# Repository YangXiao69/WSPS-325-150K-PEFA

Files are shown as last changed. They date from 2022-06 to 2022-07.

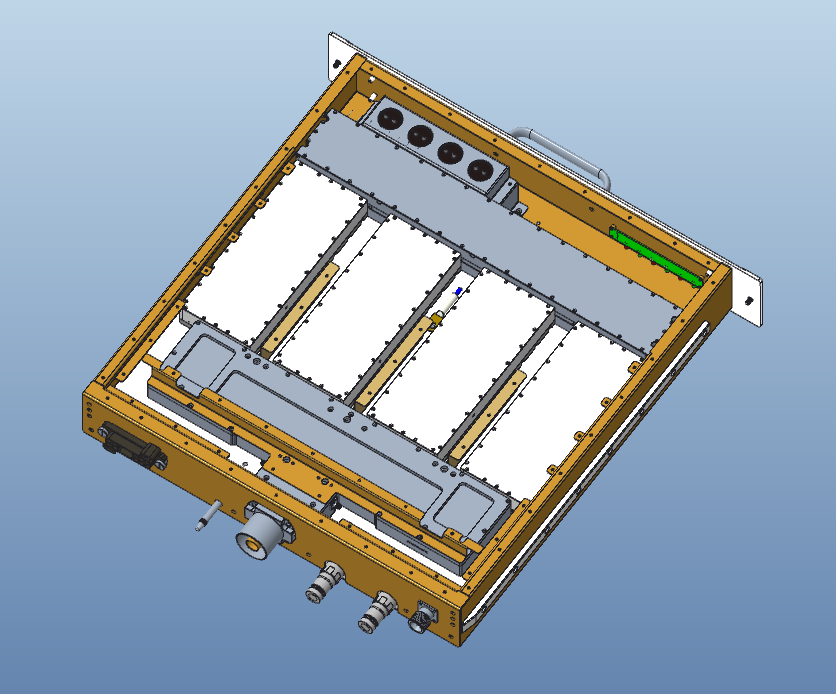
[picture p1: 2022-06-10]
接线图/功放插件/325-150KW功放插件截图/微信图片_20211231135349.png

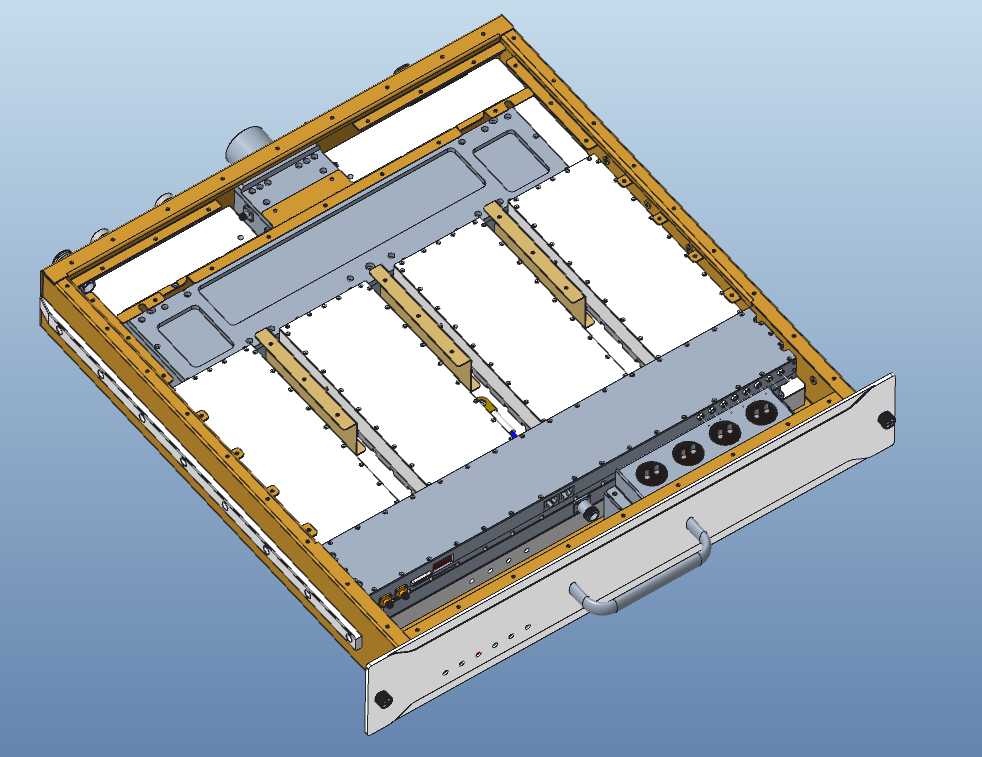
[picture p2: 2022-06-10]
接线图/功放插件/325-150KW功放插件截图/微信图片_20211231135400.png

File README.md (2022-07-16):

# WSPS-325-150K-PEF 开发记录

- 与昆仑通态组态屏交互协议
- pwm信号捕获
- 与工控机交互协议
- 激励温度采集

将udp的端口改为8096,**设想的插件通信方式，使用udp方式（可群发，可点对点），modbus协议，可脱离激励控制**

所有的校准参数保存到主控，保护判断也保存到主控

核达电源转接板，地址拨码开关左边是低位
## 问题

1. 激励级没有**拨码开关**
2. 主控和协处理器**飞线**
3. 工控机，交换机电源没有按接线图，功率是否足够

## 硬件问题
电磁阀驱动电阻过大 改为**10k**

流量计运放**飞线**

信号源修改

整机主控的UDP与驱动层的数据交互

## 数据分析

--->21   
<---01 00 09 C8 24 55 55 00 00 F4 00 00 93  
--->7F  
--->C1   
<---01   
--->00 04 C8 24 55 55 9A   
<---7F   
--->21   
<---01 00 09 C8 24 55 55 00 00 F4 00 00 93   
--->7F  
--->21   
<---73   
--->C1   
<---01   
--->00 04 C8 24 55 55 9A   
<---01 00 09 C8 24 55 55 00 00 F3 00 00 92   
--->7F  
--->21   
<---73   
--->C1

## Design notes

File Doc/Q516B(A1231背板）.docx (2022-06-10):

1. 尺寸图如下，以下两点尺寸没有变动

1）背板宽度与原背板保持相同；

2）安装螺钉孔位和开孔大小与原背板相同。

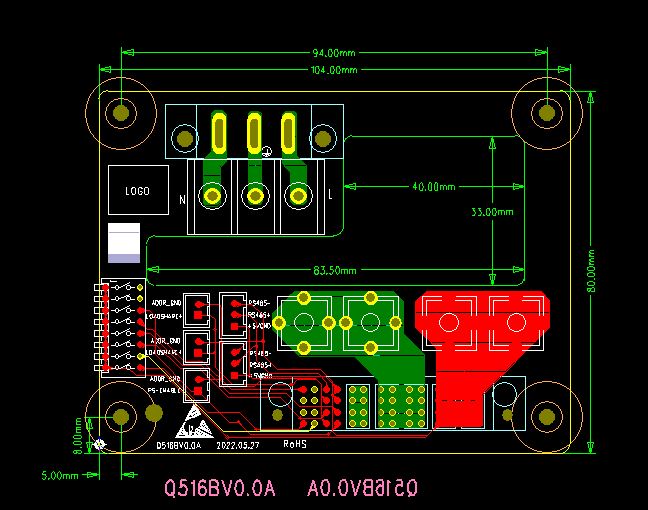
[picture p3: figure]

2. 接线布局如下（局部放大）

PCB板正面

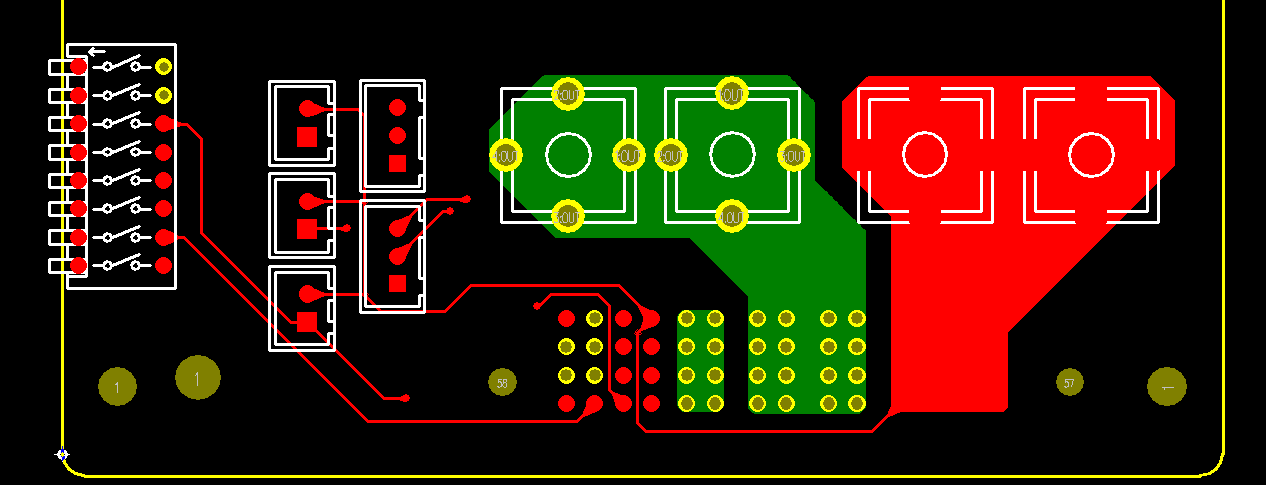
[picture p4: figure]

PCB板反面

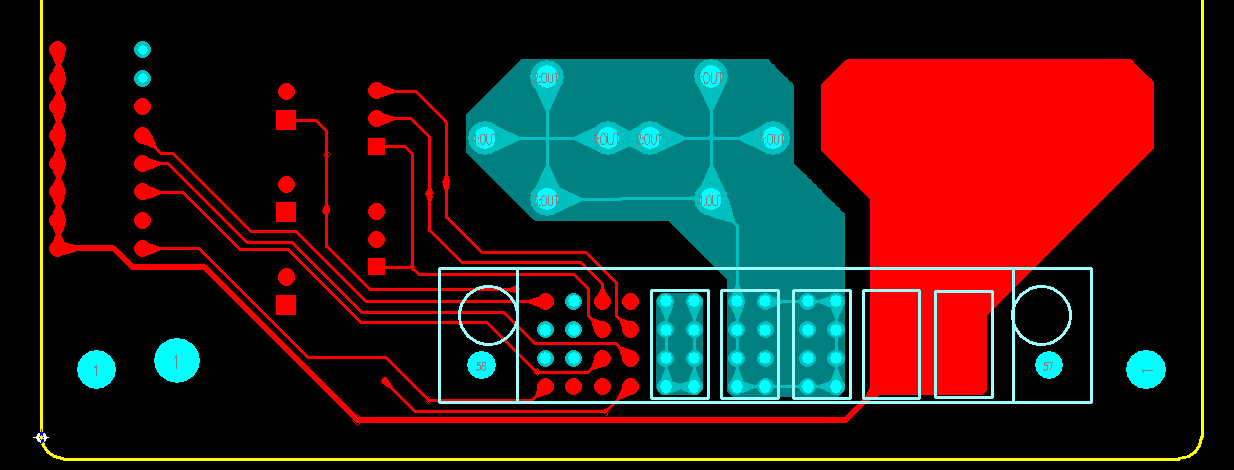
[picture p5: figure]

3. 弱电信号，单独留接口插座，地址码增加拨码开关（局部放大图如下）

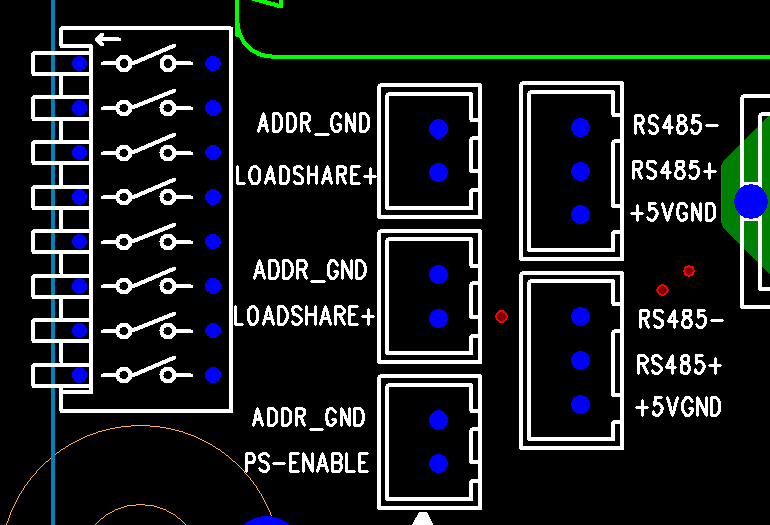
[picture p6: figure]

下图是3根485通讯线，两个座子之间相同信号互相短接（RS485+和RS485+短接、RS485-和RS485-短接、5VGND和5VGND短接）

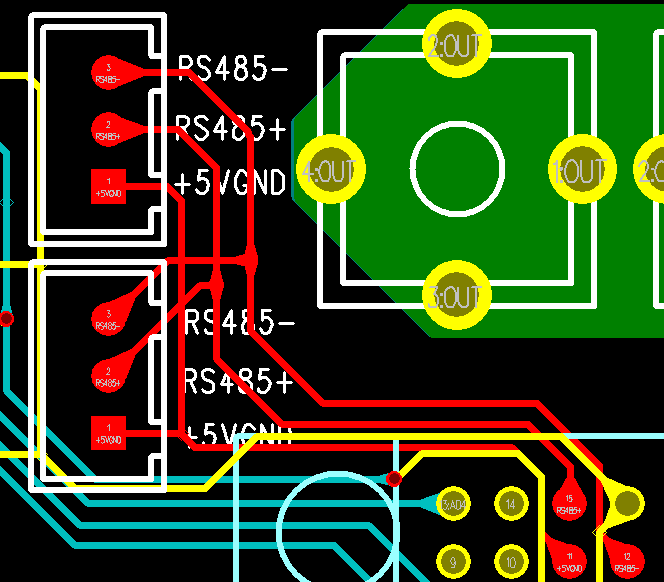
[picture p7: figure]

下图是2根均流母线电压线，同理也是LOADSHARE+与LOADSHARE+短接，ADDR-GND与ADDR-GND短接

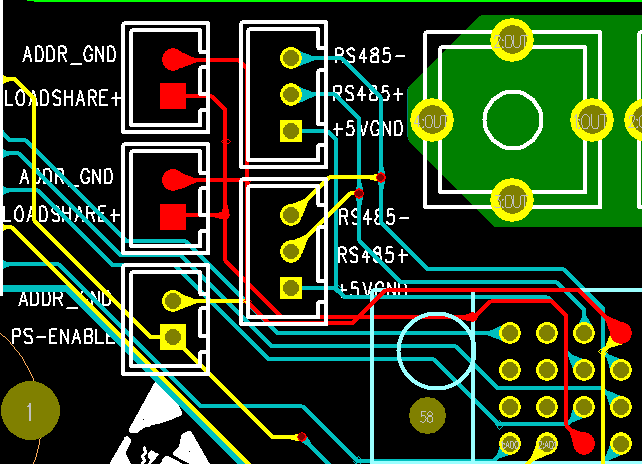
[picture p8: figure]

下图是5根地址线（A0-A4）接拨码开关

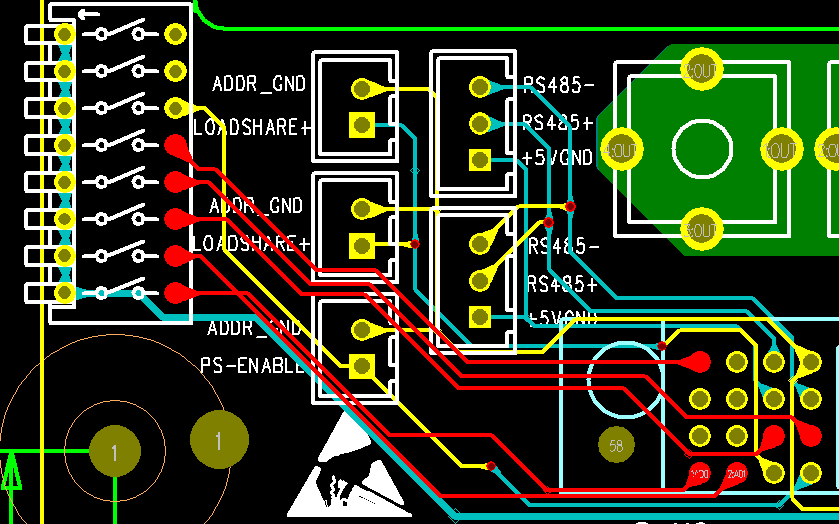
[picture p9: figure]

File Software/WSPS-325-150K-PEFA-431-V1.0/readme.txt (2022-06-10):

/**************2021.4.7 xiaoyang ************/
修改error_serve()函数：如果开启射频，再断电会导致电流误告警，所以将电流告警次数从20次增加到900次
/*******************************************/

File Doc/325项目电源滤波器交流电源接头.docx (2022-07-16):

325-150KW交流电源接头:

型号：插座：WP20K5Z 5芯 单芯载流：30A

插头：WP20J5TK 5芯 单芯载流：30A

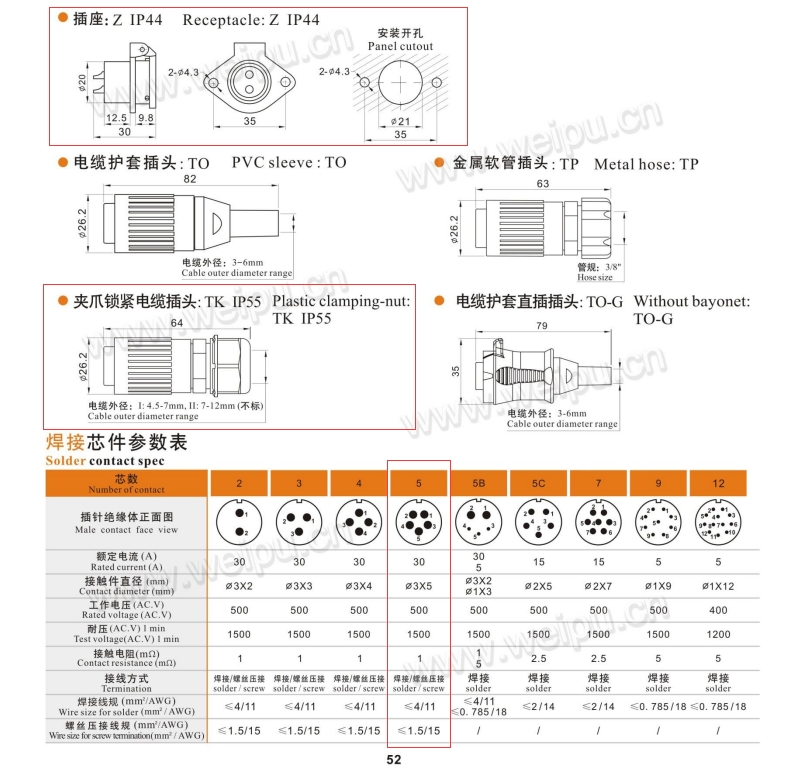
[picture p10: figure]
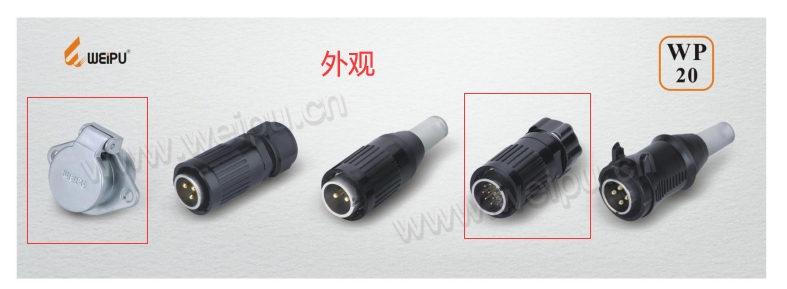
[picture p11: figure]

325-30KW交流电源接头:

型号：插座：WS48K5Z 5芯 单芯载流：100A

插头：WS48J5TQ 5芯 单芯载流：100A

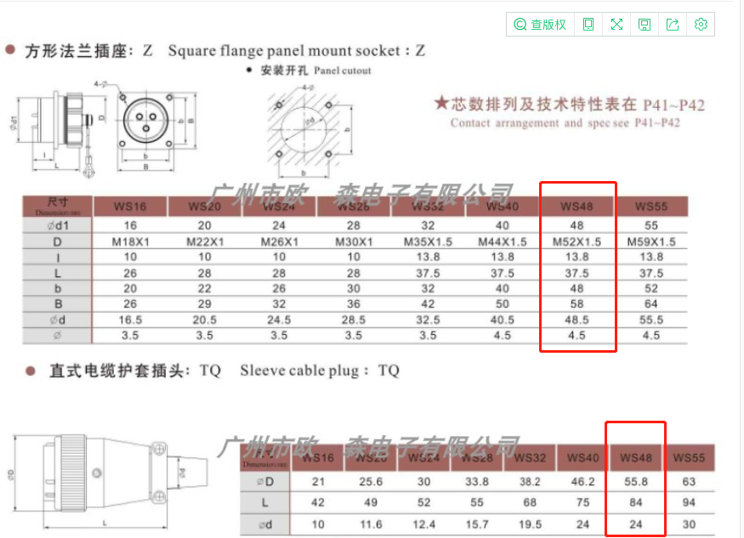
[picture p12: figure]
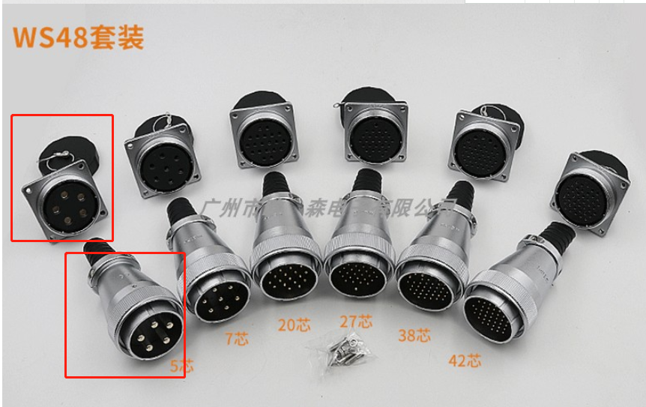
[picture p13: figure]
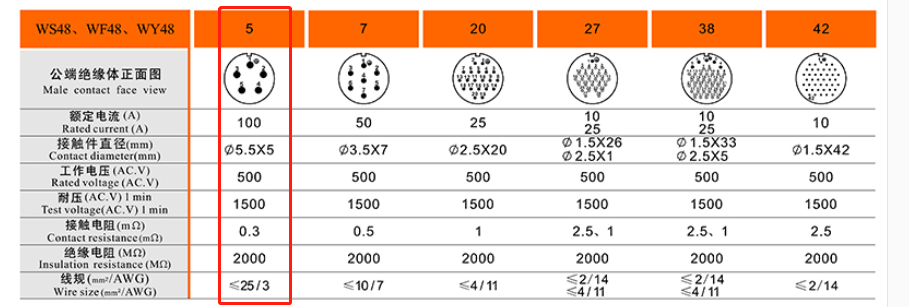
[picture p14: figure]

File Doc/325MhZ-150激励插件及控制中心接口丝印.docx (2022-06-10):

并柜总控单元结构示意图01

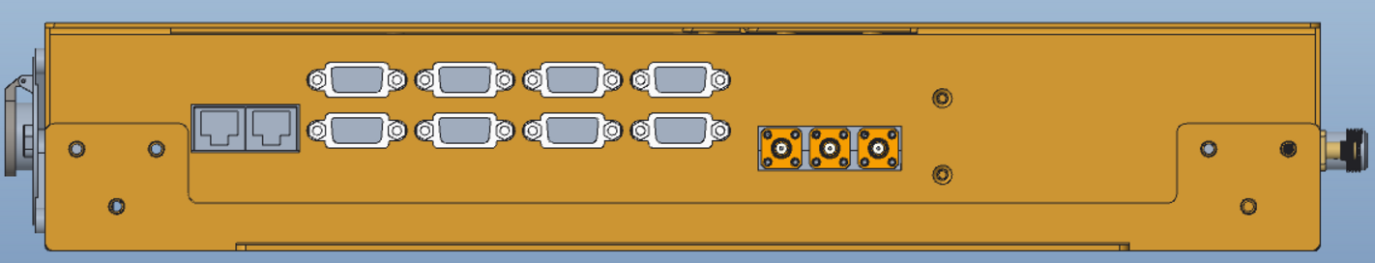
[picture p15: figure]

序号 | 丝印 | 连接器 | 描述
1 | LAN | RJ45 | 内部通信接口，接交换机
2 | LAN USER | RJ45 | 用户通信接口
3 | COMM1 | DB9双胞胎（上） | 机柜内部接口
4 | COMM2 | DB9双胞胎（下）
5 | COMM3 | DB9双胞胎（上） | 机柜内部接口
6 | COMM4 | DB9双胞胎（下）
7 | COMM5 | DB9双胞胎（上） | 机柜内部接口
8 | COMM6 | DB9双胞胎（下）
9 | COMM7 | DB9双胞胎（上） | 机柜内部接口
10 | COMM8 | DB9双胞胎（下）
11 | OPD | SMA | 整机输出检波口
12 | RPD | SMA | 整机反射检波口
13 | INPD | SMA | 整机输入检波口

并柜总控单元结构示意图02

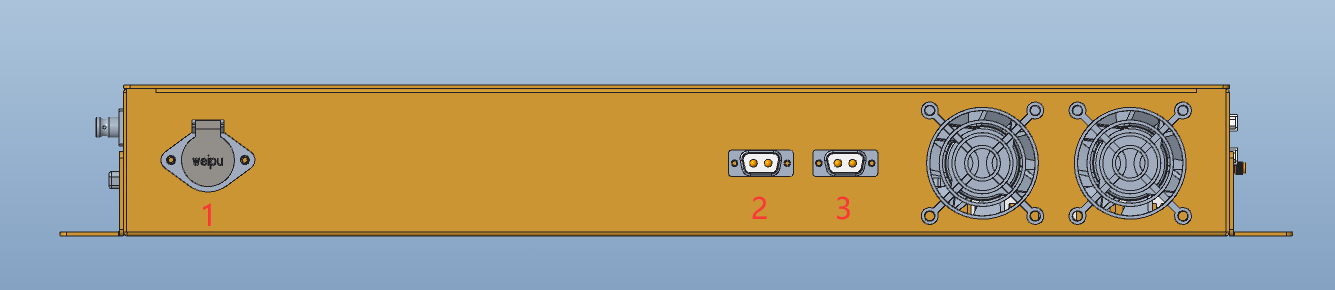
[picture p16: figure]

序号 | 丝印 | 连接器 | 描述
1 | AC IN | 航空插 | 交流供电输入接口
2 | 24VDC OUT1 | DB2 | 接工控机供电接口
3 | 24VDC OUT2 | DB2 | 接交换机供电接口

并柜总控单元结构示意图03

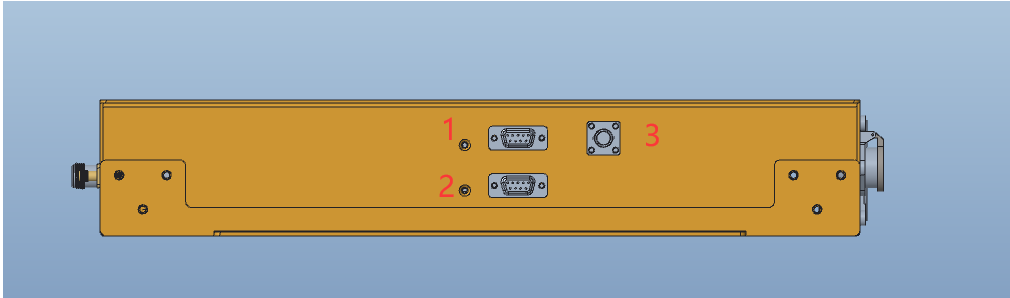
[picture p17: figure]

序号 | 丝印 | 定义 | 描述
1 | ALARM | DB9 | 一体三色告警灯
2 | COMM9 | DB9 | 预留
3 | PWM IN | BNC | PWM IN 输入

并柜总控单元结构示意图04

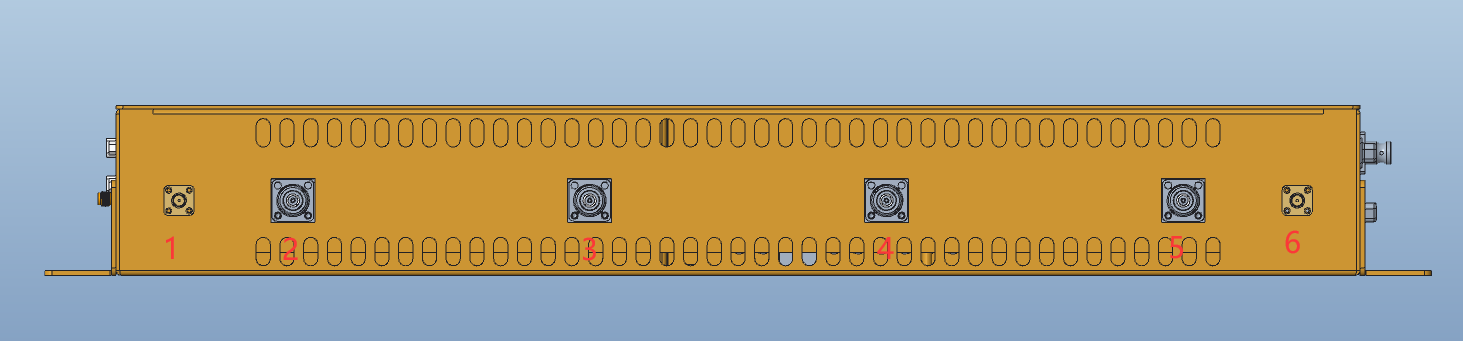
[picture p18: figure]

序号 | 丝印 | 定义 | 描述
1 | RF IN | SMA | 射频输入
2 | RF OUT1 | N头 | 射频输出
3 | RF OUT2 | N头 | 射频输出
4 | RF OUT3 | N头 | 射频输出
5 | RF OUT4 | N头 | 射频输出
6 | INPD OUT | SMA | 耦合输出口（接主控输入检波）

单柜激励插件

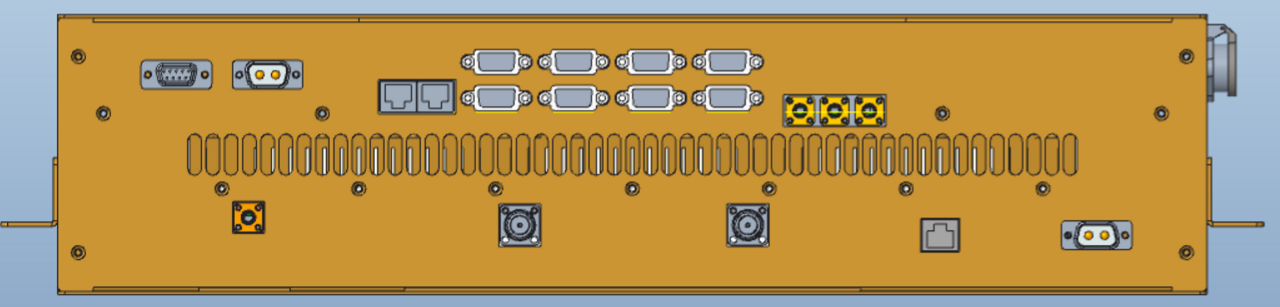
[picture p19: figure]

序号 | 丝印 | 连接器 | 描述
1 | STATE LED | DB9 | 3个金属灯
2 | 24VDC OUT | DB2 | 16口交换机
3 | LAN | RJ45 | 内部通信接口，接交换机
4 | LAN USER | RJ45 | 用户通信接口
5 | COMM1 | DB9双胞胎（上） | 机柜内部接口
6 | COMM2 | DB9双胞胎（下）
7 | COMM3 | DB9双胞胎（上） | 机柜内部接口
8 | COMM4 | DB9双胞胎（下）
9 | COMM5 | DB9双胞胎（上） | 机柜内部接口
10 | COMM6 | DB9双胞胎（下）
11 | COMM7 | DB9双胞胎（上） | 机柜内部接口
12 | COMM8 | DB9双胞胎（下）
13 | OPD | SMA | 单柜机柜输出检波口
14 | RPD | SMA | 单柜机柜反射检波口
15 | INPD | SMA | 预留

序号 | 丝印 | 定义 | 描述
1 | RF IN | SMA | 系统射频输入接口
2 | RF OUT1 | N | 射频输出
3 | RF OUT2 | N | 射频输出
4 | LAN | RJ45 | 接口板通信口，接16口交换机
5 | 50VDC IN | DB2 | 50V供电输入（驱动供电）

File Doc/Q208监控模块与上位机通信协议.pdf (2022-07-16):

## 深圳市核达中远通

电源技术有限公司 | 文 档 编 号 | 软件版本 | 文档密级
共 37 页 | | 1.00 | 机密

# 监控模块与上位机主从节点通讯协议

拟 | 制：吕志明
审 | 核：周友云
批 | 准：李战伟

第 2 页 共 49 页

目 录

第 3 页 共 49 页

第 4 页 共 49 页

第 5 页 共 49 页

## 监控模块与上位机主从节点通信协议

# 1 说明

本协议适用于各产品主控板（主节点）与电源系统监控模块（从节点）之间的通讯。

《协议》中规定的功能主要有：

1)主节点通过转发命令控制从节点完成指定任务；

2)主节点通过查询命令使从节点上报上电复位状态、告警信号改变后的告警量以及在转发命令

后从节点执行任务后的结果；

3)根据主节点的转发发命令执行指定任务，并将任务执行结果存于上报队列，等待主节点发送

查询命令时上报；

4)从节点将上电复位状态、告警信号改变后的告警量以及在转发命令时从节点执行任务后的上

报结果放在一个先进先出的上报队列中，每收到主节点发送的一个查询命令就返回上报队列中的第

一个信息，若上报队列为空，则返回无事响应字节（73H）。

通信的过程为单工、变长、双向应答确认方式进行，由主节点向从节点发送转发命令和查询命

令。每个转发命令和查询命令都作为一次双向通讯过程。多个从节点通过地址来区分，不同的从节

点对应不同的地址，不能有相同地址的从节点挂在同一条通讯总线上。

# 2 专用术语

主节点：业务框中的主控板，负责和各从节点进行通讯。也是上位机。

从节点：电源系统监控模块、风扇框中的监控板、直流配电框中的监控板均为从节点，它们和

主控板进行通讯。

RS422：一种 4 线串行通讯标准，可支持单工串行近程通讯；

转发命令：由主节点发向从节点使从节点完成指定任务的通讯格式；

查询命令：由主节点发向从节点使从节点返回上报队列中第一个消息的通讯格

式。

从节点地址：从节点地址用 5BIT 表示，可有 32 个不同的从节点地址。

第 6 页 共 49 页

# 3 物理接口

## 3.1 串行通信口电气标准

从节点以 RS422/RS232 方式通过主用串口或备用串口与主节点通讯

## 3.2 信息传输方式

采用异步方式，字节幀格式为：1个起始位，8个数据位，1个判断位，1个停止位。判断位为1

时表示地址幀，为0时表示数据幀。

字符信息传输方式为异步方式，1个起始位，8个数据位（信息字节），1个控制位（TB8），1

个停止位，共11位。 控制位可以是串口控制器的多机通信位TB8（8031），或是奇偶校验位（对大

多数 CPU 和 UART 芯片）。

从节点上报的数据第九位始终为0；

主节点的地址帧数据第九位为1，数据帧和应答数据第九位为0。

## 3.3 数据传输速率

波特率9600bps。

# 4 物理层通信方式

## 4.1 基本过程

·从节点上电或复位后，先清空上报队列，并把单板注册请求信息放于上报队列中，然后等待

主节点发出的查询命令，在成功收到主节点下发的注册响应命令之前，始终上报注册请求命令，注

册响应命令接收成功后，注册请求发送结束，以后不再产生此项上报信息。

·从节点接收到转发发命令时，将执行结果放在上报队列中。

·当告警状态发生变化时，从节点会产生一条告警状态改变上报信息放于上报队列中。

·接到查询命令后，若上报队列不空，则发送队列中第一个上报信息，否则发送无事响应（73H）。

·从节点通过主备两个串口与主节点通讯，上述过程对于主备串口将分别独立实现。

第 7 页 共 49 页

## 4.2 转发命令过程

转发命令过程如下：

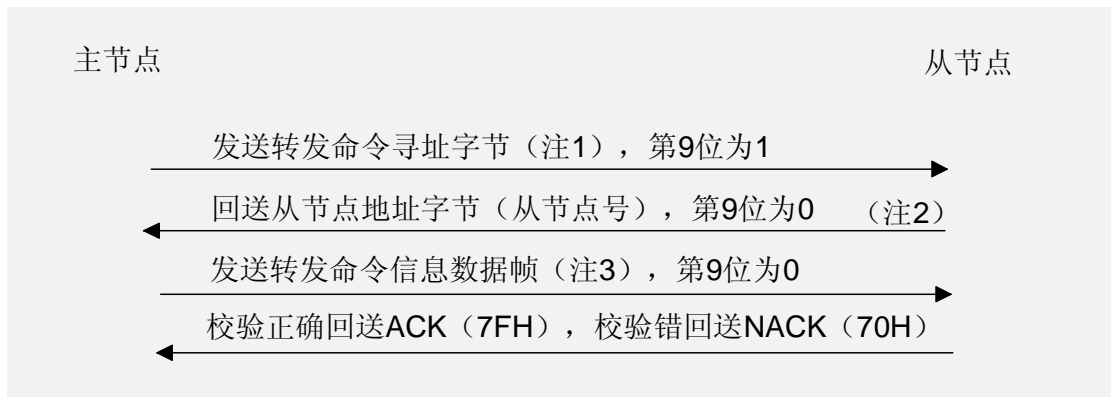
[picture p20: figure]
主节点; 从节点; 发送转发命令寻址字节（注1），第9位为1; 回送从节点地址字节（从节点号），第9位为0; 发送转发命令信息数据帧（注3），第9位为0; 校验正确回送ACK（7FH），校验错回送NACK（70H）

主节点下发转发命令寻址字节时，如果重发次数为0，则置转发命令高三位重发标志为“110”

表示为首次发送，否则为“111”表示为重发。

注1：命令寻址字节格式如下：
BIT： | 7 | 6 | 5 | 4 | 3 | 2 | 1 | 0
| | | | | | 从节点地址
1 | 1 | 0 首次发送
1 | 1 | 1 重发（非首次发送）

注2：回送从节点地址字节数据格式如下：
BIT： | 7 | 6 | 5 | 4 | 3 | 2 | 1 | 0
0 | 0 | 0 | 从节点地址

注3：转发命令信息数据帧格式如下：

| 长度 | 命令 | | | 信息域 | | | 校验字

其中：

长度：2 个字节的整形数，第一个字节为高位字节。指明 命令字 + 信息域 的长度。

命令： 2 个字节，命令的信息，第一个字节代表单板类型，定义如下：

| | | 电源模块：0xc8

第 8 页 共 49 页

电源系统监控模块：0xc9

风扇监控板：0xca

配电监控板：0xcb；

第二个代表命令定义。

Handle：2 个字节。

信息域：命令的信息域，第 1、2 个字节为 Handle 握手字。

校验字： 1 个字节，为长度、命令、 信息域的累加和。

从节点上电后，一直处于接收地址（第 9 位为 1）状态，收到地址后，与本机地址比较，若相

同并为转发命令，则回送本机地址，并转为接收数据（第 9 位为 0）状态；若相同并为查询命令，

则按查询处理；若不相同，则退出，仍然处于接收地址（第 9 位为 1）状态。

转发命令时，若从节点回送的地址不对或超时(10ms)不回送从节点地址，主机应重发，重发次

数以 3 次为限，3 次失败则判本次通信失败。

转发命令从节点接收数据时，只有在校验正确或校验错时才回送确认信息（ACK/NACK）；若

接收的长度和命令与协议定义的不符合，不回送信息，判本次通信失败，进入接收地址（第 9 位为

1）状态；若接收通信帧数据时收到地址（第 9 位为 1），判本次通信失败，并与本机的地址比较，

若相同并为转发命令，则按转发命令处理；若相同并为查询命令，则按查询命令处理；若不相同，

则退出，改为接收地址（第 9 位为 1）状态。

转发命令主节点发完数据帧后，准备接收从机的确认信息（ACK/NACK），如超时(10ms)或校

验错（NACK），判通信失败，主节点应从重发转发命令寻址字节开始，重新通信，重发次数以 3 次

为限，3 次失败则判本次通信失败。

## 4.3 查询命令过程

查询命令格式如下：

第 9 页 共 49 页

主节点下发查询命令寻址字节，从节点接到且是访问本机后，若无信息上报，则上报无事相应；

有信息上报，则取出一条上报，如果重发次数为0，则置数据帧地址字节高三位重发标志为“000”

表示首次上报，否则为“001”表示重报相应。

注4：查询命令寻址字节格式如下：
BIT： | 7 | 6 | 5 | 4 | 3 | 2 | 1 | 0
0 | 0 | 1 | 从节点地址

注5：上报信息数据帧格式如下：

上报地址 | 长度 | 命令 | 信息域 | 校验字

其中：

上报地址： 1 个字节。字节格式如下：
BIT： | 7 | 6 | 5 | 4 | 3 | 2 | 1 | 0

从节点地址

0 | 0 | 0 首次上报
0 | 0 | 1 重报（非首次上报）

长度： 2 个字节的整形数，第一个字节为高位字节，等于 命令字 + 信息域

命令： 2 个字节，命令的信息，第一个字节代表单板类型；第二个代表命令信息。

信息域： 命令的参数，第一个和第二个字节为 Handle 握手字节，由转发命令产生的上报信息

时为转发命令时的内容（填充时拷贝转发命令的握手字节），主动产生的上报信息为 0xffff。

校验字： 1 个字节，为长度、命令、 信息域的累加。

主节点 | 从节点

发送查询命令寻址字节（注4），第9位为1

回送上报信息数据帧，第9位为0（注5）

| 校验正确回送ACK（7FH），校验错回送NACK（70H）

结束

第 10 页 共 49 页

主节点下发查询命令寻址字节（第 9 位为 1）后，处于接收状态。接收等待超时 (10ms)，则重

新开始查询命令，重新通信，重发次数以 3 次为限，3 次失败则判本次通信失败。

主节点若接收的首字节不是无事响应字节，也不是当前的从节点号或重报标志不正确、或长度

字节非法、或命令字节非法，则重新开始查询命令，重新通信，重发次数以 3 次为限，3 次失败则

判本次通信失败。

主节点接收到第一个数据后，判断该数据为无事响应（73H），通信结束。若不是，则处于接收

数据状态，接收数据结束后，经校验出错，则回送确认校验错（NACK），并丢却接收的数据，置等

重报标志，重新处于接收状态，3 次失败则判本次通信失败。

主节点若接收到的数据，经校验正确，则回送确认校验对（ACK），通信结束。

从节点上电后，一直处于接收地址（第 9 位为 1）状态，收到地址后，与本机的地址比较，若

相同并为查询命令，单盘无事，则只回一个字节（73H），本次通信结束，进入接收地址（第 9 位为

1）状态。如单盘有消息上报，则发数据帧，发完后，须等待主节点回送确认信息（ACK/NACK）。

从节点等待确认信息时若收到确认校验对（ACK），本次通信结束，处于接收地址（第 9 位为 1）

状态；若收到确认校验错（NACK），则重发数据帧，发完后，须等待主节点回送确认信息

（ACK/NACK）；若收到其他数据，判通信失败，保留数据帧的信息，等待下次的查询，并改为处

于接收地址（第 9 位为 1）状态；若接收到第 9 位为 1 的单盘号，判通信失败，保留数据帧的信息，

并与本盘的地址比较，若相同并为查询命令，则按查询处理，若相同并为下发命令，则按下发命令

处理，若不相同，则退出，处于接收地址（第 9 位为 1）状态。

# 5 应用层信息类型及格式

## 5.1 命令编码

从节点与主节点的通讯共有两种命令编码即：

(a) 转发命令编码：在转发命令通讯过程中标识主节点要求从节点执行的任务内容
(b) 查询命令编码：在查询命令通讯过程中标识从节点返回主节点的上报信息内

容

第 11 页 共 49 页

转发命
令编码
含义 | 查询命 令编码

含义

电源系统监控模块命令字编码（公有命令）
0xc901 | 单板注册响应 | 0xc901 | 单板注册请求上报
0xc902 | 获取单板版本 | 0xc902 | 单板版本上报
0xc903 | 单板复位命令 | 0xc903 | 单板准备复位上报
电源系统监控模块命令字编码（私有命令）
0xc920 | 获取配电模拟量 | 0xc920 | 配电模拟量上报
0xc921 | 获取环境模拟量 | 0xc921 | 环境模拟量上报
0xc923 | 获取备用模拟量 | 0xc923 | 备用模拟量上报
0xc930 | 获取告警量 | 0xc930 | 告警量上报
0xc940 | 获取状态量 | 0xc940 | 状态量上报
0xc950 | 获取整流模块生产日期 | 0xc940 | 整流模块生产日期上报
0xc951 | 获取蓄电池充放电次数 | 0xc951 | 蓄电池充放电次数上报
0xc980 | 设置电源系统控制参数 | 0xc980 | 电源系统控制参数设置结果上报
0xc981 | 设置均浮充电压 | 0xc981 | 均浮充电压设置结果上报
0xc982 | 设置电池管理参数 | 0xc982 | 电池管理参数设置结果上报
0xc983 | 设置下电参数 | 0xc983 | 下电参数设置结果上报
0xc985 | 设置电池组温度补偿参数 | 0xc985 | 电池组温度补偿参数设置结果上报
0xc986 | 设置电源模块参数 | 0xc986 | 电源模块参数设置结果上报
0xc987 | 设置配电参数 | 0xc987 | 配电参数设置结果上报
0xc988 | 设置环境参数 | 0xc988 | 环境参数设置结果上报
0xc989 | 设置备用量参数 | 0xc989 | 备用量参数设置结果上报
0xc98a | 设置高温下电保护参数 | 0xc98a | 高温下电保护参数设置结果上报
0xc98b | 获取高温下电保护参数 | 0xc98b | 获取高温下电保护参数结果上报
0xc98c | 设置电池组容量检测参数 | 0xc98c | 电池组容量检测参数上报
0xc98d | 获取电池组容量检测参数 | 0xc98d | 电池组容量检测参数上报
0xc98e | 获取协议扩展参数 | 0xc98e | 协议扩展参数上报
0xc98f | 设置协议扩展参数 | 0xc98f | 协议扩展参数设置结果上报
0xc990 | 获取电源系统控制参数 | 0xc990 | 电源系统控制参数上报
0xc991 | 获取均浮充电压 | 0xc991 | 均浮充电压参数上报
0xc992 | 获取电池管理参数 | 0xc992 | 电池管理参数上报
0xc993 | 获取下电参数 | 0xc993 | 下电参数上报
0xc994 | 获取分流器参数 | 0xc994 | 分流器参数上报（2005-1-28 删除）
0xc995 | 获取电池组温度补偿参数 | 0xc995 | 电池组温度补偿参数上报
0xc996 | 获取电源模块参数 | 0xc996 | 电源模块参数上报
0xc997 | 获取配电参数 | 0xc997 | 配电参数上报

第 12 页 共 49 页

0xc998 | 获取环境参数 | 0xc998 | 环境参数上报
0xc999 | 获取备用量配置参数 | 0xc999 | 备用量配置参数上报
0xc99b | 设置电压测量参考基准 | 0xc99b | 设置电压测量参考基准结果上报
0xc99c | 设置配电模拟量校准系数 | 0xc99c | 设置配电模拟量校准系数结果上报
0xc99d | 启动或终止蓄电池立即测试 | 0xc99d | 启动或终止蓄电池立即测试结果上报
0xc99e | 设置各告警量告警级别 | 0xc99e | 设置各告警量告警级别结果上报
0xc99f | 获取各告警量告警级别 | 0xc99f | 各告警量告警级别上报
0xc9a0 | 获取电池放电测试结果 | 0xc9a0 | 电池放电测试结果上报
0xc9a1 | 获取配电模拟量校准系数 | 0xc9a1 | 配电模拟量校准系数上报
0xc9a2 | 获取单板生产日期和厂家信息 | 0xc9a2 | 获取单板生产日期和厂家信息上报
0xc9a3 | 设置当前时间 | 0xc9a3 | 设置当前时间结果上报
0xc9a4 | 获取当前时间 | 0xc9a4 | 当前时间上报
0xc9a5 | 设置蓄电池安装时间 | 0xc9a5 | 设置蓄电池安装时间上报
0xc9a6 | 获取蓄电池安装时间 | 0xc9a6 | 蓄电池安装时间上报
0xc9aa | 配置参数恢复缺省值 | 0xc9aa | 恢复缺省值结果上报
0xc9ab | 设置蓄电池自动测试参数 | 0xc9ab | 设置蓄电池自动测试参数上报
0xc9ac | 查询蓄电池自动测试参数 | 0xc9ab | 查询蓄电池自动测试参数上报
0xc9ad | 烟雾告警复位命令 | 0xc9ad | 烟雾告警准备复位上报
0xc9ae | 关闭或复位电源输出命令 | 0xc9ae | 准备关闭或复位电源输出上报
0xc9af | 设置电源系统参数 | 0xc9af | 设置电源系统参数结果上报
0xc9b0 | 获取电源系统参数 | 0xc9b0 | 获取电源系统参数结果上报

注：0xc9f8～0xc9fe预留给供应商进行内部命令设置，协议不能占用。其中0xc9f8作为整流模块输

出信息查询，具体定义参加附录I。2005-10-19增加

第 13 页 共 49 页

信息域的数据格式

在转发命令中，信息域提供了命令执行的具体参数；在查询命令中，信息域包含了所需上报的具体

数据。

信息域中的数据由单字节数(8Bits)、浮点数(32Bits，数据格式为附录A规定的标准C浮点数格式)组成，

按发送的先后次序依次存放。应当注意的是：在传送浮点数时，按阶码字节、尾数高位字节、尾数

中位字节、尾数低位字节顺序发送；所有字节都按十六进制方式直接发送。

为了简化参数设置和控制命令的执行过程，除了特别说明的命令外，规定若参数域中的某数据为

0xff(单字节数)或0xffffffff(四字节浮点数)，则表示本次命令不涉及此数据对应的信号或配置参

数，该信号的状态或该项配置参数保持不变。

所有命令中定义为保留的字节和数据规定为0xff(单字节数)或0xffffffff(四字节浮点数)。

对于主节点下发设置和控制命令，除该命令有特殊说明外，从节点返回值定义如下：

0：执行成功

1：数据无效（包括命令ID无法识别和参数错误）

2：操作失败（如写EEPROM芯片失败、无权限获取等）。

# 6 信息格式

## 6.1 电源监控模块命令

## 6.1.1 单板注册请求

在单板上电或单板复位重新启动后，主动产生本命令，产生的上报命令，放入单板的发送队列，

等收到主节点的查询命令后，再上报。主节点依照这条命令，获知单板复位完成和单板状态，并通

过转发命令向单板下发注册响应命令。当单板没有收到注册响应转发命令之前，对于主节点的查询

命令始终上报单板注册请求命令。单板接收到注册响应转发命令成功后以后不再上报注册请求命

令。

转发命令 | 命令 | 0xc901 | 长度 | 0x0004
| 信息域 | Handle 握手字（2 个字节）
查询命令 | 命令 | 0xc901 | 长度 | 0x000d

第 14 页 共 49 页

信息域 | 握手字（2 个字节，0xffff）； 应答结果（1 个字节）； 单板自检状态（1 个字节，0x00，表示好，其它，表示坏）； 电源系统类型（1 字节）； 软件小版本号（1 个字节）； 硬件 PCB 版本号（1 个字节）； 硬件可编程器件版本号（1 个字节）； 编译时间年（1 个字节）； 编译时间月（1 个字节）； 编译时间日（1 个字节）

说明：

在查询命令的信息域中规定：

电源系统类型：填“1”代表-48V电源系统；填“2”代表24V电源系统。

软件小版本号：填大于等于0的值，首次发布版本填0，第二次为1，类推；应用时，主节点（主控

板）需按照下表进行解析：

从节点（电源监控板）软件版本格式 | 主节点（主控板）解析显示格式
软件大版本 | 软件小版本
1 | 01～0f | 101~115
1 | 10~ | 116

硬件的PCB版本在没有归档之前填“A”（“0”2005-1-26删除），首次归档填“A”，按照A，B，C……

的方式递增。

硬件可编程器件版本（EPLD，CPLD，FPGA等）：首次发布版本为1，按照1，2，3……的方式递增。

编译时间：十六进制格式，其中“编译时间年”取年份的最后两位数字。

## 6.1.2 获取单板版本信息

在主节点向从节点发获取单板版本下发命令后，从节点产生一条单板版本信息上报命令，放入

发送队列，在收到主节点的查询命令后上报。

转发命令 | 命令 | 0xc902 | 长度 | 0x0004
| 信息域 | 握手字（2 个字节）
查询命令 | 命令 | 0xc902 | 长度 | 0x002d

第 15 页 共 49 页

信息域 | 握手字（2 个字节）； 应答结果（1 个字节）； 软件大版本号（1 个字节）； 软件小版本号（1 个字节）； 硬件 PCB 版本号（1 个字节）； 硬件可编程器件版本号（1 个字节）； 编译时间年（1 个字节）； 编译时间月（1 个字节）； 编译时间日（1 个字节）； 版本说明（32 个字节）； 厂家类型（1 个字节）

说明：

1、其中版本说明、编译时间和注册命令中的一致；

2、版本说明为附加的单板说明信息，可自由定义。

3、厂家类型：填入厂家的代码。

## 6.1.3单板复位命令

由主节点向从节点发单板复位转发命令。

从节点在收到主节点发的单板复位转发命令后，产生一条上报命令，等主节点发查询命令时上

报，上报成功后开始复位。

转发命令 | 命令 | 0xc903 | 长度 | 0x0004
| 信息域 | 握手字（2 个字节）
查询命令 | 命令 | 0xc903 | 长度 | x0005
| 信息域 | 握手字（2 个字节）；应答结果（1 个字节）

## 6.1.4 获取配电模拟参数

主节点向从节点发获取配电模拟参数转发命令。

从节点在收到主节点发的获取配电模拟参数转发命令后，产生一条配电模拟参数上报命令，等

主节点发查询命令时上报。

转发命令 | 命令 | 0xc920 | 长度 | 0x0004
| 信息域 | 握手字（2 个字节）
查询命令 | 命令 | 0xc920 | 长度 | 0x0019

第 16 页 共 49 页

信息域 | 握手字（2 个字节）； 应答结果（1 个字节）； 母排电压（4 字节浮点数）；负载总电流（4 字节浮点数）；蓄电池组 1 电 流（4 字节浮点数）；蓄电池组 2 电流（保留，4 个字节）；交 流电压（4 字节浮点数）；

## 6.1.5 获取环境模拟参数

主节点向从节点发获取环境模拟参数转发命令。

从节点在收到主节点发的获取环境模拟参数转发命令后，产生一条环境模拟参数上报命令，等

主节点发查询命令时上报。

转发命令 | 命令 | 0xc921 | 长度 | 0x0004
| 信息域 | 握手字（2 个字节）
查询命令 | 命令 | 0xc921 | 长度 | 0x0021
| 信息域 | 握手字（2 个字节）； 应答结果（1 个字节）；电池组温度 1 （4 字节浮点数）；环境温度 1（4 字节浮点数）；环境湿度（4 字节浮点数）；环境温度 2（保留，4 字节浮点数）（2005-10-19 更改），电池组温度 2（4 字节浮点数）；保留（8 个字节）

注：温度传感器无效时，模拟量上报0xffffffff。

## 6.1.6 获取备用模拟量参数

主节点向从节点发获取备用模拟参数转发命令。

从节点在收到主节点发的获取备用模拟参数转发命令后，产生一条备用模拟参数上报命令，等

主节点发查询命令时上报。备用模拟参数主要用于调试和功能扩充。

转发命令 | 命令 | 0xc923 | 长度 | 0x0004
| 信息域 | 握手字（2 个字节）
查询命令 | 命令 | 0xc923 | 长度 | 0x002d
| 信息域 | 握手字（2 个字节）； 应答结果（1 个字节）； 备用 1（4 字 节浮点数）；备用 2（4 字节浮点数）；备用 3（4 字节浮点数）； 备用 4（4 字节浮点数）；备用 5（4 字节浮点数）；备用 6（4 字节浮点数）；备用 7（4 字节浮点数）；备用 8（4 字节浮点 数）；备用 9（4 字节浮点数）；备用 10（4 字节浮点数）

注意：备用 1－限流点电流；备用 2－后台控制整流模块的输出电压；其它保留。

## 6.1.7 获取告警量

主节点向从节点发获取告警状态转发命令。

从节点上电或复位重启后，产生一条告警状态上报命令；或者从节点在收到主节点发的获取告

第 17 页 共 49 页

警状态转发命令后，产生一条告警状态上报命令；另外，从节点在检测到告警状态发生变化后，也

应产生一条告警状态上报命令。产生的告警状态上报命令，放入单板的发送队列，等收到主节点的

查询命令后，再上报。

下发命令 | 命令 | 0xc930 | 长度 | 0x0004
| 信息域 | 握手字（2 个字节）
查询命令 | 命令 | 0xc930 | 长度 | 0x002B
信息域 | 握手字（2 个字节）；应答结果（1 个字节）；市电状态（1 个字 节）；市电过欠压（1 个字节）；母排电压过欠压（1 个字节）； 负载上下电（1 个字节）；电池上下电（1 个字节）；电池组回路 通断（1 个字节）；环境温度 1 告警（1 个字节）；环境湿度告警 （1 个字节）；电池组温度告警（1 个字节）；门磁告警（1 个字 节）；水浸告警（1 个字节）；烟感告警（1 个字节）；系统插框 槽位 1-10 电源模块告警（每个模块 1 个字节，共 10 字节）；充 电过流告警(1 个字节)；交流防雷故障（保留，1 个字节）；传感 器有效状态（1 个字节， BIT0－BIT4 分别对应电池组温度 1、环 境湿度、环境温度 1、环境温度 2、电池组温度 2，0 表示正常，1 表示无效；BIT5－BIT7 保留）；备用模拟量告警（1 个字节，用 于蓄电池不平衡告警）；开关量告警 1（1 个字节， BIT0—BIT6 分别对应备用开关量 1—7 状态，0 表示正常，1 表示告警；BIT7 保留）；开关量告警 2（1 个字节，BIT0—BIT3 分别表示负载熔 丝告警，0 表示正常，1 表示告警，BIT4～BIT7 保留）；保留（10 个字节）环境温度 2告警（1个字节）；保留（9个字节）（2005-10-19 更改）

注：

1、报警状态的信息域字节位定义见附录C（重点注意负载上下电和电池上下电告警定义）

2、电池组温度告警参考温度以蓄电池组温度补偿依据的温度为准。

## 6.1.8获取状态量

主节点向从节点发获取状态量转发命令。

从节点上电或复位重启后，产生一条状态量上报命令；或者从节点在收到主节点发的获取状态

量转发命令后，产生一条状态量上报命令；另外，状态量发生变化后，产生一条状态量上报命令。

产生的状态上报命令，放入单板的发送队列，等主节点发查询命令时上报。

下发命令 | 命令 | 0xc940 | 长度 | 0x0004
| 信息域 | 握手字（2 个字节）
查询命令 | 命令 | 0xc940 | 长度 | 0x002b

第 18 页 共 49 页

信息域 | 握手字（2 个字节）； 应答结果（1 个字节）；限流状态 （1 个字节）；电源系统控制命令受控状态（1 个字节）； 充放电状态（1 个字节）；负载下电允许状态（1 个字节）； 电池下电允许状态（1 个字节）；电池放电测试阶段（1 字节）；电源模块类型（1 个字节）；电源模块数量（1 个字节）；电源模块 1-10 插槽位置（保留，每个模块 1 个字节，共 10 字节）；保留（20 个字节）

注：信息域状态定义见附录B

未配置蓄电池时，充放电状态应为浮充。2005-6-30

## 6.1.9 获取整流模块生产日期

主节点向从节点发获取整流模块生产日期转发命令。

从节点在收到主节点发的获取整流模块生产日期转发命令后，产生一条整流模块生产日期上报

命令；产生的整流模块生产日期上报命令，放入单板的发送队列，等收到主节点的查询命令后，再

上报。

下发命令 | 命令 | 0xc950 | 长度 | 0x0004
| 信息域 | 握手字（2 个字节）
查询命令 | 命令 | 0xc950 | 长度 | 0x0037
| 信息域 | 握手字（2 个字节）；应答结果（1 个字节）；整流模块生产日期 （共 50 个字节，整流模块槽位 1 个字节，生产日期 3 个字节，生 产厂家编码 1 个字节，共 10 个整流模块）

注：信息域。定义见附录D。

## 6.1.10获取蓄电池充放电次数

主节点向从节点发获取蓄电池充放电次数转发命令。

从节点在收到主节点发的获取蓄电池充放电次数转发命令后，产生一条蓄电池充放电次数上报

命令；产生的蓄电池充放电次数上报命令，放入单板的发送队列，等收到主节点的查询命令后，再

上报。

下发命令 | 命令 | 0xc951 | 长度 | 0x0004
| 信息域 | 握手字（2 个字节）
查询命令 | 命令 | 0xc950 | 长度 | 0x002f
| 信息域 | 握手字（2 个字节）；应答结果（1 个字节）；蓄电池充放电次数 （42 个字节，停电次数 2 个字节，充电次数 20 个字节，放电次 数 20 个字节）

第 19 页 共 49 页

注：信息域定义见附录E。

## 6.1.11设置电源系统控制参数

主节点通过向从节点发设置均浮充等控制参数命令，设置从节点的均浮充受控状态、受后台控

制时的充电状态等。

从节点接收成功后根据转发命令参数域信息设置相应参数，并产生一条应答上报命令，放入发

送队列，等收到主节点的查询命令后，再将设置结果上报。

下发命令 | 命令 | 0xc980 | 长度 | 0x001c
| 信息域 | 握手字（2 个字节）；受控状态（1 个字节，AAH－主节点控制， 55H－从节点自动控制）；充电状态（1 个字节，AAH－均充，55H －浮充）；负载上下电控制(1 个字节，AAH-下电，55H-上电)； 电 池上下电控制(1 个字节，AAH-下电状态，55H-上电状态)；电源 模块开关机命令（1 个字节，AAH-关机；55H-开机）；保留（19 个字节）
查询命令 | 命令 | 0xc980 | 长度 | 0x0005
| 信息域 | 握手字（2 个字节）；应答结果（1 个字节）

注：

1、 电池放电测试期间不可以修改电源系统受控状态，反馈配置失败。

2、 从节点自动控制状态设置均充或者下电或者关机时返回配置参数无效。

3、 主节点控制状态但禁止下电时下发下电控制命令返回配置参数无效。

4、 对负载高温下电说明如下（2005-3-26 增加）：

前提条件：监控模块不自动进行负载的高温下电保护，负载高温下电只能由后台（或上位机）控制下电。

⑴上位机检测到负载温度过高时，必须首先获得监控模块的后台控制权，然后使能负载下电允许。

⑵后台下发负载下电命令，监控模块收到下电命令后无条件进行负载下电。（不管是高温还是常温）

⑶当监控模块和上位机通讯正常时，下电后的监控模块控制负载再次上电的权利由上位机控制，监控模块即使检测

到负载温度（暂定为环境温度1）低于负载高温保护温度10度以下也不会进行负载上电。

⑷当监控模块与上位机通讯断连时，监控模块首先判断是否负载高温下电使能（用于判断是否为高温负载下电），

如果禁止（非高温负载下电），则监控模块不进行负载上电。如果允许（是高温下电），则由监控模块检测负载温

度，一旦负载温度低于负载高温保护温度10度以下，则自动进行负载上电。

5、 主节点控制转到从节点控制的参数补充说明：

当从主节点控制方式转为从节点自动控制方式时，监控模块只接受该下发命令的受控状态参数，其

第 20 页 共 49 页

他参数均忽略。2005-6-28

## 6.1.12设置均浮充电压

主节点通过向从节点发设置均浮充电压转发命令，设置从节点的均浮充电压。

从节点接收成功后根据转发命令参数域信息设置相应参数，并产生一条应答上报命令，放入发

送队列，等收到主节点的查询命令后，再将设置结果上报。

下发命令 | 命令 | 0xc981 | 长度 | 0x000c
| 信息域 | 握手字（2 个字节）；均充电压（4 字节浮点数，有效范围 43.2~57.6， 且大于浮充电压小于直流过压告警点-1V，缺省 56.5V）；浮充电 压（4 字节浮点数，有效范围 43.2~57.6，且大于(直流欠压告警 点+2)V 小于均充电压，缺省 53.5V）
查询命令 | 命令 | 0xc981 | 长度 | 0x0005
| 信息域 | 握手字（2 个字节）；应答结果（1 个字节）

## 6.1.13设置电池管理参数

主节点通过向从节点发设置电池管理参数转发命令，设置从节点的电池管理参数。

从节点接收成功后根据转发命令参数域信息设置相应参数，并产生一条应答上报命令，放入发

送队列，等收到主节点的查询命令后，再将设置结果上报。

下发命令 | 命令 | 0xc982 | 长度 | 0x0012
| 信息域 | 握手字（2 个字节）；充电限流点系数（4 字节浮点数，有效范围 0.05~0.25，缺省 0.15）；电池组 1 容量（4 字节浮点数，有效范 围 30~1000，缺省 65AH）；电池组 2 容量（4 个字节，保留）； 电 池组路数（1 个字节，有效范围 0~1，缺省 1）；定时均充时间（1 个字节，有效范围 30~240 天，缺省 60 天）
查询命令 | 命令 | 0xc982 | 长度 | 0x0005
| 信息域 | 握手字（2 个字节）；应答结果（1 个字节）

注：

1、 对于有两个电池接入端子的系统，因共用一个分流器，要求将电池组容量设为两路电池容

量之和，电池组路数设为 1。

2、 电池测试期间不可以修改电池管理参数，反馈配置失败。

3、 电池组数量为 0 时不接收其他参数设置

4、 定时均充的结束判据见监控模块规格书。

第 21 页 共 49 页

## 6.1.14设置下电参数

主节点通过向从节点发设置下电参数转发命令，设置从节点的下电参数。

从节点接收成功后根据转发命令参数域信息设置相应参数，并产生一条应答上报命令，放入发

送队列，等收到主节点的查询命令后，再将设置结果上报。

下发命令 | 命令 | 0xc983 | 长度 | 0x0013
| 信息域 | 握手字（2 个字节）；负载下电允许状态（1 个字节，AAH－允许， 55H－禁止，缺省 55H）；电池下电允许状态（1 个字节，AAH－允 许，55H－禁止，缺省 AAH）；负载下电电压（4 字节浮点数，有 效范围电池下电电压~直流欠压告警点，缺省 44V）； 电池组下 电电压（4 字节浮点数，有效范围 35V~负载下电电压，缺省 43V）； 低温启动负载下电允许状态（1 个字节，AAH－允许，55H－禁止， 缺省 55H）；低温启动负载下电温度（4 字节浮点数，有效范围 -40~0℃，缺省-10℃）
查询命令 | 命令 | 0xc983 | 长度 | 0x0005
| 信息域 | 握手字（2 个字节）；应答结果（1 个字节）

## 6.1.15 设置电池组温度补偿参数（05-1-26 修改）

主节点通过向从节点发设置电池组温度补偿参数转发命令，设置从节点的电池组温度补偿参

数。

从节点接收成功后根据转发命令参数域信息设置相应参数，并产生一条应答上报命令，放入发

送队列，等收到主节点的查询命令后，再将设置结果上报。

下发命令 | 命令 | 0xc985 | 长度 | 0x0029

第 22 页 共 49 页

| 信息域 | 握手字（2 个字节）；电池组温度 1 传感器测量上限（4 字节浮点 数，为传感器输出 20mA 信号对应的温度值，有效设置范围 0~100 ℃，缺省值为 80 ℃）；电池组温度 1 传感器测量下限（4 字节浮 点数，为传感器输出 4mA 信号对应的温度值，有效设置范围-50 ℃~0，缺省值为-20 ℃。）；电池组温度 1 过高告警点（4 字节 浮点数，有效设置范围-50~100℃，缺省值为 50℃）；电池组温 度 1 过低告警点（4 字节浮点数，有效设置范围-50~100℃，且小 于过高告警点，缺省值为 0℃）；电池组温度 2 传感器测量上限 （4 字节浮点数）；电池组温度 2 传感器测量下限（4 字节浮点数）； 电池组温度 2 过高告警点（4 字节浮点数）；电池组温度 2 过低 告警点（4 字节浮点数）； 温度补偿系数（4 字节浮点数；为电池组温度每变化 1 ℃电池组 浮充电压变化值，有效设置范围 0~500mV。缺省值为 80mV）；电 池组温度补偿依据的温度（1 个字节，AAH-电池组温度 1，55H-电池组温度 2，缺省值为 AAH）
查询命令 | 命令 | 0xc985 | 长度 | 0x0005
| 信息域 | 握手字（2 个字节）；应答结果（1 个字节）

注：1、电池组温度 2 的设置参数定义与电池组温度 1 相同。

2、温度补偿后的浮充电压有如下限制：下限不低于设置的浮充电压-2V，上限不超过均充电压。

2005-6-30

## 6.1.16设置电源模块参数

主节点通过向从节点发设置电源模块参数转发命令，设置从节点的电源模块参数。

从节点接收成功后根据转发命令参数域信息设置相应参数，并产生一条应答上报命令，放入发

送队列，等收到主节点的查询命令后，再将设置结果上报。

下发命令 | 命令 | 0xc986 | 长度 | 0x000f
| 信息域 | 握手字（2 个字节）；电源模块数量（1 个字节，有效范围 0～10， 缺省 9）； 电源模块 1～10 插槽位置（每模块 1 个字节，共 10 字节，有效范围 1～10, 不可重复）（参见附录 B）
查询命令 | 命令 | 0xc986 | 长度 | 0x0005
| 信息域 | 握手字（2 个字节）；应答结果（1 个字节）

注：

1、电池测试期间，不可以将电源模块数量设为 0，反馈配置失败。

2、电源模块数量最大可设为 10 是为了以后可兼容可能的配 10 个模块的电源系统，后台设置时要

求下发的配置数不超过实际系统允许的最大模块数。插槽位置的配置排列顺序固定，需配置的插槽

第 23 页 共 49 页

位置配置对应的数字，不需配置的插槽位置配置 0xAA。（2005/6/20 增加）

3、监控模块需要自动检测系统在线模块，说明如下：

A、当监控模块检测到没有配置的整流模块（包括模块正常工作、模块保护或模块故障）时，一概

上报该位置的模块非法，但进行正常管理。

B、当用户拔掉一个非法模块或非法模块通讯失败时，自动删除该模块而不上报模块通讯故障。（正

常配置的模块出现通讯故障或被拔掉时，需要上报该位置的模块通讯故障）

C、除说明 1 所列条件外，上位机的配置命令必须接受，包括删除正常工作模块（删除后可上报非

法模块）等操作。

## 6.1.17设置配电参数

主节点通过向从节点发设置配电参数转发命令，设置从节点的配电参数。

从节点接收成功后根据转发命令参数域信息设置相应参数，并产生一条应答上报命令，放入发

送队列，等收到主节点的查询命令后，再将设置结果上报。

下发命令 | 命令 | 0xc987 | 长度 | 0x0014
| 信息域 | 握手字（2 个字节）；交流过压告警点（4 字节浮点数，有效设置 范围欠压告警点~300，缺省值 280V）；交流欠压告警点（4 字节 浮点数，有效设置范围 60~过压告警点，且小于交流过压告警点， 缺省值 180V）；直流过压告警点（4 字节浮点数，有效设置范围 58~60，且大于（均充电压+1）V, 缺省值 58V）； 直流欠压告警 点（4 字节浮点数，有效设置范围下电电压~(浮充电压-2)V，且 小于直流过压告警点，缺省值 45V）
查询命令 | 命令 | 0xc987 | 长度 | 0x0005
| 信息域 | 握手字（2 个字节）；应答结果（1 个字节）

注意：上述直流欠压告警点中有效设置范围的下电电压是指：负载下电允许时为负载下电电压；负

载下电禁止电池下电允许时为电池下电电压，下电都禁止时为 35V。

## 6.1.18 设置环境参数

主节点通过向从节点发设置环境参数转发命令，设置从节点的环境参数。

从节点接收成功后根据转发命令参数域信息设置相应参数，并产生一条应答上报命令，放入发

送队列，等收到主节点的查询命令后，再将设置结果上报。

下发命令 | 命令 | 0xc988 | 长度 | 0x0024
| 信息域 | 握手字（2 个字节）；环境温度测量上限（4 字节浮点数，为传感

第 24 页 共 49 页

| | 器输出 20mA 信号时对应的温度值，有效设置范围 0~100℃，缺省 值为 80 ℃）； 环境温度测量下限（4 字节浮点数，为传感器输 出 4mA 信号时对应的温度值，有效设置范围-50℃~0，且小于温度 测量上限，缺省值为-20 ℃）；环境温度过高告警点（4 字节浮 点数，有效设置范围-50~100℃，缺省值为 50℃）；环境温度过 低告警点（4 字节浮点数，有效设置范围-50~100℃，缺省值为 0 ℃）；环境湿度测量上限（4 字节浮点数，为传感器输出 20mA 信 号时对应的湿度值，有效设置范围 0~100，缺省值为 100）；环境 湿度测量下限（4 字节浮点数，为传感器输出 4mA 信号时对应的 湿度值，有效设置范围 0~100，且小于湿度测量上限，缺省值为 0）； 环境湿度过高告警点（4 字节浮点数，有效设置范围 0~100，缺省 值为 80）；环境湿度过低告警点（4 字节浮点数，有效设置范围 0~100，且小于湿度告警上限，缺省值为 10）
查询命令 | 命令 | 0xc988 | 长度 | 0x0005
| 信息域 | 握手字（2 个字节）；应答结果（1 个字节）

注：环境温度1和环境温度2的设置参数相同，统一用环境温度表示。

## 6.1.19设置备用量配置参数

主节点通过向从节点发设置备用量配置参数转发命令，设置从节点的备用量配置参数。

从节点接收成功后根据转发命令参数域信息设置相应参数，并产生一条应答上报命令，放入发

送队列，等收到主节点的查询命令后，再将设置结果上报。

下发命令 | 命令 | 0xc989 | 长度 | 0x001c
| 信息域 | 握手字（2 个字节）；备用模拟量 1~6 的告警上限（保留，每个 模拟量 1 个字节共 6 字节，有效设置范围 0~FEH）；备用模拟量 1~6 的告警下限（保留，每个模拟量 1 个字节共 6 字节，有效设 置范围 0~FE H 且小于告警上限）；备用开关量 1~7 告警电平（每 个开关量 1 个字节共 7 字节，01H-高电平告警，00H-低电平告警， 缺省值为 01H）；保留（5 个字节）
查询命令 | 命令 | 0xc989 | 长度 | 0x0005
| 信息域 | 握手字（2 个字节）；应答结果（1 个字节）

注意：因 FFH 具有特殊含义，备用模拟量上下限设置范围最大只能为 0~FEH，对应着备用模拟量

0~5V 的信号输入电压范围。

## 6.1.20获取电源系统控制参数

从节点上电或复位重新启动后，主节点向从节点发获取均浮充等控制参数转发命令，通过查询

第 25 页 共 49 页

命令获取均浮充控制参数，如果与需要设置的不一样，则向从节点发送设置均浮充控制参数转发命

令，重新设置从节点。

从节点接收成功后产生一条应答上报命令，放入发送队列，等收到主节点的查询命令后，将配

置参数上报。

下发命令 | 命令 | 0xc990 | 长度 | 0x0004
| 信息域 | 握手字（2 个字节）；
查询命令 | 命令 | 0xc990 | 长度 | 0x0001D
| 信息域 | 握手字（2 个字节）； 应答结果（1 个字节）；受控状态（1 个 字节）；充电状态（1 个字节）；负载上下电控制(1 个字节)； 电 池上下电控制(1 个字节) ；电源模块开关机命令（1 个字节）； 保留（19 个字节）

注意：参数范围定义与缺省值参见设置部分。

## 6.1.21获取均浮充电压

从节点上电或复位重新启动后，主节点向从节点发获取均浮充电压转发命令，通过查询命令获

取相应参数，如果与需要设置的不一样，则向从节点发送设置均浮充电压参数转发命令，重新设置

从节点。

从节点接收成功后产生一条应答上报命令，放入发送队列，等收到主节点的查询命令后，将配

置参数上报。

下发命令 | 命令 | 0xc991 | 长度 | 0x0004
| 信息域 | 握手字（2 个字节）
查询命令 | 命令 | 0xc991 | 长度 | 0x000d
| 信息域 | 握手字（2 个字节）； 应答结果（1 个字节）； 均充电压（4 字 节浮点数）；浮充电压（4 字节浮点数）

注意：参数范围定义与缺省值参见设置部分。

## 6.1.22获取电池管理参数

从节点上电或复位重新启动后，主节点通过向从节点发获取电池管理参数转发命令，通过查询

命令获取相应参数，如果与需要设置的不一样，则向从节点发送设置电池管理参数转发命令，重新

设置从节点。

从节点接收成功后产生一条应答上报命令，放入发送队列，等收到主节点的查询命令后，将配

置参数上报。

第 26 页 共 49 页

下发命令 | 命令 | 0xc992 | 长度 | 0x0004
| 信息域 | 握手字（2 个字节）
查询命令 | 命令 | 0xc992 | 长度 | 0x0013
| 信息域 | 握手字（2 个字节）； 应答结果（1 个字节）； 充电限流点系数 （4 字节浮点数）；电池组 1 容量（4 字节浮点数）；电池组 2 容量（4 个字节；保留）； 电池组路数（1 个字节）；定时均充 时间（1 个字节）

注意：参数范围定义与缺省值参见设置部分。

## 6.1.23获取下电参数

从节点上电或复位重新启动后，主节点通过向从节点发获取下电参数转发命令，通过查询命令

获取相应参数，如果与需要设置的不一样，则向从节点发送设置下电参数转发命令，重新设置从节

点。

从节点接收成功后产生一条应答上报命令，放入发送队列，等收到主节点的查询命令后，将配

置参数上报。

下发命令 | 命令 | 0xc993 | 长度 | 0x0004
| 信息域 | 握手字（2 个字节）
查询命令 | 命令 | 0xc993 | 长度 | 0x0014
| 信息域 | 握手字（2 个字节）； 应答结果（1 个字节）； 负载下电允许状 态（1 个字节）；电池下电允许状态（1 个字节）；负载下电电压 （4 字节浮点数）； 电池组下电电压（4 字节浮点数）；低温启 动负载下电允许状态（1 个字节）；低温启动负载下电温度（4 字节浮点数）2005-6-23 增加

注意：参数范围定义与缺省值参见设置部分。

## 6.1.24获取电池组温度补偿参数

从节点上电或复位重新启动后，主节点通过向从节点发获取电池组温度补偿参数转发命令，通

过查询命令获取相应参数，如果与需要设置的不一样，则向从节点发送设置电池组温度补偿参数转

发命令，重新设置从节点。

从节点接收成功后产生一条应答上报命令，放入发送队列，等收到主节点的查询命令后，将配

置参数上报。

下发命令 | 命令 | 0xc995 | 长度 | 0x0004
| 信息域 | 握手字（2 个字节）
查询命令 | 命令 | 0xc995 | 长度 | 0x002a

第 27 页 共 49 页

信息域 | 握手字（2 个字节）； 应答结果（1 个字节）；电池组温度 1 传 感器测量上限（4 字节浮点数）；电池组温度 1 传感器测量下限 （4 字节浮点数）；电池组温度 1 过高告警点（4 字节浮点数）； 电池组温度 1 过低告警点（4 字节浮点数）；电池组温度 2 传感 器测量上限（4 字节浮点数）；电池组温度 2 传感器测量下限（4 字节浮点数）；电池组温度 2 过高告警点（4 字节浮点数）；电 池组温度 2 过低告警点（4 字节浮点数）；温度补偿系数（4 字节 浮点数）；电池组温度补偿依据的温度（1 个字节）

注意：参数范围定义与缺省值参见设置部分。

## 6.1.25获取电源模块参数

从节点上电或复位重新启动后，主节点向从节点发获取电源模块参数转发命令，通过查询命令

获取相应参数，如果与需要设置的不一样，则向从节点发送设置电源模块参数转发命令，重新设置

从节点。

从节点接收成功后产生一条应答上报命令，放入发送队列，等收到主节点的查询命令后，将配

置参数上报。

下发命令 | 命令 | 0xc996 | 长度 | 0x0004
| 信息域 | 握手字（2 个字节）
查询命令 | 命令 | 0xc996 | 长度 | 0x0010
| 信息域 | 握手字（2 个字节）； 应答结果（1 个字节）； 电源模块数量（1 个字节）；电源模块 1～10 插槽位置（每模块 1 个字节，共 10 字节）

注意：参数范围定义与缺省值参见设置部分。

## 6.1.26获取配电参数

从节点上电或复位重新启动后，主节点通过向从节点发获取配电参数转发命令，通过查询命令

获取相应参数，如果与需要设置的不一样，则向从节点发送设置配电参数转发命令，重新设置从节

点。

从节点接收成功后产生一条应答上报命令，放入发送队列，等收到主节点的查询命令后，将配

置参数上报。

下发命令 | 命令 | 0xc997 | 长度 | 0x0004
| 信息域 | 握手字（2 个字节）
查询命令 | 命令 | 0xc997 | 长度 | 0x0015

第 28 页 共 49 页

信息域 | 握手字（2 个字节）； 应答结果（1 个字节）； 交流过压告警点 （4 字节浮点数）；交流欠压告警点（4 字节浮点数）；直流过压 告警点（4 字节浮点数）； 直流欠压告警点（4 字节浮点数）

注意：参数范围定义与缺省值参见设置部分。

## 6.1.27获取环境参数

从节点上电或复位重新启动后，主节点通过向从节点发获取环境参数转发命令，通过查询命令

获取相应参数，如果与需要设置的不一样，则向从节点发送设置环境参数转发命令，重新设置从节

点。

从节点接收成功后产生一条应答上报命令，放入发送队列，等收到主节点的查询命令后，将配

置参数上报。

下发命令 | 命令 | 0xc998 | 长度 | 0x0004
| 信息域 | 握手字（2 个字节）
查询命令 | 命令 | 0xc998 | 长度 | 0x0025
| 信息域 | 握手字（2 个字节）； 应答结果（1 个字节）； 环境温度测量上 限（4 个字节浮点数）； 环境温度测量下限（4 个字节浮点数）； 环境温度告警上限参数（4 个字节浮点数）；环境温度告警下限 （4 个字节浮点数）；环境湿度测量上限（4 个字节浮点数）；环 境湿度测量下限（4 个字节浮点数）；环境湿度告警上限（4 字节 浮点数）；环境湿度告警下限（4 个字节浮点数）

注意：参数范围定义与缺省值参见设置部分。

## 6.1.28获取备用量参数

从节点上电或复位重新启动后，主节点向从节点发获取备用量参数转发命令，主节点通过向从

节点发获取环境参数转发命令，通过查询命令获取相应参数，如果与需要设置的不一样，则向从节

点发送设置备用量参数转发命令，重新设置从节点。

从节点接收成功后产生一条应答上报命令，放入发送队列，等收到主节点的查询命令后，将配

置参数上报。

下发命令 | 命令 | 0xc999 | 长度 | 0x0004
| 信息域 | 握手字（2 个字节）
查询命令 | 命令 | 0xc999 | 长度 | 0x001d

第 29 页 共 49 页

信息域 | 握手字（2 个字节）； 应答结果（1 个字节）； 备用模拟量 1~6 的告警上限（保留，6 个字节）； 备用模拟量 1~6 的告警下限（保 留，6 个字节）；备用开关量 1~7 告警状态（每个开关量 1 个字 节共 7 字节）；保留（5 个字节）

注意：参数范围定义与缺省值参见设置部分。

## 6.1.29配置参数恢复缺省值

主节点通过向从节点发配置参数恢复缺省值转发命令，使从节点的所有设置参数都恢复缺省

值。

从节点接收成功后将所有配置参数刷新为缺省值，并产生一条应答上报命令，放入发送队列，

等收到主节点的查询命令后，再将设置结果上报。

下发命令 | 命令 | 0xc9aa | 长度 | 0x0004
| 信息域 | 握手字（2 个字节）
查询命令 | 命令 | 0xc9aa | 长度 | 0x0005
| 信息域 | 握手字（2 个字节）；应答结果（1 个字节）

注意：电池组放电测试期间下发恢复缺省值命令返回配置失败。

## 6.1.30 设置电压测量参考基准

主节点通过向从节点发设置命令，修改从节点保存的电压电流测量参考基准。

从节点接收成功后执行要求的操作，并根据结果产生一条应答上报命令，放入发送队列，等收

到主节点的查询命令后，再将结果上报。

下发命 令 | 命令 | 0xc99b | 长度 | 0x0008
| 信息域 | 握手字（2 个字节）；电压测量基准（4 字节浮点数，有效范围 3.0±20%，缺省为 3V）
查询命令 | 命令 | 0xc99b | 长度 | 0x0005
| 信息域 | 握手字（2 个字节）；应答结果（1 个字节）

## 6.1.31 设置配电模拟量校准系数

主节点通过向从节点发设置命令，修改从节点保存的配电模拟量校准系数。

从节点接收成功后执行要求的操作，并根据结果产生一条应答上报命令，放入发送队列，等收

到主节点的查询命令后，再将结果上报。

第 30 页 共 49 页

下发命 令 | 命令 | 0xc99c | 长度 | 0x0034
| 信息域 | 握手字（2 个字节）；交流电压校准系数；直流电压校准系数； 负载电流校准系数；电池电流校准系数； 交流电压零点漂移；直流电压零点漂移；负载电流零点漂移；电 池电流零点漂移；备用（16 字节）
查询命令 | 命令 | 0xc99c | 长度 | 0x0005
| 信息域 | 握手字（2 个字节）；应答结果（1 个字节）

注：1、校准系数和零点漂移都是浮点数格式。

2、 校准系数是实际值除以采样结果的商，有效设置范围为 1.0±20%，缺省为 1.0。

3、 零点漂移的有效设置范围为-0.5（V 或 A）—+0.5（V 或 A），缺省为 0。

## 6.1.32 启动或终止蓄电池立即测试

主节点通过向从节点发启动或终止转发命令，让从节点执行启动或终止电池测试的命令。

从节点接收成功后执行要求的操作，并根据结果产生一条应答上报命令，放入发送队列，等收

到主节点的查询命令后，再将结果上报。

下发命令 | 命令 | 0xc99d | 长度 | 0x0005
| 信息域 | 握手字（2 个字节）；功能码（1 字节，1－启动手动测试；2－启 动简化测试；55H－终止电池立即测试）
查询命令 | 命令 | 0xc99d | 长度 | 0x0005
| 信息域 | 握手字（2个字节）；应答结果（1个字节：0 － 执行或验证成功， 1-数据无效，2-后台手动控制导致执行失败，3-整流模块数量为0 导致执行失败，4-蓄电池组路数为0导致执行失败，5-测试间隔小 于测试延时时间导致执行失败，6-正在进行放电测试导致执行失 败，7-有告警导致执行失败 2005-6-22增加）

注：

1、 测试间隔说明：为了保护蓄电池，两次蓄电池测试之间，或交流掉电恢复到本次蓄电池测试之

间，或后台控制结束到本次蓄电池测试之间需要有间隔；2005-6-22 增加

2、 测试延时时间：缺省值为 14 天，如果蓄电池自动测试参数设置中定义了新的“停电或上次测试

后或后台控制后延迟放电测试时间”，则以该时间为测试延时时间；2005-6-22 增加

3、 下列告警不影响蓄电池立即测试：温湿度传感器告警；环境温度 2 告警；未配置的电池组温度

告警（电池组温度 1 和电池组温度 2 是二选一）；备用量告警；2005-6-22 增加

第 31 页 共 49 页

4、简化测试：不计算电池容量，电池放电一个较短时间，如设置30分钟「简化放电测试时限」，

如果电压30分钟内下降至低于「简化放电测试终止电压」，便会产生电池告警，表示电池容量不足；

5、终止电池立即测试――终止所有电池测试，包括正在进行的电池自动测试。

## 6.1.33设置蓄电池自动测试参数

主节点通过向从节点发设置或终止转发命令，让从节点执行启动或终止电池测试的命令。

从节点接收成功后执行要求的操作，并根据结果产生一条应答上报命令，放入发送队列，等收

到主节点的查询命令后，再将结果上报。

下发命令 | 命令 | 0xc9ab | 长度 | 0x0007
| 信息域 | 握手字（2 个字节）；功能码（1 字节，1－定时自动测试允许；2 －掉电自动测试允许；3－定时自动测试+掉电自动测试允许；55H －自动测试禁止，缺省值：2）；定时放电测试时间（1 个字节： 30～240 天；缺省值：120）；停电或上次测试后或后台控制后延 迟放电测试时间（1 个字节：1～60 天；缺省值：14）
查询命令 | 命令 | 0xc9ab | 长度 | 0x0005
| 信息域 | 握手字（2个字节）；应答结果（1个字节：0-执行或验证成功， 1-数据无效，6-正在进行放电测试导致设置失败）

注：

1、 如果是定时自动测试，还需要设置“定时放电测试时间”和“停电或上次测试后或后台控制后

延迟放电测试时间”，如果不需更改缺省值，将“定时放电测试时间”和“停电或上次测试后或

后台控制后延迟放电测试时间”设置为 0xff；“定时放电测试时间”必须大于“停电或上次测试

后或后台控制后延迟放电测试时间”。

2、 自动测试禁止――禁止自动测试。

3、 下列告警不影响蓄电池自动测试：温湿度传感器告警；环境温度 2 告警；未配置的电池组温度

告警（电池组温度 1 和电池组温度 2 是二选一）；备用量告警。2005-7-4 增加

## 6.1.34查询蓄电池自动测试参数

主节点通过向从节点发查询转发命令，让从节点将自动测试参数上报。

从节点接收成功后执行要求的操作，并根据结果产生一条应答上报命令，放入发送队列，等收

到主节点的查询命令后，再将结果上报。

第 32 页 共 49 页

下发命令 | 命令 | 0xc9ac | 长度 | 0x0004
| 信息域 | 握手字（2 个字节）
查询命令 | 命令 | 0xc9ac | 长度 | 0x0008
| 信息域 | 握手字（2个字节）；应答结果（1个字节）；功能码（1字节）； 定时放电测试时间（1个字节）；停电或后台控制后延迟放电测试 （1个字节）

## 6.1.35 设置各告警量告警级别

主节点通过向从节点发设置命令，修改从节点当前保存的各告警量告警级别。

从节点接收成功后执行要求的操作，并根据结果产生一条应答上报命令，放入发送队列，等收

到主节点的查询命令后，再将结果上报。

下发命 令 | 命令 | 0xc99e | 长度 | 0x002F
| 信息域 | 握手字（2 个字节）；市电状态告警级别（缺省：AAH）；市电过 欠压告警级别（缺省：55H）；直流输出过欠压告警级别（缺省： AAH）；负载下电告警级别（缺省：AAH）；电池下电告警级别（缺 省：AAH）；电池回路空开断告警级别（缺省：AAH）；环境温度 1 异常告警级别（缺省：55H）（2005-10-19 更改）；环境湿度异 常告警级别（缺省：00H）；电池组温度异常告警级别（缺省：55H）； 门禁异常告警级别（缺省：55H）；水浸告警级别（缺省：AAH）； 烟雾告警级别（缺省：AAH）；整流模块故障告警级别（缺省：AAH）； 整流模块保护告警级别（缺省：55H）；整流模块通讯失败告警级 别（缺省：55H）；充电过流告警级别（缺省：55H）；备用开关 量 1～7 告警级别（每个开关量 1 个字节共 7 字节，缺省：55H）； 保留字节（20 字节，不处理，缺省为 0）
查询命令 | 命令 | 0xc99e | 长度 | 0x0005
| 信息域 | 握手字（2 个字节）；应答结果（1 个字节）

每个告警量告警级别为 1 个字节，AAH--严重告警；55H--一般告警；00H--不告警。

监控模块只对门磁、湿度和备用量的告警可以设置为不告警进行屏蔽，其他告警不接收不告警设置，

返回参数错误。

## 6.1.36 获取各告警量告警级别

主节点通过向从节点发查询命令，以获取从节点保存的各告警量告警级别。

第 33 页 共 49 页

从节点接收成功后产生一条应答上报命令，放入发送队列，等收到主节点的查询命令后，再将

结果上报。

下发命令 | 命令 | 0xc99f | 长度 | 0x0004
| 信息域 | 握手字（2 个字节）
查询命令 | 命令 | 0xc99f | 长度 | 0x0030
| 信息域 | 握手字（2 个字节）；应答结果（1 个字节）；市电状态告警级别； 市电过欠压告警级别；直流输出过欠压告警级别；负载下电告警 级别；电池下电告警级别；电池回路空开断告警级别；环境温度 1 异常告警级别；环境湿度异常告警级别；电池组温度异常告警 级别；门禁异常告警级别；水浸告警级别；烟雾告警级别；整流 模块故障告警级别；整流模块保护告警级别；整流模块通讯失败 告警级别；充电过流告警级别；备用开关量 1～7 告警级别（每个 开关量 1 个字节共 7 字节）；保留字节（20 字节）

每个告警量告警级别为 1 个字节，AAH--严重告警；55H--一般告警；00H--不告警。

注意：参数范围定义与缺省值参见设置部分。

## 6.1.37 获取电池放电测试结果

主节点通过向从节点发查询命令，以获取电池放电测试结果。

从节点接收成功后产生一条应答上报命令，放入发送队列，等收到主节点的查询命令后，再将

结果上报。

下发命令 | 命令 | 0xc9a0 | 长度 | 0x0005
| 信息域 | 握手字（2 个字节）；测试结果编号（1 个字节，有效范围 1～10， 一共保存 10 次测试的结果，见注释）
查询命令 | 命令 | 0xc9a0 | 长度 | 0x0023

第 34 页 共 49 页

信息域 | 握手字（2 个字节）；应答结果（1 个字节）； 测试结果编号（1 字节） ；测试类型（1 字节，1－手动测试；2 －掉电自动测试；3－定时自动测试；4－简化测试；0xFF－无测 试）；启动测试年份（1 字节，加上 2000 为实际的时间）； 启 动测试月份（1 字节）；启动测试日期（1 字节）；启动测试小时 （1 字节）；启动测试分钟（1 字节）；测试结果（1 字节，0AH －没有结果；0BH－电池正常；0CH－电池预告警；0DH－电池告警）； 电池效率（1 字节，0～100，单位：%，或 FFH－无数据）；放电 持续时间（4 字节浮点数，单位为小时）；放电终止电压（4 字节 浮点数）；放电平均电流（4 字节浮点数）；放电累积 AH 数（4 字节浮点数）；电池组温度（4 字节浮点数）；测试结束原因（1 字节，1—低于终止电压；2－超过测试时限；3－市电恢复后中断 掉电自动测试；4－手动终止测试；5－故障告警终止，比如：电 池组温度过高、模块故障）

注：

1、电池测试数据共保存 10 组，标号 1～10，第一次蓄电池的测试数据永远保存，作为参考数据，

除非安装新蓄电池后重新设置蓄电池参数（重新设置蓄电池安装时间作为安装新蓄电池的标志），

10 组数据存满时第一次测试数据放在标号 10。其他 9 个标号数据保存最新测试的 9 组数据，标号 1

表示最新测试数据。

2、如果测试结果编号所对应的测试并未进行，测试类型上报 0xFF，后续其他字节均为 0。

3、如果本次测试未完成时上位机下发获取命令，不上报本次未完成的测试结果，上报前次测试结

果。

4、当上位机下发蓄电池安装时间，且下发的安装时间与前次安装时间不相同时将蓄电池测试数据

清零。2005-7-20

## 6.1.38获取配电模拟量校准系数

主节点通过向从节点发送该命令，获取从节点保存的配电模拟量校准系数。

从节点接收成功后执行要求的操作，并根据结果产生一条应答上报命令，放入发送队列，等收

到主节点的查询命令后，再将结果上报。

下发命令 | 命令 | 0xc9a1 | 长度 | 0x0004
| 信息域 | 握手字（2 个字节）
查询命令 | 命令 | 0xc9a1 | 长度 | 0x0035

第 35 页 共 49 页

信息域 | 握手字（2 个字节）；应答结果（1 个字节）；交流电压校准系数 (4 字节浮点数)；直流电压校准系数(4 字节浮点数)；负载电流校 准系数(4 字节浮点数)；电池电流校准系数(4 字节浮点数)；参考 基准电压(4 字节浮点数)；备用（28 字节）

注意：参数范围定义与缺省值参见设置部分。

## 6.1.39设置高温下电保护参数

主节点通过向从节点发设置命令，修改从节点当前保存的内容。

从节点接收成功后执行要求的操作，并根据结果产生一条应答上报命令，放入发送队列，等收

到主节点的查询命令后，再将结果上报。

下发命令 | 命令 | 0xc98a | 长度 | 0x0008
| 信息域 | 握手字（2 个字节）；负载高温下电使能控制（1 字节：AAH—允 许，55H—禁止，缺省 55H）；负载高温下电的温度（1 字节，设 置范围 50℃~70℃，缺省为 65℃）；电池高温下电使能控制（1 字节：AAH—允许，55H—禁止，缺省 55H）；电池高温下电的温 度（1 字节，设置范围 40℃~70℃，缺省为 53℃）
查询命令 | 命令 | 0xc98a | 长度 | 0x0005
| 信息域 | 握手字（2 个字节）；应答结果（1 个字节）

## 6.1.40获取高温下电保护参数

主节点通过向从节点发查询命令，以获取从节点保存的内容。

从节点接收成功后产生一条应答上报命令，放入发送队列，等收到主节点的查询命令后，再将

结果上报。

下发命令 | 命令 | 0xc98b | 长度 | 0x0004
| 信息域 | 握手字（2 个字节）
查询命令 | 命令 | 0xc98b | 长度 | 0x0009
| 信息域 | 握手字（2 个字节）；应答结果（1 个字节）；负载高温下电使能 控制（1 字节）；负载高温下电的温度（1 字节）；电池高温下电 使能控制（1 字节）；电池高温下电的温度（1 字节）

注意：参数范围定义与缺省值参见设置部分。

## 6.1.41设置电池组容量检测参数

主节点通过向从节点发设置命令，修改从节点当前保存的内容。

从节点接收成功后执行要求的操作，并根据结果产生一条应答上报命令，放入发送队列，等收

第 36 页 共 49 页

到主节点的查询命令后，再将结果上报。(表中 C10 表示电池组标称容量)

下发命令 | 命令 | 0xc98c | 长度 | 0x003e
信息域 | 握手字（2 个字节）；（放电时间设置范围 0.01～50）
0.05C10 放电时间（4 字节浮点数，单位：小时；缺省值：12）； 0.1C10 放电时间（4 字节浮点数，单位：小时；缺省值：6.0）； 0.2C10 放电时间（4 字节浮点数，单位：小时；缺省值：3.0）； 0.3C10 放电时间（4 字节浮点数，单位：小时；缺省值：1.5）； 0.4C10 放电时间（4 字节浮点数，单位：小时；缺省值：1.0）； 0.5C10 放电时间（4 字节浮点数，单位：小时；缺省值：0.7）； 0.6C10 放电时间（4 字节浮点数，单位：小时；缺省值：0.5）； 0.7C10 放电时间（4 字节浮点数，单位：小时；缺省值：0.4）； 0.8C10 放电时间（4 字节浮点数，单位：小时；缺省值：0.3）； 0.9C10 放电时间（4 字节浮点数，单位：小时；缺省值：0.25）； 电池组充电效率（4 字节浮点数，设置范围 0.8～1.0；默认值：
| | 0.8）；
放电测试终止电压（4 字节浮点数，1.7~2.2，单位：V/cell；缺
| | 省值：1.9）；
电池组电池数量（1 字节，1~50，单位：cell；缺省值：24）； 放电测试时限（4 字节浮点数：1～100 小时，缺省值：10）； 简化放电测试终止电压（4 字节浮点数：40～54V；缺省值：45）； 简化放电测试时限（1 字节：1～240 分钟；缺省值：60）
查询命令 | 命令 | 0xc98c | 长度 | 0x0005
| 信息域 | 握手字（2 个字节）；应答结果（1 个字节：0-执行或验证成功， 1-数据无效，6-正在进行放电测试导致参数设置失败 2005-6-28）

注：

1、电池组充电效率<70％，电池告警；

2、70%≤电池组充电效率<电池组充电效率设定值，电池预告警；

3、电池组充电效率≥电池组充电效率设定值，电池正常。

4、蓄电池测试过程中，禁止修改本命令参数，否则返回失败。

5、除掉电自动测试外，蓄电池测试阶段如果测试终止电压低于负载下电电压或电池下电电压，不

可启动负载下电和电池下电功能。2005/6/30 增加

6、小于 0.05C 的放电电流以 0.05C 放电电流的放电时间为参考。

## 6.1.42 获取电池组容量检测参数

主节点通过向从节点发查询命令，以获取从节点保存的内容。

第 37 页 共 49 页

从节点接收成功后产生一条应答上报命令，放入发送队列，等收到主节点的查询命令后，再将

结果上报。(表中 C10 表示电池组标称容量)

下发命令 | 命令 | 0xc98d | 长度 | 0x0004
| 信息域 | 握手字（2 个字节）
查询命令 | 命令 | 0xc98b | 长度 | 0x003f
信息域 | 握手字（2 个字节）；应答结果（1 个字节）； 0.05C10 放电时间（4 字节浮点数）； 0.1C10 放电时间（4 字节浮点数）； 0.2C10 放电时间（4 字节浮点数）； 0.3C10 放电时间（4 字节浮点数）； 0.4C10 放电时间（4 字节浮点数）； 0.5C10 放电时间（4 字节浮点数）； 0.6C10 放电时间（4 字节浮点数）； 0.7C10 放电时间（4 字节浮点数）； 0.8C10 放电时间（4 字节浮点数）； 0.9C10 放电时间（4 字节浮点数）； 电池组充电效率（4 字节浮点数）； 放电测试终止电压（4 字节浮点数）； 电池组电池数量（1 字节）； 放电测试时限（4 字节浮点数）； 简化放电测试终止电压（4 字节浮点数）； 简化放电测试时限（1 字节）

注意：参数范围定义与缺省值参见设置部分。

## 6.1.43设置协议扩展参数

主节点通过向从节点发设置命令，下发配置参数或者控制输出参数。

从节点接收成功后执行要求的操作，并根据结果产生一条应答上报命令，放入发送队列，等收 到主节点的查询命令后，再将结果上报。
下发命令 | 命令 | 0xc98f | 长度 | 0x000A
| 信息域 | 握手字（2 个字节）；参数索引（2 个字节）；参数值（4 个字节）
查询命令 | 命令 | 0xc98f | 长度 | 0x0005
| 信息域 | 握手字（2 个字节）；应答结果（1 个字节）

注：参数索引与参数内容参见附录 F。参数值字段中的 0xFF 不具有特殊含义，被解释为设置内容。

## 6.1.44获取协议扩展参数

主节点通过向从节点发查询命令，以获取从节点保存的内容。

从节点接收成功后产生一条应答上报命令，放入发送队列，等收到主节点的查询命令后，再将

第 38 页 共 49 页

结果上报。

下发命令 | 命令 | 0xc98e | 长度 | 0x0006
| 信息域 | 握手字（2 个字节）；参数索引（2 个字节）
查询命令 | 命令 | 0xc98e | 长度 | 0x000B
| 信息域 | 握手字（2 个字节）；应答结果（1 个字节）； 参数索引（2 个字节）；参数值（4 个字节）

注：参数索引与参数内容参见附录 F。下发命令的参数索引没有定义时，监控模块不上报任何信息。

协议扩展的索引不能取 0，作为保留字。

## 6.1.45设置当前时间

主节点通过向从节点发设置命令，修改从节点当前保存的内容。

从节点接收成功后执行要求的操作，并根据结果产生一条应答上报命令，放入发送队列，等收

到主节点的查询命令后，再将结果上报。

下发命令 | 命令 | 0xc9a3 | 长度 | 0x0009
| 信息域 | 握手字（2 个字节）；设置的年份减去 2000（1 字节：设置范围 0～ 127）；设置的月份（1 字节，设置范围 1～12）；设置的日期（1 字节，设置范围 1～31）；设置的小时（1 字节，设置范围 0～23）； 设置的分钟（1 字节，设置范围 0～59）
查询命令 | 命令 | 0xc9a3 | 长度 | 0x0005
| 信息域 | 握手字（2 个字节）；应答结果（1 个字节）

## 6.1.46获取当前时间

主节点通过向从节点发查询命令，以获取从节点保存的内容。

从节点接收成功后产生一条应答上报命令，放入发送队列，等收到主节点的查询命令后，再将

结果上报。

下发命令 | 命令 | 0xc9a4 | 长度 | 0x0004
| 信息域 | 握手字（2 个字节）
查询命令 | 命令 | 0xc9a4 | 长度 | 0x000a
| 信息域 | 握手字（2 个字节）；应答结果（1 个字节）；年份减去 2000（1 字节）；月份（1 字节）；日期（1 字节）；小时（1 字节）；分 钟（1 字节）

注意：参数范围定义与缺省值参见设置部分。

第 39 页 共 49 页

## 6.1.47设置蓄电池安装时间

主节点通过向从节点发设置命令，修改从节点当前保存的内容。

从节点接收成功后执行要求的操作，并根据结果产生一条应答上报命令，放入发送队列，等收

到主节点的查询命令后，再将结果上报。

下发命令 | 命令 | 0xc9a5 | 长度 | 0x0007
| 信息域 | 握手字（2 个字节）；设置的年份减去 2000（1 字节：设置范围 0～ 127，缺省值：05）；设置的月份（1 字节，设置范围 1～12，缺 省值：01）；设置的日期（1 字节，设置范围 1～31，缺省值：01）。
查询命令 | 命令 | 0xc9a5 | 长度 | 0x0005
| 信息域 | 握手字（2 个字节）；应答结果（1 个字节）

注：蓄电池自动测试过程中，禁止修改本命令参数，否则返回失败。

## 6.1.48获取蓄电池安装时间

主节点通过向从节点发查询命令，以获取从节点保存的内容。

从节点接收成功后产生一条应答上报命令，放入发送队列，等收到主节点的查询命令后，再将

结果上报。

下发命令 | 命令 | 0xc9a6 | 长度 | 0x0004
| 信息域 | 握手字（2 个字节）
查询命令 | 命令 | 0xc9a6 | 长度 | 0x0008
| 信息域 | 握手字（2 个字节）；应答结果（1 个字节）；年份减去 2000（1 字节）；月份（1 字节）；日期（1 字节）

注意：参数范围定义与缺省值参见设置部分。

## 6.1.49获取单板生产日期和厂家信息（监控模块）

主节点通过向从节点发查询命令，以获取从节点保存的内容。

从节点接收成功后产生一条应答上报命令，放入发送队列，等收到主节点的查询命令后，再将

结果上报。

下发命令 | 命令 | 0xc9a2 | 长度 | 0x0004
| 信息域 | 握手字（2 个字节）
查询命令 | 命令 | 0xc9a2 | 长度 | 0x0009

第 40 页 共 49 页

信息域 | 握手字（2 个字节）；应答结果（1 个字节）；单板生产日期和厂
家共 4 个字节（生产日期 3 个字节：年一个字节、月一个字节、 日一个字节，生产厂家编码 1 个字节）

说明：年只取后两位，例如 2004 年，对应年的字节填写“04”。

## 6.1.50 烟雾告警复位命令

由主节点向从节点发烟雾告警复位转发命令。

从节点在收到主节点发的烟雾告警复位转发命令后，产生一条上报命令，等主节点发查询命令

时上报，上报成功后开始复位。

下发命令 | 命令 | 0xc9ad | 长度 | 0x0004
| 信息域 | 握手字（2 个字节）
查询命令 | 命令 | 0xc9ad | 长度 | x0005
| 信息域 | 握手字（2 个字节）；应答结果（1 个字节）
6.1.51 | 关闭或复位电源输出命令

主节点通过向从节点发关闭或复位电源输出命令，完全关闭电源系统的直流电压输出，然后根

据延时时间进行上电或永远关闭。

从节点在收到主节点发的关闭电源输出转发命令后，产生一条上报命令，等主节点发查询命令

时上报，上报设置成功后，关闭所有 AC/DC 电源模块输出，同时进行蓄电池下电操作。

下发命令 | 命令 | 0xc9ae | 长度 | 0x0005
| 信息域 | 握手字（2 个字节）；延时时间(1 个字节，0 代表关闭后不再打 开输出，单位为分钟)
查询命令 | 命令 | 0xc9ae | 长度 | 0x0005
| 信息域 | 握手字（2 个字节）；应答结果（1 个字节）

注：通过“关闭电源输出”命令可以关闭电源模块输出和进行蓄电池下电。消息中的延迟时间指在

设定的延迟时间后打开电源模块输出和蓄电池上电，或者永远关闭输出。

## 6.1.52设置电源系统参数 2005-7-28

主节点通过向从节点发设置电源系统参数转发命令，设置从节点的电源系统参数。

从节点接收成功后根据转发命令参数域信息设置相应参数，并产生一条应答上报命令，放入发

送队列，等收到主节点的查询命令后，再将设置结果上报。

第 41 页 共 49 页

下发命令 | 命令 | 0xc9af | 长度 | 0x002b
信息域 | 握手字（2 个字节）；均充电压（4 字节浮点数，有效范围 43.2~57.6，
且大于浮充电压小于直流过压告警点-1V，缺省 56.5V）；浮充电 压（4 字节浮点数，有效范围 43.2~57.6，且大于(直流欠压告警 点+2)V 小于均充电压，缺省 53.5V）；负载下电允许状态（1 个 字节，AAH－允许，55H－禁止，缺省 55H）；电池下电允许状态 （1 个字节，AAH－允许，55H－禁止，缺省 AAH）；负载下电电压 （4 字节浮点数，有效范围电池下电电压~直流欠压告警点，缺省 44V）；电池组下电电压（4 字节浮点数，有效范围 35V~负载下电 电压，缺省 43V）；低温启动负载下电允许状态（1 个字节，AAH －允许，55H－禁止，缺省 55H）；低温启动负载下电温度（4 字 节浮点数，有效范围-40~0℃，缺省-10℃）；交流过压告警点（4 字节浮点数，有效设置范围欠压告警点~300，缺省值 280V）；交 流欠压告警点（4 字节浮点数，有效设置范围 60~过压告警点，且 小于交流过压告警点，缺省值 180V）；直流过压告警点（4 字节 浮点数，有效设置范围 58~60，且大于（均充电压+1）V, 缺省值 58V）； 直流欠压告警点（4 字节浮点数，有效设置范围下电电 压~(浮充电压-2)V，且小于直流过压告警点，缺省值 45V）
查询命令 | 命令 | 0xc9af | 长度 | 0x0005
| 信息域 | 握手字（2 个字节）；应答结果（1 个字节）

## 6.1.53获取电源系统参数 2005-7-28

主节点通过向从节点发查询命令，以获取从节点保存的内容。

从节点接收成功后产生一条应答上报命令，放入发送队列，等收到主节点的查询命令后，再将

结果上报。

下发命令 | 命令 | 0xc9b0 | 长度 | 0x0004
| 信息域 | 握手字（2 个字节）
查询命令 | 命令 | 0xc9b0 | 长度 | 0x002c
| 信息域 | 握手字（2 个字节）；应答结果（1 个字节）；均充电压（4 字节 浮点数）；浮充电压（4 字节浮点数）；负载下电允许状态（1 个字节）；电池下电允许状态（1 个字节）；负载下电电压（4 字节浮点数）；电池组下电电压（4 字节浮点数）；低温启动负 载下电允许状态（1 个字节）；低温启动负载下电温度（4 字节浮 点数）；交流过压告警点（4 字节浮点数）；交流欠压告警点（4 字节浮点数）；直流过压告警点（4 字节浮点数）；直流欠压告 警点（4 字节浮点数）

第 42 页 共 49 页

附录 A：标准 C 浮点数格式（IEEE 32 位浮点数）

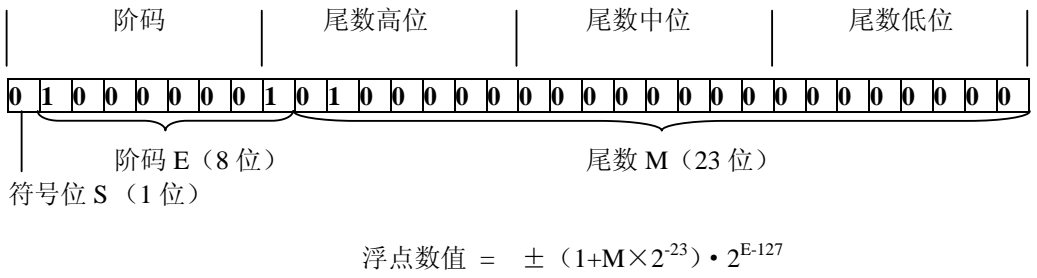
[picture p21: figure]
尾数高位; 尾数中位; 尾数低位; 符号位 S （1 位）; 浮点数值 = ±（1+M×2⁻²³）·2E-127

浮点数的正负取决于符号位 S 的值，S=1 表示浮点数为负，S=0 则浮点数为正。 例如：当 32 位浮点数为 40H，A0H，00H，00H 时（如上所示），即 S=0，E=129，M=2²¹， 则: 浮点数值 = （1 + 2²¹×2⁻²³）·2¹²⁹⁻¹²⁷ = 5.0

第 43 页 共 49 页

# 附录 B：状态字节定义

限流状态：AAH－正在限流；55H－不限流。

电源系统控制命令受控状态：AAH－受主节点控制；55H－从节点自动控制。

充放电状态：AAH-均充；55H-浮充；00H-强制均充；FFH-放电。2005-6-30 修改

负载下电允许状态：AAH－允许；55H－禁止。

电池下电允许状态：AAH－允许；55H－禁止。

电池放电测试阶段：00H—充电；AAH—放电；55H—记录；FFH—结束；

电源模块类型：有效值 00H～0FH ；AAH－没有配置；0——AC/DC；1——DC/DC；后面的

先保留。

电源模块数量：有效值 0～10。

电源模块插槽位置：有效值 1～10；AAH－没有配置。

第 44 页 共 49 页

# 附录 C：告警量字节定义

市电状态：FFH-市电正常；AAH-市电无；55-市电缺相。

市电过欠压：FFH-正常；AAH-过压；55H-欠压。

母排电压过欠压：FFH-正常；AAH-过压；55H-欠压。

负载上下电：FFH-上电；01H-低压下电；02H-后台控制下电；04H-高温下电。2005-6-28 增加。

电池上下电：FFH-上电；01H-低压下电；02H-后台控制下电；03H-本地手动下电；04H-

高温下电。2005-6-28 增加

电池组回路通断：FFH-通；AAH-断。

环境温度：FFH-正常；AAH-过高；55H-过低。

环境湿度：FFH-正常；AAH-过高；55H-过低。

电池组温度：FFH-正常；AAH-过高；55H-过低。2005-6-25 增加

门磁：FFH-正常；AAH-告警。

水浸：FFH-正常；AAH-告警。

烟感：FFH-正常；AAH-告警。

电源模块告警：00 – 后台未配置；FF-正常；AA-通讯失败或者模块不在位；55-关机；A5-

故障；5A-保护或者风扇故障；A0-非法。

充电过流状态：FFH-正常；AAH-过流。

蓄电池不平衡告警：FFH-正常；01H-第一串蓄电池不平衡；02H-第二串蓄电池不平衡；

AAH-两串蓄电池均不平衡。

# 附录 D：生产日期信息定义

电源模块插槽位置：有效值 1～10；AAH－模块通信失败或模块不在位。

生产日期：年 1 字节；月 1 字节；日 1 字节。

对于通信故障或不在位的槽位号，生产日期为全 0，生产厂家为 0。

第 45 页 共 49 页

# 附录 E：充放电次数信息定义

停电次数：两个字节；

充电次数：按充电时间进行统计，共分10段，每段两个字节，共20字节，格式如下：

放电次数：按放电时间进行统计，共分10段，每段两个字节，共20字节，格式如下：

注：

1、充放电次数为 2 字节整形数，发送时先发送高位字节，再发送低位字节。

2、充放电次数清零说明：当上位机下发蓄电池安装时间，且下发的安装时间与前次安装时间不相

同时将充放电次数清零。2005-7-4

# 附录 F：协议扩展索引与参数定义

索引 | 参数说明 | 备注
0x0200 | BYTE1－电池组剩余容量百分比，其他保留。 | 只适用获取命令，若电池组路数 为 0，上报 0x00。
0x0201 | BYTE1－光藕 1 输出控制（1 个字节；AAH-截止；55H-导通）；其他保留。
0x0202 | BYTE1－光藕 2 输出控制（1 个字节；AAH-截止；55H-导通）；其他保留。

注：

参数索引为 2 字节整形数，发送时先发送高位字节，再发送低位字节。

30 分钟内的放

电次数

30 分钟～1

小时内的放
电次数

7～8 小时内

的放电次数

8 小时以上的

放电次数

1～2 小时内

的放电次数

30 分钟内的
充电次数

30 分钟～1

小时内的充
电次数

7～8 小时内
的充电次数

8 小时以上的
充电次数

1～2 小时内

的充电次数

第 46 页 共 49 页

备注没有说明的索引获取和设置命令都适用

# 附录 G：浮点数分辨率定义

参数名称 | 最小分辨率定义
交流电压 | 1V
直流电压 | 0.1V
电流 | 0.1A
蓄电池容量 | 1Ah
温度 | 1℃
湿度 | 1％
充电限流点 | 0.01
温度补偿系数 | 1mV
0.1C～1C 放电时间 | 0.01 小时
放电测试终止电压 | 0.01V
放电测试时限 | 1 小时
放电持续时间 | 0.01 小时
充电效率 | 0.01（1％）
电压测量参考基准 | 0.1V
校准系数 | 0.01
零点漂移 | 0.1V/A

# 附录 H：配置参数恢复缺省值命令涉及的参数定义

序号 | 协议参数 | 是否恢复默认值
1 | 均充电压（4 字节浮点数；有效范围 43.2~57.6，且大于浮充电压小于直流过压 告警点-1V，缺省 56.5V） | 是
2 | 浮充电压（4 字节浮点数； 有效范围 43.2~57.6，且大于(直流欠压告警点+2)V 小于均充电压，缺省 53.5V） | 是

第 47 页 共 49 页

3 | 充电限流点系数（4 字节浮点数；有效范围 0.05~0.25，缺省 0.15） | 是
4 | 电池组 1 容量（4 字节浮点数；有效范围 30~1000AH，缺省 65AH） | 否
5 | 电池组 2 容量（4 个字节，保留） | 否
6 | 电池组路数（1 个字节；有效范围 0~1，缺省 1） | 否
7 | 定时均充时间（1 个字节；有效范围 30~240 天，缺省 60 天） | 是
8 | 负载下电允许状态（1 个字节；AAH－允许，55H－禁止，缺省 55H） | 是
9 | 电池下电允许状态（1 个字节；AAH－允许，55H－禁止，缺省 AAH） | 是
10 | 负载下电电压（4 字节浮点数；有效范围电池下电电压~直流欠压告警点，缺省 44V） | 是
11 | 电池组下电电压（4 字节浮点数；有效范围 35V~负载下电电压，缺省 43V） | 是
12 | 低温启动负载下电允许状态（1 个字节；AAH－允许，55H－禁止，缺省 55H）； | 是
13 | 低温启动负载下电温度（4 字节浮点数；有效范围-40~0℃，缺省-10℃） | 是
14 | 电池组温度 1 传感器测量上限（4 字节浮点数，为传感器最大输出信号对应的 温度值，有效设置范围 0~100℃，缺省值为 80 ℃） | 否
15 | 电池组温度 1 传感器测量下限（4 字节浮点数，为传感器最小输出信号对应的 温度值，有效设置范围-50℃~0，缺省值为-20 ℃。） | 否
16 | 电池组温度 1 过高告警点（4 字节浮点数，有效设置范围-50~100℃，缺省值为 50℃） | 是
17 | 电池组温度 1 过低告警点（4 字节浮点数，有效设置范围-50~100℃，且小于过 高告警点，缺省值为 0℃） | 是
18 | 电池组温度 2 传感器测量上限（4 字节浮点数） | 否
19 | 电池组温度 2 传感器测量下限（4 字节浮点数） | 否
20 | 电池组温度 2 过高告警点（4 字节浮点数） | 是
21 | 电池组温度 2 过低告警点（4 字节浮点数） | 是
22 | 温度补偿系数（4 字节浮点数；为电池组温度每变化 1 ℃电池组浮充电压变化 值，有效设置范围 0~500mV。缺省值为 80mV） | 是
23 | 电池温度补偿依据的温度（1 个字节，AAH-电池组温度 1，55H-电池组温度 2， 缺省值为 AAH） | 是
24 | 电源模块数量（1 个字节；有效范围 0～10，缺省 9） | 否
25 | 电源模块 1～10 插槽位置（每模块 1 个字节，共 10 字节；有效范围 1～10, 不 可重复） | 否
26 | 交流过压告警点（4 字节浮点数；有效设置范围欠压告警点~300，缺省值 280V） | 是
27 | 交流欠压告警点（4 字节浮点数； 有效设置范围 60~过压告警点，且小于交流 过压告警点。缺省值 180V） | 是
28 | 直流过压告警点（4 字节浮点数；有效设置范围 58~60，且大于（均充电压+1） V, 缺省值 58V） | 是
29 | 直流欠压告警点（4 字节浮点数；有效设置范围下电电压~(浮充电压-2)V，且 小于直流过压告警点。缺省值 45V） | 是
30 | 环境温度测量上限（4 字节浮点数，为传感器最大输出信号时对应的温度值， 有效设置范围 0~100℃，缺省值为 80 ℃） | 否
31 | 环境温度测量下限（4 字节浮点数，为传感器最小输出信号时对应的温度值， | 否

第 48 页 共 49 页

| 有效设置范围-50℃~0，且小于温度测量上限，缺省值为-20 ℃）
32 | 环境温度过高告警点（4 字节浮点数，有效设置范围-50~100℃，缺省值为 50 ℃） | 是
33 | 环境温度过低告警点（4 字节浮点数，有效设置范围-50~100℃，缺省值为 0℃） | 是
34 | 环境湿度测量上限（4 字节浮点数，为传感器最大输出信号时对应的湿度值， 有效设置范围 0~100，缺省值为 100） | 否
35 | 环境湿度测量下限（4 字节浮点数，为传感器最小输出信号时对应的湿度值， 有效设置范围 0~100，且小于湿度测量上限，缺省值为 0） | 否
36 | 环境湿度过高告警点（4 字节浮点数，有效设置范围 0~100，缺省值为 80） | 是
37 | 环境湿度过低告警点（4 字节浮点数，有效设置范围 0~100，且小于湿度告警 上限，缺省值为 10） | 是
38 | 备用模拟量 1~6 的告警上限（保留，每个模拟量 1 个字节共 6 字节，有效设置 范围 0~FEH） | 否
39 | 备用模拟量 1~6 的告警下限（保留，每个模拟量 1 个字节共 6 字节，有效设置 范围 0~FE H 且小于告警上限） | 否
40 | 备用开关量 1~7 告警电平（每个开关量 1 个字节共 7 字节，01H-高电平告警， 00H-低电平告警，缺省值为 01H） | 否
41 | 电压测量基准（4 字节浮点数，有效范围 3.0±20%，缺省为 3V） | 是
42 | 交流电压校准系数；直流电压校准系数；负载电流校准系数；电池电流校准系 数；（有效设置范围为 1.0±20%，缺省为 1.0） | 是
43 | 交流电压零点漂移；直流电压零点漂移；负载电流零点漂移；电池电流零点漂 移；（设置范围为-0.5（V 或 A）—+0.5（V 或 A），缺省为 0） | 是
44 | 功能码（1 字节，1－定时自动测试允许；2－掉电自动测试允许；3－定时自动 测试+掉电自动测试允许；55H－自动测试禁止，缺省值：2） | 是
45 | 定时放电测试时间（1 个字节：30～240 天；缺省值：120）；停电或后台控制 后延迟放电测试（1 个字节：1～60 天；缺省值：14） | 是
46 | 市电状态告警级别（缺省：AAH）；市电过欠压告警级别（缺省：55H）；直流 输出过欠压告警级别（缺省：AAH）；负载下电告警级别（缺省：AAH）；电 池下电告警级别（缺省：AAH）；电池回路空开断告警级别（缺省：AAH）； 环境温度异常告警级别（缺省：55H）；环境湿度异常告警级别（缺省：00H）； 电池温度异常告警级别（缺省：55H）；门禁异常告警级别（缺省：55H）；水 浸告警级别（缺省：AAH）；烟雾告警级别（缺省：AAH）；整流模块故障告 警级别（缺省：AAH）；整流模块保护告警级别（缺省：55H）；整流模块通讯 失败告警级别（缺省：55H）；充电过流告警级别（缺省：55H）；备用开关量 1～ 7 告警级别（每个开关量 1 个字节共 7 字节，缺省：55H）；保留字节（20 字节， 不处理，缺省为 0） | 全部是
47 | 负载高温下电使能控制（1 字节：AAH—允许，55H—禁止，缺省 55H） | 是
48 | 负载高温下电的温度（1 字节，设置范围 50℃~70℃，缺省为 65℃） | 是
49 | 电池高温下电使能控制（1 字节：AAH—允许，55H—禁止，缺省 55H） | 是
50 | 电池高温下电的温度（1 字节，设置范围 40℃~70℃，缺省为 53℃） | 是
51 | 0.05C10 放电时间（4 字节浮点数，单位：小时；缺省值：12.00）； | 是

第 49 页 共 49 页

| 0.1C10 放电时间（4 字节浮点数，单位：小时；缺省值：6.00）； 0.2C10 放电时间（4 字节浮点数，单位：小时；缺省值：3.00）； 0.3C10 放电时间（4 字节浮点数，单位：小时；缺省值：1.50）； 0.4C10 放电时间（4 字节浮点数，单位：小时；缺省值：1.00）； 0.5C10 放电时间（4 字节浮点数，单位：小时；缺省值：0.70）； 0.6C10 放电时间（4 字节浮点数，单位：小时；缺省值：0.50）； 0.7C10 放电时间（4 字节浮点数，单位：小时；缺省值：0.40）； 0.8C10 放电时间（4 字节浮点数，单位：小时；缺省值：0.30）； 0.9C10 放电时间（4 字节浮点数，单位：小时；缺省值：0.25）； 电池组充电效率（4 字节浮点数，设置范围 0.8～1.0；默认值：0.80）； 放电测试终止电压（4 字节浮点数，1.7~2.2，单位：V/cell；缺省值：1.9）； 电池组电池数量（1 字节，1~50，单位：cell；缺省值：24）； 放电测试时限（4 字节浮点数：1～100 小时，缺省值：10）； 简化放电测试终止电压（4 字节浮点数：40～54V；缺省值：45V）；简化放电 测试时限（1 字节：1～240 分钟；缺省值：60）
52 | 设置的年份减去 2000（1 字节：设置范围 0～127，缺省 05）；设置的月份（1 字节，设置范围 1～12，缺省 01）；设置的日期（1 字节，设置范围 1～31，缺 省 01） | 否

# 附录 I：整流模块输出信息查询 2005-10-19 增加

模块输出信息查询命令定义（保留给供应商的命令）：
下发命令 | 命令 | 0xc9F8 | 长度 | 0x0004
| 信息域 | 握手字（2 个字节）；
查询命令 | 命令 | 0xc9F8 | 长度 | 0x005F
| 信息域 | 握手字（2 个字节）；应答结果（1 个字节）；整流模块输出（共 90 个字节，整流模块槽位 1 个字节，输出电压 4 个字节浮点数， 输出电流 4 个字节浮点数，共 10 个整流模块）

说明：

1、整流模块槽位：1～10，未配置和通讯故障模块为 AAH。

2、未配置或通讯故障模块电压电流上报 0xff，其他上报模块实际输出电压和电流。

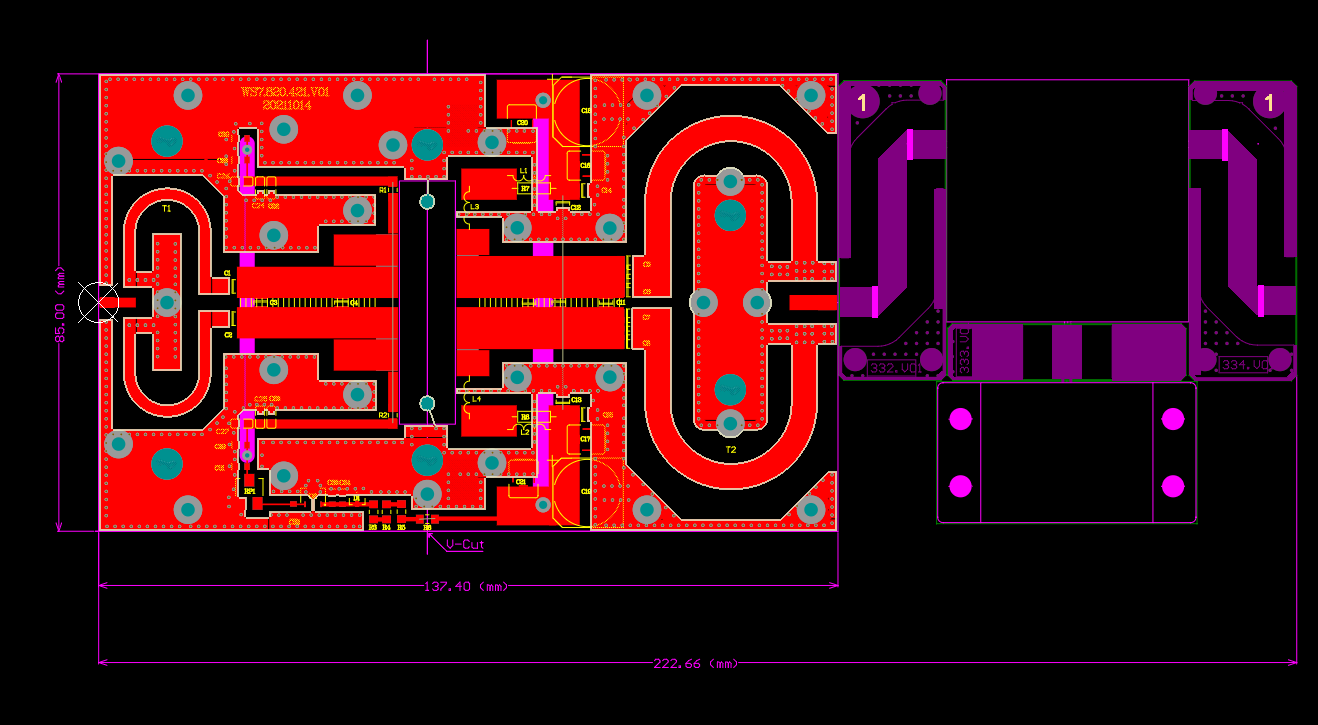
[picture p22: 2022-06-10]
接线图/驱动插件/功放模块资料/WS7.820.421.V02.png

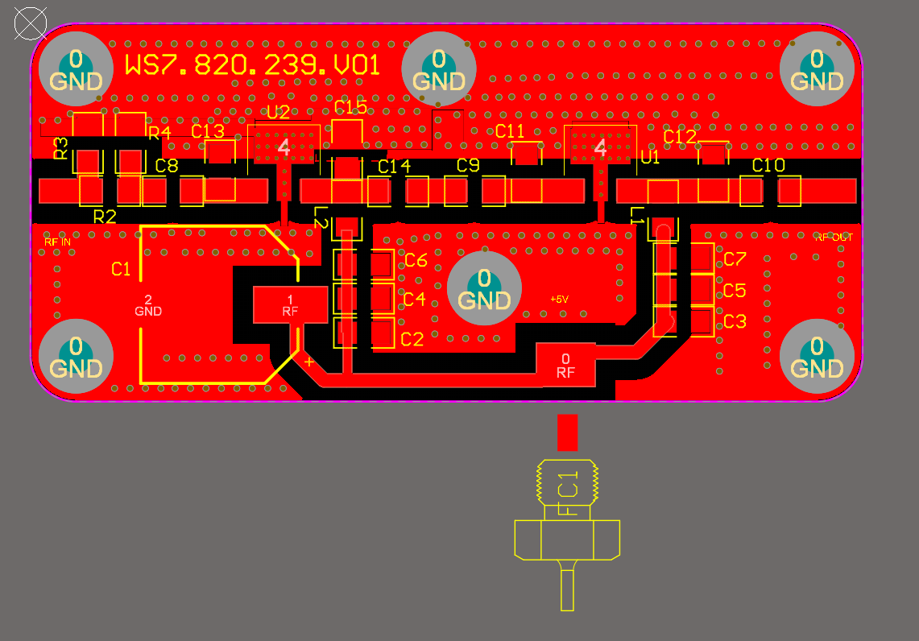
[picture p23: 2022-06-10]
接线图/驱动插件/功放模块资料/WS7.820.239.V01.png

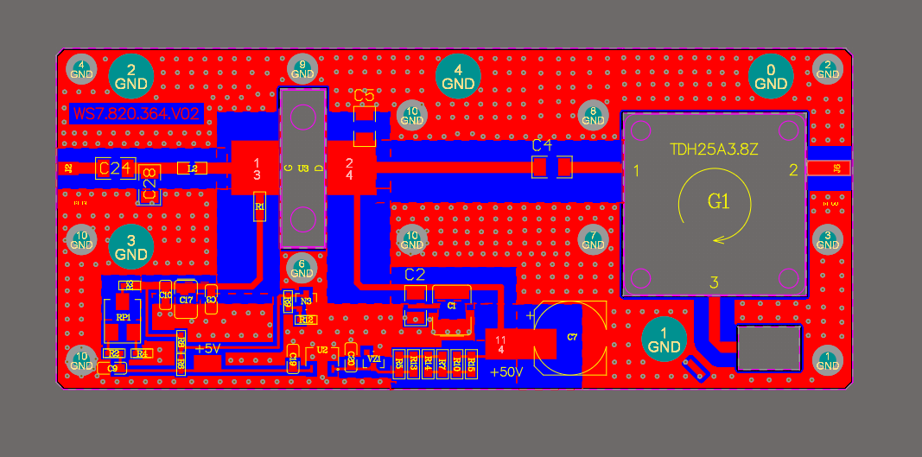
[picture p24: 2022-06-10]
接线图/驱动插件/功放模块资料/WS7.820.364.V02.png

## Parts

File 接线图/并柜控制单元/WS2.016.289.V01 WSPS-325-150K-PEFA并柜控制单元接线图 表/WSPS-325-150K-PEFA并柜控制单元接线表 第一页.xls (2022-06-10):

 |  | WSPS-325-150K-PEFA并柜控制单元接线表 第一页
序号 | 代号 | 名称 | 数量 | 备注 | 更改
1 | INPD OUT | 输入检波输出接口 | 1
2 | FPQ | 分配器 | 1
3 | RF IN | 射频驶入 | 1
4 | XHCL | 信号处理模块 | 1
5 | KZ | 控制模块 | 1
6 | ACDC1 | 75W电源 | 1
7 | ACDC2 | 320W电源 | 1
8 | ALARM | 告警接口 | 1
9 | PWM IN | PWM信号输入 | 1
10 | FS1~FS2 | 风扇 | 2
11 | 24VDC OUT1~24VDC OUT2 | 24V输出 | 2
12 | AC IN | 交流输入 | 1
13
14
15
16
17
18
19
20
21
拟制：李玲 2022.04.27 审核： 批准：

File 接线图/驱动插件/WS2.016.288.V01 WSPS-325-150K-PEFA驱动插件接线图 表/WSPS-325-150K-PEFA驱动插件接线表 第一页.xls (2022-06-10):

 |  | WSPS-325-150K-PEFA驱动插件接线表 第一页
序号 | 代号 | 名称 | 数量 | 备注 | 更改
1 | STATE LED | 状态灯信号接口 | 1
2 | 24VDC OUT | 24V输出 | 1
3 | KZ | 控制模块 | 1
4 | AC IN | 交流输入 | 1
5 | ACDC1~ACDC3 | 75W电源 | 3
6 | FS1~FS5 | 风扇 | 1
7 | 50VDC IN | 50V输入 | 1
8 | WKZJB | 百兆网口转接板 | 1
9 | GF1~GF4 | 功放模块 | 4
10 | FPQ | 分配器 | 1
11 | JKMK | 接口模块 | 1
12 | C1~C2 | 电解电容 | 2
13
14
15
16
17
18
19
20
21
拟制：李玲 2022.05.05 审核： 批准：

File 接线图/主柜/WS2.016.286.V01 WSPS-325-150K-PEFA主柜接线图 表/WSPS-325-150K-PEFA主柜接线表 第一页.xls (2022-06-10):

 |  | WSPS-325-150K-PEFA主柜接线表 第一页
序号 | 代号 | 名称 | 数量 | 备注 | 更改
1 | TPV+ | 正极铜排 | 1
2 | TPV- | 负极铜排 | 1
3 | PA1~PA12 | 功放插件背板 | 12
4 | FPQ1~FPQ2 | 1分6分配器 | 2
5 | HCQ1~HCQ2 | 6合1合成器 | 2
6 | HCQ3 | 2合1合成器 | 1
7 | OH | 耦合器 | 1
8 | SW | 交换机 | 1
9 | SW1 | 五口交换机 | 1
10 | SW2 | 八口交换机 | 1
11 | QDHMB | 驱动插件面板 | 1
12 | QDCMB | 驱动插件侧面板 | 1
13 | LCD | 显示屏 | 1
14 | LED | 一体三色报警灯 | 1
15 | KZZMB | 控制单元左面板 | 1
16 | KZYMB | 控制单元右面板 | 1
17 | KZQMB | 控制单元前面板 | 1
18 | KZHMB | 控制单元后面板 | 1
19 | GK | 工控机 | 1
20 | MB | 机柜面板 | 1
21 | DC | 直流指示灯 | 1
22 | COMM | 通信指示灯 | 1
23 | ALARM | 告警指示灯 | 1
24 | FS1~FS25 | 风扇 | 1
25 | ACDC | 320W电源 | 1
26 | AC IN | 直流输入 | 1
27 | KK | 空气开关 | 1
28 | JLLBQ | 交流滤波器 | 1
29 | BLQ | 避雷器 | 1
30 | GD | 固态继电器 | 1
31 | JXP1~JXP2 | 接线排 | 2
32 | PO1~PO3 | 电源背板 | 3
33 | CZ1~CZ3 | 航空插座 | 3
34 | KG | 急停 | 1
35
36
37
拟制：李玲 2022.06.02 审核： 批准：

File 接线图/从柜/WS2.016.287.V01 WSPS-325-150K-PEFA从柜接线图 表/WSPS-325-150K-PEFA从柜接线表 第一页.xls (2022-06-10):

 |  | WSPS-325-150K-PEFA从柜接线表 第一页
序号 | 代号 | 名称 | 数量 | 备注 | 更改
1 | TPV+ | 正极铜排 | 1
2 | TPV- | 负极铜排 | 1
3 | PA1~PA12 | 功放插件背板 | 12
4 | FPQ1~FPQ2 | 1分6分配器 | 2
5 | HCQ1~HCQ2 | 6合1合成器 | 2
6 | HCQ3 | 2合1合成器 | 1
7 | OH | 耦合器 | 1
8 | SW | 交换机 | 1
9 | SW1 | 5口交换机 | 1
10 | QDHMB | 驱动插件面板 | 1
11 | QDCMB | 驱动插件侧面板 | 1
12 | MB | 正极面板 | 1
13 | DC | 直流指示灯 | 1
14 | COMM | 通信指示灯 | 1
15 | ALARM | 告警指示灯 | 1
16 | FS1~FS25 | 风扇 | 1
17 | ACDC | 320W电源 | 1
18 | AC IN | 直流输入 | 1
19 | KK | 空气开关 | 1
20 | JLLBQ | 交流滤波器 | 1
21 | BLQ | 避雷器 | 1
22 | GD | 固态继电器 | 1
23 | JXP1~JXP2 | 接线排 | 2
24 | PO1~PO3 | 电源背板 | 3
25 | CZ1~CZ3 | 航空插座 | 3
26
27
28
29
拟制：李玲 2022.05.12 审核： 批准：

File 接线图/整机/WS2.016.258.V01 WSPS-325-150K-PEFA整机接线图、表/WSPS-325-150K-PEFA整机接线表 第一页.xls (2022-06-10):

 |  | WSPS-325-150K-PEFA整机接线表 第一页
序号 | 代号 | 名称 | 数量 | 备注 | 更改
1 | ZG | 主柜 | 1
2 | JG2~JG4 | 从柜 | 3
3 | HCQ1~HCQ3 | 同轴合成器 | 3
4 | OH | 耦合器 | 1
5
6
7
8
9
10
11
12
13
14
15
16
17
18
19
20
21
拟制：李玲 2022.06.01 审核： 批准：

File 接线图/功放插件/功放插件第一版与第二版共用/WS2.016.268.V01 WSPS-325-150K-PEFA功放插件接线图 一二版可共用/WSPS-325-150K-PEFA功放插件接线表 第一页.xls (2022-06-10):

 |  | WSPS-325-150K-PEFA功放插件接线表 第一页
序号 | 代号 | 名称 | 数量 | 备注 | 更改
1 | PI | 电源输入插座 | 1
2 | HCQ | 4合1合成器 | 1
3 | GF1~GF4 | 末级功放模块 | 4
4 | FPQ | 分配器 | 1
5 | KZ | 接口模块 | 1
6 | DB | 灯板 | 1
7 | NRI | 射频输入接口 | 1
8 | WD | 温度传感器 | 1
9 | C1~C4 | 电解电容 | 4
10
11
12
13
14
15
16
17
18
19
20
21
拟制：李玲 2022.01.05 审核： 批准：

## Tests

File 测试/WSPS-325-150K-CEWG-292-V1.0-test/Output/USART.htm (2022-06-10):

# Static Call Graph for image ..\..\Output\USART.axf

#<CALLGRAPH># ARM Linker, 5060960: Last Updated: Sat Jan 22 16:15:17 2022

### Maximum Stack Usage = 408 bytes + Unknown(Cycles, Untraceable Function Pointers)

### Call chain for Maximum Stack Depth:

main ⇒ TCP_TopServer ⇒ remote_RJ45_reseive ⇒ work_RJ45send_buff ⇒ sendto_top ⇒ send_data_processing_top ⇒ wiz_write_buf_top ⇒ SPI2_SendByte

### Mutually Recursive functions

- ADC_IRQHandler ⇒ ADC_IRQHandler

### Function Pointers

- ADC_IRQHandler from startup_stm32f429_439xx.o(.text) referenced from startup_stm32f429_439xx.o(RESET)
- BusFault_Handler from stm32f4xx_it.o(i.BusFault_Handler) referenced from startup_stm32f429_439xx.o(RESET)
- CAN1_RX0_IRQHandler from startup_stm32f429_439xx.o(.text) referenced from startup_stm32f429_439xx.o(RESET)
- CAN1_RX1_IRQHandler from startup_stm32f429_439xx.o(.text) referenced from startup_stm32f429_439xx.o(RESET)
- CAN1_SCE_IRQHandler from startup_stm32f429_439xx.o(.text) referenced from startup_stm32f429_439xx.o(RESET)
- CAN1_TX_IRQHandler from startup_stm32f429_439xx.o(.text) referenced from startup_stm32f429_439xx.o(RESET)
- CAN2_RX0_IRQHandler from startup_stm32f429_439xx.o(.text) referenced from startup_stm32f429_439xx.o(RESET)
- CAN2_RX1_IRQHandler from startup_stm32f429_439xx.o(.text) referenced from startup_stm32f429_439xx.o(RESET)
- CAN2_SCE_IRQHandler from startup_stm32f429_439xx.o(.text) referenced from startup_stm32f429_439xx.o(RESET)
- CAN2_TX_IRQHandler from startup_stm32f429_439xx.o(.text) referenced from startup_stm32f429_439xx.o(RESET)
- CRYP_IRQHandler from startup_stm32f429_439xx.o(.text) referenced from startup_stm32f429_439xx.o(RESET)
- DCMI_IRQHandler from startup_stm32f429_439xx.o(.text) referenced from startup_stm32f429_439xx.o(RESET)
- DMA1_Stream0_IRQHandler from startup_stm32f429_439xx.o(.text) referenced from startup_stm32f429_439xx.o(RESET)
- DMA1_Stream1_IRQHandler from bsp_usart.o(i.DMA1_Stream1_IRQHandler) referenced from startup_stm32f429_439xx.o(RESET)
- DMA1_Stream2_IRQHandler from startup_stm32f429_439xx.o(.text) referenced from startup_stm32f429_439xx.o(RESET)
- DMA1_Stream3_IRQHandler from bsp_usart.o(i.DMA1_Stream3_IRQHandler) referenced from startup_stm32f429_439xx.o(RESET)
- DMA1_Stream4_IRQHandler from startup_stm32f429_439xx.o(.text) referenced from startup_stm32f429_439xx.o(RESET)
- DMA1_Stream5_IRQHandler from bsp_usart.o(i.DMA1_Stream5_IRQHandler) referenced from startup_stm32f429_439xx.o(RESET)
- DMA1_Stream6_IRQHandler from bsp_usart.o(i.DMA1_Stream6_IRQHandler) referenced from startup_stm32f429_439xx.o(RESET)
- DMA1_Stream7_IRQHandler from startup_stm32f429_439xx.o(.text) referenced from startup_stm32f429_439xx.o(RESET)
- DMA2D_IRQHandler from startup_stm32f429_439xx.o(.text) referenced from startup_stm32f429_439xx.o(RESET)
- DMA2_Stream0_IRQHandler from startup_stm32f429_439xx.o(.text) referenced from startup_stm32f429_439xx.o(RESET)
- DMA2_Stream1_IRQHandler from startup_stm32f429_439xx.o(.text) referenced from startup_stm32f429_439xx.o(RESET)
- DMA2_Stream2_IRQHandler from startup_stm32f429_439xx.o(.text) referenced from startup_stm32f429_439xx.o(RESET)
- DMA2_Stream3_IRQHandler from startup_stm32f429_439xx.o(.text) referenced from startup_stm32f429_439xx.o(RESET)
- DMA2_Stream4_IRQHandler from startup_stm32f429_439xx.o(.text) referenced from startup_stm32f429_439xx.o(RESET)
- DMA2_Stream5_IRQHandler from bsp_usart.o(i.DMA2_Stream5_IRQHandler) referenced from startup_stm32f429_439xx.o(RESET)
- DMA2_Stream6_IRQHandler from startup_stm32f429_439xx.o(.text) referenced from startup_stm32f429_439xx.o(RESET)
- DMA2_Stream7_IRQHandler from bsp_usart.o(i.DMA2_Stream7_IRQHandler) referenced from startup_stm32f429_439xx.o(RESET)
- DebugMon_Handler from stm32f4xx_it.o(i.DebugMon_Handler) referenced from startup_stm32f429_439xx.o(RESET)
- ETH_IRQHandler from startup_stm32f429_439xx.o(.text) referenced from startup_stm32f429_439xx.o(RESET)
- ETH_WKUP_IRQHandler from startup_stm32f429_439xx.o(.text) referenced from startup_stm32f429_439xx.o(RESET)
- EXTI0_IRQHandler from startup_stm32f429_439xx.o(.text) referenced from startup_stm32f429_439xx.o(RESET)
- EXTI15_10_IRQHandler from startup_stm32f429_439xx.o(.text) referenced from startup_stm32f429_439xx.o(RESET)
- EXTI1_IRQHandler from startup_stm32f429_439xx.o(.text) referenced from startup_stm32f429_439xx.o(RESET)
- EXTI2_IRQHandler from startup_stm32f429_439xx.o(.text) referenced from startup_stm32f429_439xx.o(RESET)
- EXTI3_IRQHandler from startup_stm32f429_439xx.o(.text) referenced from startup_stm32f429_439xx.o(RESET)
- EXTI4_IRQHandler from startup_stm32f429_439xx.o(.text) referenced from startup_stm32f429_439xx.o(RESET)
- EXTI9_5_IRQHandler from startup_stm32f429_439xx.o(.text) referenced from startup_stm32f429_439xx.o(RESET)
- FLASH_IRQHandler from startup_stm32f429_439xx.o(.text) referenced from startup_stm32f429_439xx.o(RESET)
- FMC_IRQHandler from startup_stm32f429_439xx.o(.text) referenced from startup_stm32f429_439xx.o(RESET)
- FPU_IRQHandler from startup_stm32f429_439xx.o(.text) referenced from startup_stm32f429_439xx.o(RESET)
- HASH_RNG_IRQHandler from startup_stm32f429_439xx.o(.text) referenced from startup_stm32f429_439xx.o(RESET)
- HardFault_Handler from stm32f4xx_it.o(i.HardFault_Handler) referenced from startup_stm32f429_439xx.o(RESET)
- I2C1_ER_IRQHandler from startup_stm32f429_439xx.o(.text) referenced from startup_stm32f429_439xx.o(RESET)
- I2C1_EV_IRQHandler from startup_stm32f429_439xx.o(.text) referenced from startup_stm32f429_439xx.o(RESET)
- I2C2_ER_IRQHandler from startup_stm32f429_439xx.o(.text) referenced from startup_stm32f429_439xx.o(RESET)
- I2C2_EV_IRQHandler from startup_stm32f429_439xx.o(.text) referenced from startup_stm32f429_439xx.o(RESET)
- I2C3_ER_IRQHandler from startup_stm32f429_439xx.o(.text) referenced from startup_stm32f429_439xx.o(RESET)
- I2C3_EV_IRQHandler from startup_stm32f429_439xx.o(.text) referenced from startup_stm32f429_439xx.o(RESET)
- LTDC_ER_IRQHandler from startup_stm32f429_439xx.o(.text) referenced from startup_stm32f429_439xx.o(RESET)
- LTDC_IRQHandler from startup_stm32f429_439xx.o(.text) referenced from startup_stm32f429_439xx.o(RESET)
- MemManage_Handler from stm32f4xx_it.o(i.MemManage_Handler) referenced from startup_stm32f429_439xx.o(RESET)
- NMI_Handler from stm32f4xx_it.o(i.NMI_Handler) referenced from startup_stm32f429_439xx.o(RESET)
- OTG_FS_IRQHandler from startup_stm32f429_439xx.o(.text) referenced from startup_stm32f429_439xx.o(RESET)
- OTG_FS_WKUP_IRQHandler from startup_stm32f429_439xx.o(.text) referenced from startup_stm32f429_439xx.o(RESET)
- OTG_HS_EP1_IN_IRQHandler from startup_stm32f429_439xx.o(.text) referenced from startup_stm32f429_439xx.o(RESET)
- OTG_HS_EP1_OUT_IRQHandler from startup_stm32f429_439xx.o(.text) referenced from startup_stm32f429_439xx.o(RESET)
- OTG_HS_IRQHandler from startup_stm32f429_439xx.o(.text) referenced from startup_stm32f429_439xx.o(RESET)
- OTG_HS_WKUP_IRQHandler from startup_stm32f429_439xx.o(.text) referenced from startup_stm32f429_439xx.o(RESET)
- PVD_IRQHandler from startup_stm32f429_439xx.o(.text) referenced from startup_stm32f429_439xx.o(RESET)
- PendSV_Handler from stm32f4xx_it.o(i.PendSV_Handler) referenced from startup_stm32f429_439xx.o(RESET)
- RCC_IRQHandler from startup_stm32f429_439xx.o(.text) referenced from startup_stm32f429_439xx.o(RESET)
- RTC_Alarm_IRQHandler from startup_stm32f429_439xx.o(.text) referenced from startup_stm32f429_439xx.o(RESET)
- RTC_WKUP_IRQHandler from startup_stm32f429_439xx.o(.text) referenced from startup_stm32f429_439xx.o(RESET)
- Reset_Handler from startup_stm32f429_439xx.o(.text) referenced from startup_stm32f429_439xx.o(RESET)
- SAI1_IRQHandler from startup_stm32f429_439xx.o(.text) referenced from startup_stm32f429_439xx.o(RESET)
- SDIO_IRQHandler from startup_stm32f429_439xx.o(.text) referenced from startup_stm32f429_439xx.o(RESET)
- SPI1_IRQHandler from startup_stm32f429_439xx.o(.text) referenced from startup_stm32f429_439xx.o(RESET)
- SPI2_IRQHandler from startup_stm32f429_439xx.o(.text) referenced from startup_stm32f429_439xx.o(RESET)
- SPI3_IRQHandler from startup_stm32f429_439xx.o(.text) referenced from startup_stm32f429_439xx.o(RESET)
- SPI4_IRQHandler from startup_stm32f429_439xx.o(.text) referenced from startup_stm32f429_439xx.o(RESET)
- SPI5_IRQHandler from startup_stm32f429_439xx.o(.text) referenced from startup_stm32f429_439xx.o(RESET)
- SPI6_IRQHandler from startup_stm32f429_439xx.o(.text) referenced from startup_stm32f429_439xx.o(RESET)
- SVC_Handler from stm32f4xx_it.o(i.SVC_Handler) referenced from startup_stm32f429_439xx.o(RESET)
- SysTick_Handler from stm32f4xx_it.o(i.SysTick_Handler) referenced from startup_stm32f429_439xx.o(RESET)
- SystemInit from system_stm32f4xx.o(i.SystemInit) referenced from startup_stm32f429_439xx.o(.text)
- TAMP_STAMP_IRQHandler from startup_stm32f429_439xx.o(.text) referenced from startup_stm32f429_439xx.o(RESET)
- TIM1_BRK_TIM9_IRQHandler from startup_stm32f429_439xx.o(.text) referenced from startup_stm32f429_439xx.o(RESET)
- TIM1_CC_IRQHandler from startup_stm32f429_439xx.o(.text) referenced from startup_stm32f429_439xx.o(RESET)
- TIM1_TRG_COM_TIM11_IRQHandler from startup_stm32f429_439xx.o(.text) referenced from startup_stm32f429_439xx.o(RESET)
- TIM1_UP_TIM10_IRQHandler from startup_stm32f429_439xx.o(.text) referenced from startup_stm32f429_439xx.o(RESET)
- TIM2_IRQHandler from stm32f4xx_it.o(i.TIM2_IRQHandler) referenced from startup_stm32f429_439xx.o(RESET)
- TIM3_IRQHandler from startup_stm32f429_439xx.o(.text) referenced from startup_stm32f429_439xx.o(RESET)
- TIM4_IRQHandler from startup_stm32f429_439xx.o(.text) referenced from startup_stm32f429_439xx.o(RESET)
- TIM5_IRQHandler from startup_stm32f429_439xx.o(.text) referenced from startup_stm32f429_439xx.o(RESET)
- TIM6_DAC_IRQHandler from startup_stm32f429_439xx.o(.text) referenced from startup_stm32f429_439xx.o(RESET)
- TIM7_IRQHandler from startup_stm32f429_439xx.o(.text) referenced from startup_stm32f429_439xx.o(RESET)
- TIM8_BRK_TIM12_IRQHandler from startup_stm32f429_439xx.o(.text) referenced from startup_stm32f429_439xx.o(RESET)
- TIM8_CC_IRQHandler from startup_stm32f429_439xx.o(.text) referenced from startup_stm32f429_439xx.o(RESET)
- TIM8_TRG_COM_TIM14_IRQHandler from startup_stm32f429_439xx.o(.text) referenced from startup_stm32f429_439xx.o(RESET)
- TIM8_UP_TIM13_IRQHandler from startup_stm32f429_439xx.o(.text) referenced from startup_stm32f429_439xx.o(RESET)
- UART4_IRQHandler from startup_stm32f429_439xx.o(.text) referenced from startup_stm32f429_439xx.o(RESET)
- UART5_IRQHandler from startup_stm32f429_439xx.o(.text) referenced from startup_stm32f429_439xx.o(RESET)
- UART7_IRQHandler from startup_stm32f429_439xx.o(.text) referenced from startup_stm32f429_439xx.o(RESET)
- UART8_IRQHandler from startup_stm32f429_439xx.o(.text) referenced from startup_stm32f429_439xx.o(RESET)
- USART1_IRQHandler from bsp_usart.o(i.USART1_IRQHandler) referenced from startup_stm32f429_439xx.o(RESET)
- USART2_IRQHandler from bsp_usart.o(i.USART2_IRQHandler) referenced from startup_stm32f429_439xx.o(RESET)
- USART3_IRQHandler from bsp_usart.o(i.USART3_IRQHandler) referenced from startup_stm32f429_439xx.o(RESET)
- USART6_IRQHandler from startup_stm32f429_439xx.o(.text) referenced from startup_stm32f429_439xx.o(RESET)
- UsageFault_Handler from stm32f4xx_it.o(i.UsageFault_Handler) referenced from startup_stm32f429_439xx.o(RESET)
- WWDG_IRQHandler from startup_stm32f429_439xx.o(.text) referenced from startup_stm32f429_439xx.o(RESET)
- __main from entry.o(.ARM.Collect$$$$00000000) referenced from startup_stm32f429_439xx.o(.text)
- main from main.o(i.main) referenced from entry9a.o(.ARM.Collect$$$$0000000B)

### Global Symbols

__main (Thumb, 0 bytes, Stack size unknown bytes, entry.o(.ARM.Collect$$$$00000000))
[Address Reference Count : 1]

- startup_stm32f429_439xx.o(.text)

_main_stk (Thumb, 0 bytes, Stack size unknown bytes, entry2.o(.ARM.Collect$$$$00000001))

_main_scatterload (Thumb, 0 bytes, Stack size unknown bytes, entry5.o(.ARM.Collect$$$$00000004))

[Calls]

- >> __scatterload

__main_after_scatterload (Thumb, 0 bytes, Stack size unknown bytes, entry5.o(.ARM.Collect$$$$00000004))

[Called By]

- >> __scatterload

_main_clock (Thumb, 0 bytes, Stack size unknown bytes, entry7b.o(.ARM.Collect$$$$00000008))

_main_cpp_init (Thumb, 0 bytes, Stack size unknown bytes, entry8b.o(.ARM.Collect$$$$0000000A))

_main_init (Thumb, 0 bytes, Stack size unknown bytes, entry9a.o(.ARM.Collect$$$$0000000B))

__rt_lib_shutdown_fini (Thumb, 0 bytes, Stack size unknown bytes, entry12b.o(.ARM.Collect$$$$0000000E))

__rt_final_cpp (Thumb, 0 bytes, Stack size unknown bytes, entry10a.o(.ARM.Collect$$$$0000000F))

__rt_final_exit (Thumb, 0 bytes, Stack size unknown bytes, entry11a.o(.ARM.Collect$$$$00000011))

Reset_Handler (Thumb, 8 bytes, Stack size 0 bytes, startup_stm32f429_439xx.o(.text))
[Address Reference Count : 1]

- startup_stm32f429_439xx.o(RESET)

ADC_IRQHandler (Thumb, 0 bytes, Stack size 0 bytes, startup_stm32f429_439xx.o(.text))

[Calls]

- >> ADC_IRQHandler

[Called By]

- >> ADC_IRQHandler

[Address Reference Count : 1]

- startup_stm32f429_439xx.o(RESET)

CAN1_RX0_IRQHandler (Thumb, 0 bytes, Stack size 0 bytes, startup_stm32f429_439xx.o(.text))
[Address Reference Count : 1]

- startup_stm32f429_439xx.o(RESET)

CAN1_RX1_IRQHandler (Thumb, 0 bytes, Stack size 0 bytes, startup_stm32f429_439xx.o(.text))
[Address Reference Count : 1]

- startup_stm32f429_439xx.o(RESET)

CAN1_SCE_IRQHandler (Thumb, 0 bytes, Stack size 0 bytes, startup_stm32f429_439xx.o(.text))
[Address Reference Count : 1]

- startup_stm32f429_439xx.o(RESET)

CAN1_TX_IRQHandler (Thumb, 0 bytes, Stack size 0 bytes, startup_stm32f429_439xx.o(.text))
[Address Reference Count : 1]

- startup_stm32f429_439xx.o(RESET)

CAN2_RX0_IRQHandler (Thumb, 0 bytes, Stack size 0 bytes, startup_stm32f429_439xx.o(.text))
[Address Reference Count : 1]

- startup_stm32f429_439xx.o(RESET)

CAN2_RX1_IRQHandler (Thumb, 0 bytes, Stack size 0 bytes, startup_stm32f429_439xx.o(.text))
[Address Reference Count : 1]

- startup_stm32f429_439xx.o(RESET)

CAN2_SCE_IRQHandler (Thumb, 0 bytes, Stack size 0 bytes, startup_stm32f429_439xx.o(.text))
[Address Reference Count : 1]

- startup_stm32f429_439xx.o(RESET)

CAN2_TX_IRQHandler (Thumb, 0 bytes, Stack size 0 bytes, startup_stm32f429_439xx.o(.text))
[Address Reference Count : 1]

- startup_stm32f429_439xx.o(RESET)

CRYP_IRQHandler (Thumb, 0 bytes, Stack size 0 bytes, startup_stm32f429_439xx.o(.text))
[Address Reference Count : 1]

- startup_stm32f429_439xx.o(RESET)

DCMI_IRQHandler (Thumb, 0 bytes, Stack size 0 bytes, startup_stm32f429_439xx.o(.text))
[Address Reference Count : 1]

- startup_stm32f429_439xx.o(RESET)

DMA1_Stream0_IRQHandler (Thumb, 0 bytes, Stack size 0 bytes, startup_stm32f429_439xx.o(.text))
[Address Reference Count : 1]

- startup_stm32f429_439xx.o(RESET)

DMA1_Stream2_IRQHandler (Thumb, 0 bytes, Stack size 0 bytes, startup_stm32f429_439xx.o(.text))
[Address Reference Count : 1]

- startup_stm32f429_439xx.o(RESET)

DMA1_Stream4_IRQHandler (Thumb, 0 bytes, Stack size 0 bytes, startup_stm32f429_439xx.o(.text))
[Address Reference Count : 1]

- startup_stm32f429_439xx.o(RESET)

DMA1_Stream7_IRQHandler (Thumb, 0 bytes, Stack size 0 bytes, startup_stm32f429_439xx.o(.text))
[Address Reference Count : 1]

- startup_stm32f429_439xx.o(RESET)

DMA2D_IRQHandler (Thumb, 0 bytes, Stack size 0 bytes, startup_stm32f429_439xx.o(.text))
[Address Reference Count : 1]

- startup_stm32f429_439xx.o(RESET)

DMA2_Stream0_IRQHandler (Thumb, 0 bytes, Stack size 0 bytes, startup_stm32f429_439xx.o(.text))
[Address Reference Count : 1]

- startup_stm32f429_439xx.o(RESET)

DMA2_Stream1_IRQHandler (Thumb, 0 bytes, Stack size 0 bytes, startup_stm32f429_439xx.o(.text))
[Address Reference Count : 1]

- startup_stm32f429_439xx.o(RESET)

DMA2_Stream2_IRQHandler (Thumb, 0 bytes, Stack size 0 bytes, startup_stm32f429_439xx.o(.text))
[Address Reference Count : 1]

- startup_stm32f429_439xx.o(RESET)

DMA2_Stream3_IRQHandler (Thumb, 0 bytes, Stack size 0 bytes, startup_stm32f429_439xx.o(.text))
[Address Reference Count : 1]

- startup_stm32f429_439xx.o(RESET)

DMA2_Stream4_IRQHandler (Thumb, 0 bytes, Stack size 0 bytes, startup_stm32f429_439xx.o(.text))
[Address Reference Count : 1]

- startup_stm32f429_439xx.o(RESET)

DMA2_Stream6_IRQHandler (Thumb, 0 bytes, Stack size 0 bytes, startup_stm32f429_439xx.o(.text))
[Address Reference Count : 1]

- startup_stm32f429_439xx.o(RESET)

ETH_IRQHandler (Thumb, 0 bytes, Stack size 0 bytes, startup_stm32f429_439xx.o(.text))
[Address Reference Count : 1]

- startup_stm32f429_439xx.o(RESET)

ETH_WKUP_IRQHandler (Thumb, 0 bytes, Stack size 0 bytes, startup_stm32f429_439xx.o(.text))
[Address Reference Count : 1]

- startup_stm32f429_439xx.o(RESET)

EXTI0_IRQHandler (Thumb, 0 bytes, Stack size 0 bytes, startup_stm32f429_439xx.o(.text))
[Address Reference Count : 1]

- startup_stm32f429_439xx.o(RESET)

EXTI15_10_IRQHandler (Thumb, 0 bytes, Stack size 0 bytes, startup_stm32f429_439xx.o(.text))
[Address Reference Count : 1]

- startup_stm32f429_439xx.o(RESET)

EXTI1_IRQHandler (Thumb, 0 bytes, Stack size 0 bytes, startup_stm32f429_439xx.o(.text))
[Address Reference Count : 1]

- startup_stm32f429_439xx.o(RESET)

EXTI2_IRQHandler (Thumb, 0 bytes, Stack size 0 bytes, startup_stm32f429_439xx.o(.text))
[Address Reference Count : 1]

- startup_stm32f429_439xx.o(RESET)

EXTI3_IRQHandler (Thumb, 0 bytes, Stack size 0 bytes, startup_stm32f429_439xx.o(.text))
[Address Reference Count : 1]

- startup_stm32f429_439xx.o(RESET)

EXTI4_IRQHandler (Thumb, 0 bytes, Stack size 0 bytes, startup_stm32f429_439xx.o(.text))
[Address Reference Count : 1]

- startup_stm32f429_439xx.o(RESET)

EXTI9_5_IRQHandler (Thumb, 0 bytes, Stack size 0 bytes, startup_stm32f429_439xx.o(.text))
[Address Reference Count : 1]

- startup_stm32f429_439xx.o(RESET)

FLASH_IRQHandler (Thumb, 0 bytes, Stack size 0 bytes, startup_stm32f429_439xx.o(.text))
[Address Reference Count : 1]

- startup_stm32f429_439xx.o(RESET)

FMC_IRQHandler (Thumb, 0 bytes, Stack size 0 bytes, startup_stm32f429_439xx.o(.text))
[Address Reference Count : 1]

- startup_stm32f429_439xx.o(RESET)

FPU_IRQHandler (Thumb, 0 bytes, Stack size 0 bytes, startup_stm32f429_439xx.o(.text))
[Address Reference Count : 1]

- startup_stm32f429_439xx.o(RESET)

HASH_RNG_IRQHandler (Thumb, 0 bytes, Stack size 0 bytes, startup_stm32f429_439xx.o(.text))
[Address Reference Count : 1]

- startup_stm32f429_439xx.o(RESET)

I2C1_ER_IRQHandler (Thumb, 0 bytes, Stack size 0 bytes, startup_stm32f429_439xx.o(.text))
[Address Reference Count : 1]

- startup_stm32f429_439xx.o(RESET)

I2C1_EV_IRQHandler (Thumb, 0 bytes, Stack size 0 bytes, startup_stm32f429_439xx.o(.text))
[Address Reference Count : 1]

- startup_stm32f429_439xx.o(RESET)

I2C2_ER_IRQHandler (Thumb, 0 bytes, Stack size 0 bytes, startup_stm32f429_439xx.o(.text))
[Address Reference Count : 1]

- startup_stm32f429_439xx.o(RESET)

I2C2_EV_IRQHandler (Thumb, 0 bytes, Stack size 0 bytes, startup_stm32f429_439xx.o(.text))
[Address Reference Count : 1]

- startup_stm32f429_439xx.o(RESET)

I2C3_ER_IRQHandler (Thumb, 0 bytes, Stack size 0 bytes, startup_stm32f429_439xx.o(.text))
[Address Reference Count : 1]

- startup_stm32f429_439xx.o(RESET)

I2C3_EV_IRQHandler (Thumb, 0 bytes, Stack size 0 bytes, startup_stm32f429_439xx.o(.text))
[Address Reference Count : 1]

- startup_stm32f429_439xx.o(RESET)

LTDC_ER_IRQHandler (Thumb, 0 bytes, Stack size 0 bytes, startup_stm32f429_439xx.o(.text))
[Address Reference Count : 1]

- startup_stm32f429_439xx.o(RESET)

LTDC_IRQHandler (Thumb, 0 bytes, Stack size 0 bytes, startup_stm32f429_439xx.o(.text))
[Address Reference Count : 1]

- startup_stm32f429_439xx.o(RESET)

OTG_FS_IRQHandler (Thumb, 0 bytes, Stack size 0 bytes, startup_stm32f429_439xx.o(.text))
[Address Reference Count : 1]

- startup_stm32f429_439xx.o(RESET)

OTG_FS_WKUP_IRQHandler (Thumb, 0 bytes, Stack size 0 bytes, startup_stm32f429_439xx.o(.text))
[Address Reference Count : 1]

- startup_stm32f429_439xx.o(RESET)

OTG_HS_EP1_IN_IRQHandler (Thumb, 0 bytes, Stack size 0 bytes, startup_stm32f429_439xx.o(.text))
[Address Reference Count : 1]

- startup_stm32f429_439xx.o(RESET)

OTG_HS_EP1_OUT_IRQHandler (Thumb, 0 bytes, Stack size 0 bytes, startup_stm32f429_439xx.o(.text))
[Address Reference Count : 1]

- startup_stm32f429_439xx.o(RESET)

OTG_HS_IRQHandler (Thumb, 0 bytes, Stack size 0 bytes, startup_stm32f429_439xx.o(.text))
[Address Reference Count : 1]

- startup_stm32f429_439xx.o(RESET)

OTG_HS_WKUP_IRQHandler (Thumb, 0 bytes, Stack size 0 bytes, startup_stm32f429_439xx.o(.text))
[Address Reference Count : 1]

- startup_stm32f429_439xx.o(RESET)

PVD_IRQHandler (Thumb, 0 bytes, Stack size 0 bytes, startup_stm32f429_439xx.o(.text))
[Address Reference Count : 1]

- startup_stm32f429_439xx.o(RESET)

RCC_IRQHandler (Thumb, 0 bytes, Stack size 0 bytes, startup_stm32f429_439xx.o(.text))
[Address Reference Count : 1]

- startup_stm32f429_439xx.o(RESET)

RTC_Alarm_IRQHandler (Thumb, 0 bytes, Stack size 0 bytes, startup_stm32f429_439xx.o(.text))
[Address Reference Count : 1]

- startup_stm32f429_439xx.o(RESET)

RTC_WKUP_IRQHandler (Thumb, 0 bytes, Stack size 0 bytes, startup_stm32f429_439xx.o(.text))
[Address Reference Count : 1]

- startup_stm32f429_439xx.o(RESET)

SAI1_IRQHandler (Thumb, 0 bytes, Stack size 0 bytes, startup_stm32f429_439xx.o(.text))
[Address Reference Count : 1]

- startup_stm32f429_439xx.o(RESET)

SDIO_IRQHandler (Thumb, 0 bytes, Stack size 0 bytes, startup_stm32f429_439xx.o(.text))
[Address Reference Count : 1]

- startup_stm32f429_439xx.o(RESET)

SPI1_IRQHandler (Thumb, 0 bytes, Stack size 0 bytes, startup_stm32f429_439xx.o(.text))
[Address Reference Count : 1]

- startup_stm32f429_439xx.o(RESET)

SPI2_IRQHandler (Thumb, 0 bytes, Stack size 0 bytes, startup_stm32f429_439xx.o(.text))
[Address Reference Count : 1]

- startup_stm32f429_439xx.o(RESET)

SPI3_IRQHandler (Thumb, 0 bytes, Stack size 0 bytes, startup_stm32f429_439xx.o(.text))
[Address Reference Count : 1]

- startup_stm32f429_439xx.o(RESET)

SPI4_IRQHandler (Thumb, 0 bytes, Stack size 0 bytes, startup_stm32f429_439xx.o(.text))
[Address Reference Count : 1]

- startup_stm32f429_439xx.o(RESET)

SPI5_IRQHandler (Thumb, 0 bytes, Stack size 0 bytes, startup_stm32f429_439xx.o(.text))
[Address Reference Count : 1]

- startup_stm32f429_439xx.o(RESET)

SPI6_IRQHandler (Thumb, 0 bytes, Stack size 0 bytes, startup_stm32f429_439xx.o(.text))
[Address Reference Count : 1]

- startup_stm32f429_439xx.o(RESET)

TAMP_STAMP_IRQHandler (Thumb, 0 bytes, Stack size 0 bytes, startup_stm32f429_439xx.o(.text))
[Address Reference Count : 1]

- startup_stm32f429_439xx.o(RESET)

TIM1_BRK_TIM9_IRQHandler (Thumb, 0 bytes, Stack size 0 bytes, startup_stm32f429_439xx.o(.text))
[Address Reference Count : 1]

- startup_stm32f429_439xx.o(RESET)

TIM1_CC_IRQHandler (Thumb, 0 bytes, Stack size 0 bytes, startup_stm32f429_439xx.o(.text))
[Address Reference Count : 1]

- startup_stm32f429_439xx.o(RESET)

TIM1_TRG_COM_TIM11_IRQHandler (Thumb, 0 bytes, Stack size 0 bytes, startup_stm32f429_439xx.o(.text))
[Address Reference Count : 1]

- startup_stm32f429_439xx.o(RESET)

TIM1_UP_TIM10_IRQHandler (Thumb, 0 bytes, Stack size 0 bytes, startup_stm32f429_439xx.o(.text))
[Address Reference Count : 1]

- startup_stm32f429_439xx.o(RESET)

TIM3_IRQHandler (Thumb, 0 bytes, Stack size 0 bytes, startup_stm32f429_439xx.o(.text))
[Address Reference Count : 1]

- startup_stm32f429_439xx.o(RESET)

TIM4_IRQHandler (Thumb, 0 bytes, Stack size 0 bytes, startup_stm32f429_439xx.o(.text))
[Address Reference Count : 1]

- startup_stm32f429_439xx.o(RESET)

TIM5_IRQHandler (Thumb, 0 bytes, Stack size 0 bytes, startup_stm32f429_439xx.o(.text))
[Address Reference Count : 1]

- startup_stm32f429_439xx.o(RESET)
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

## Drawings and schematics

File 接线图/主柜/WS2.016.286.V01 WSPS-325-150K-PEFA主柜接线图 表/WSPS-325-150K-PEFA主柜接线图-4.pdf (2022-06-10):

## INTERLOCK

## PPS IN1

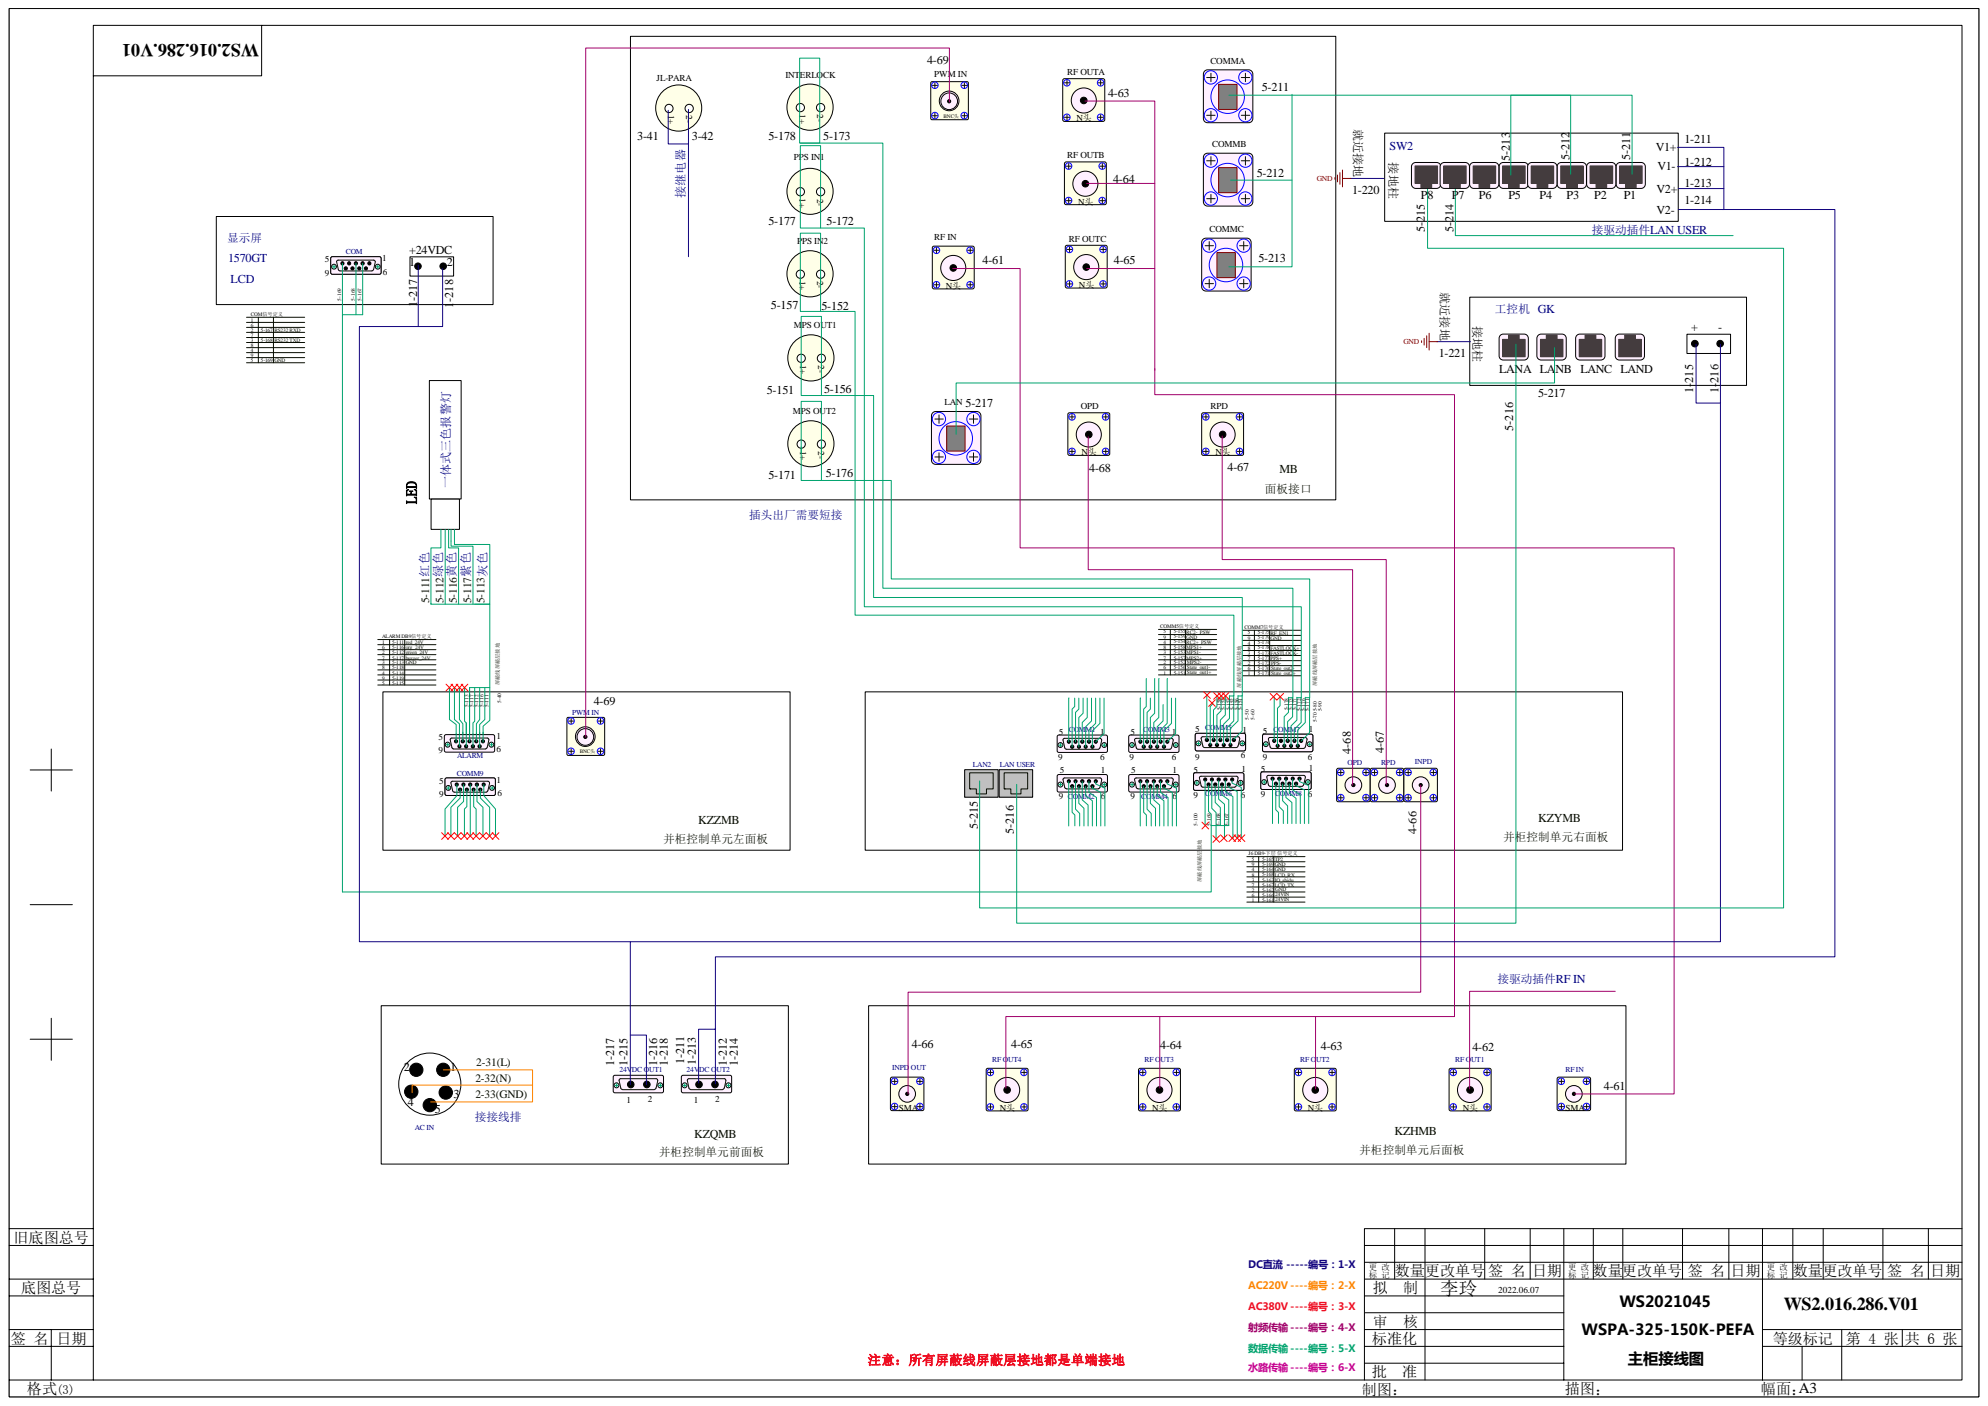
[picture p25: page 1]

LANA LANB LANC LAND

J6 DB9-下层 信号定义 9 5 | 5-169 5-165 5-164 | GND TP2

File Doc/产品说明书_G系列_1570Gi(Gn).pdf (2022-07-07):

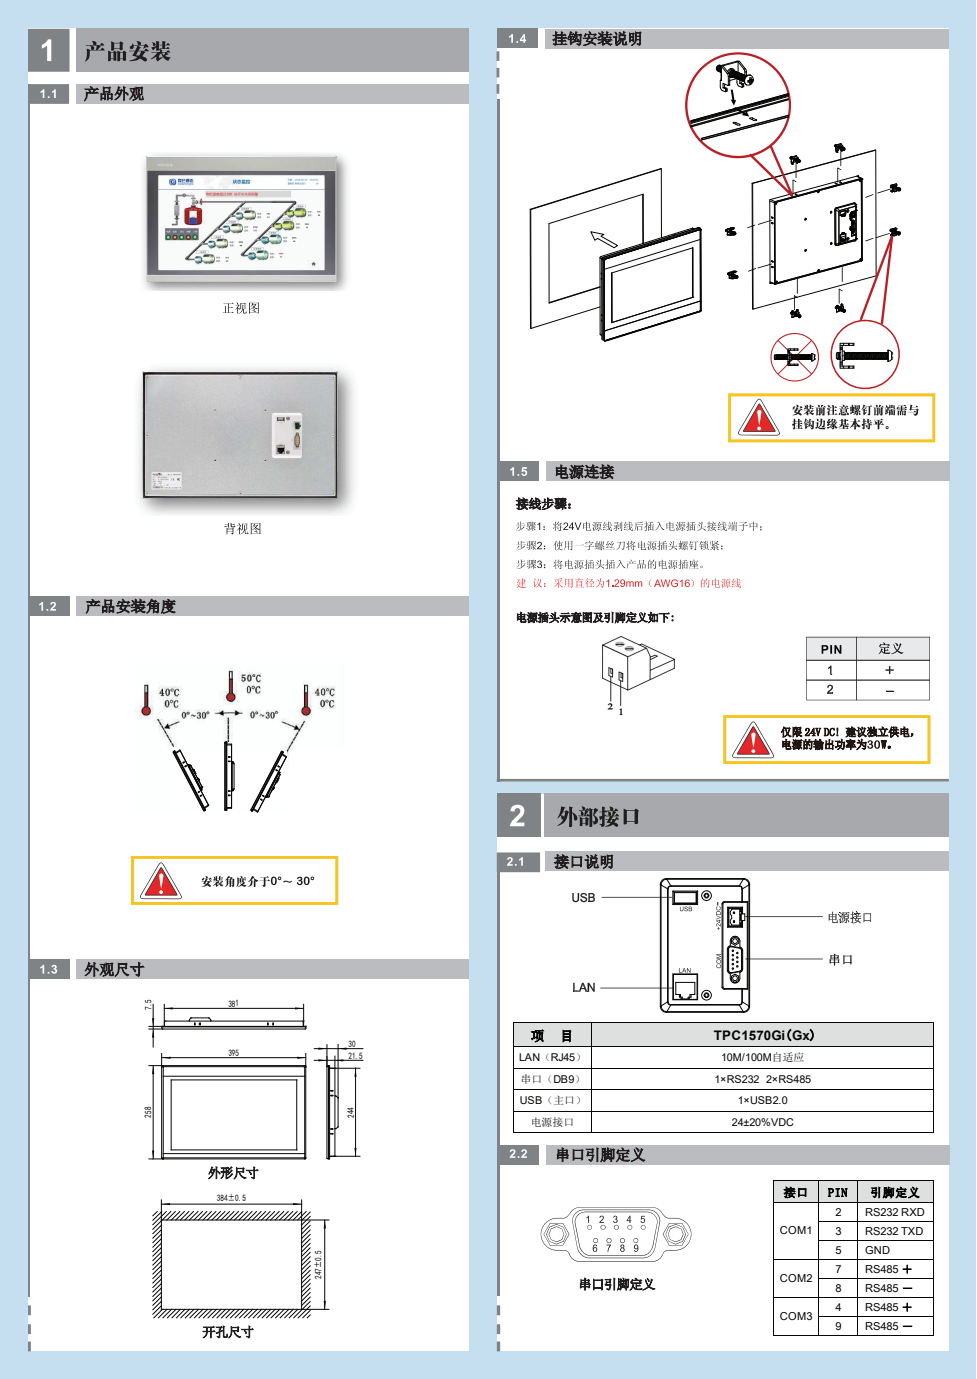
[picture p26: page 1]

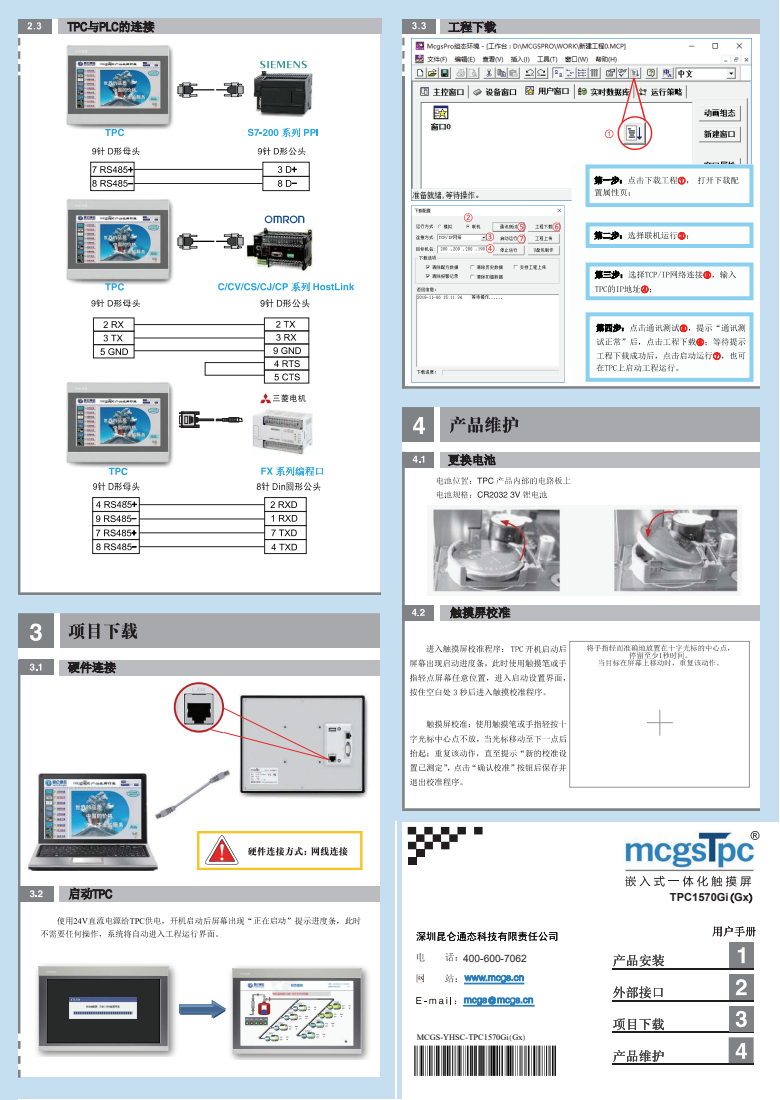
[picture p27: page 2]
TPC1570Gi(Gx); MCGS-YHSC-; TPC1570Gi

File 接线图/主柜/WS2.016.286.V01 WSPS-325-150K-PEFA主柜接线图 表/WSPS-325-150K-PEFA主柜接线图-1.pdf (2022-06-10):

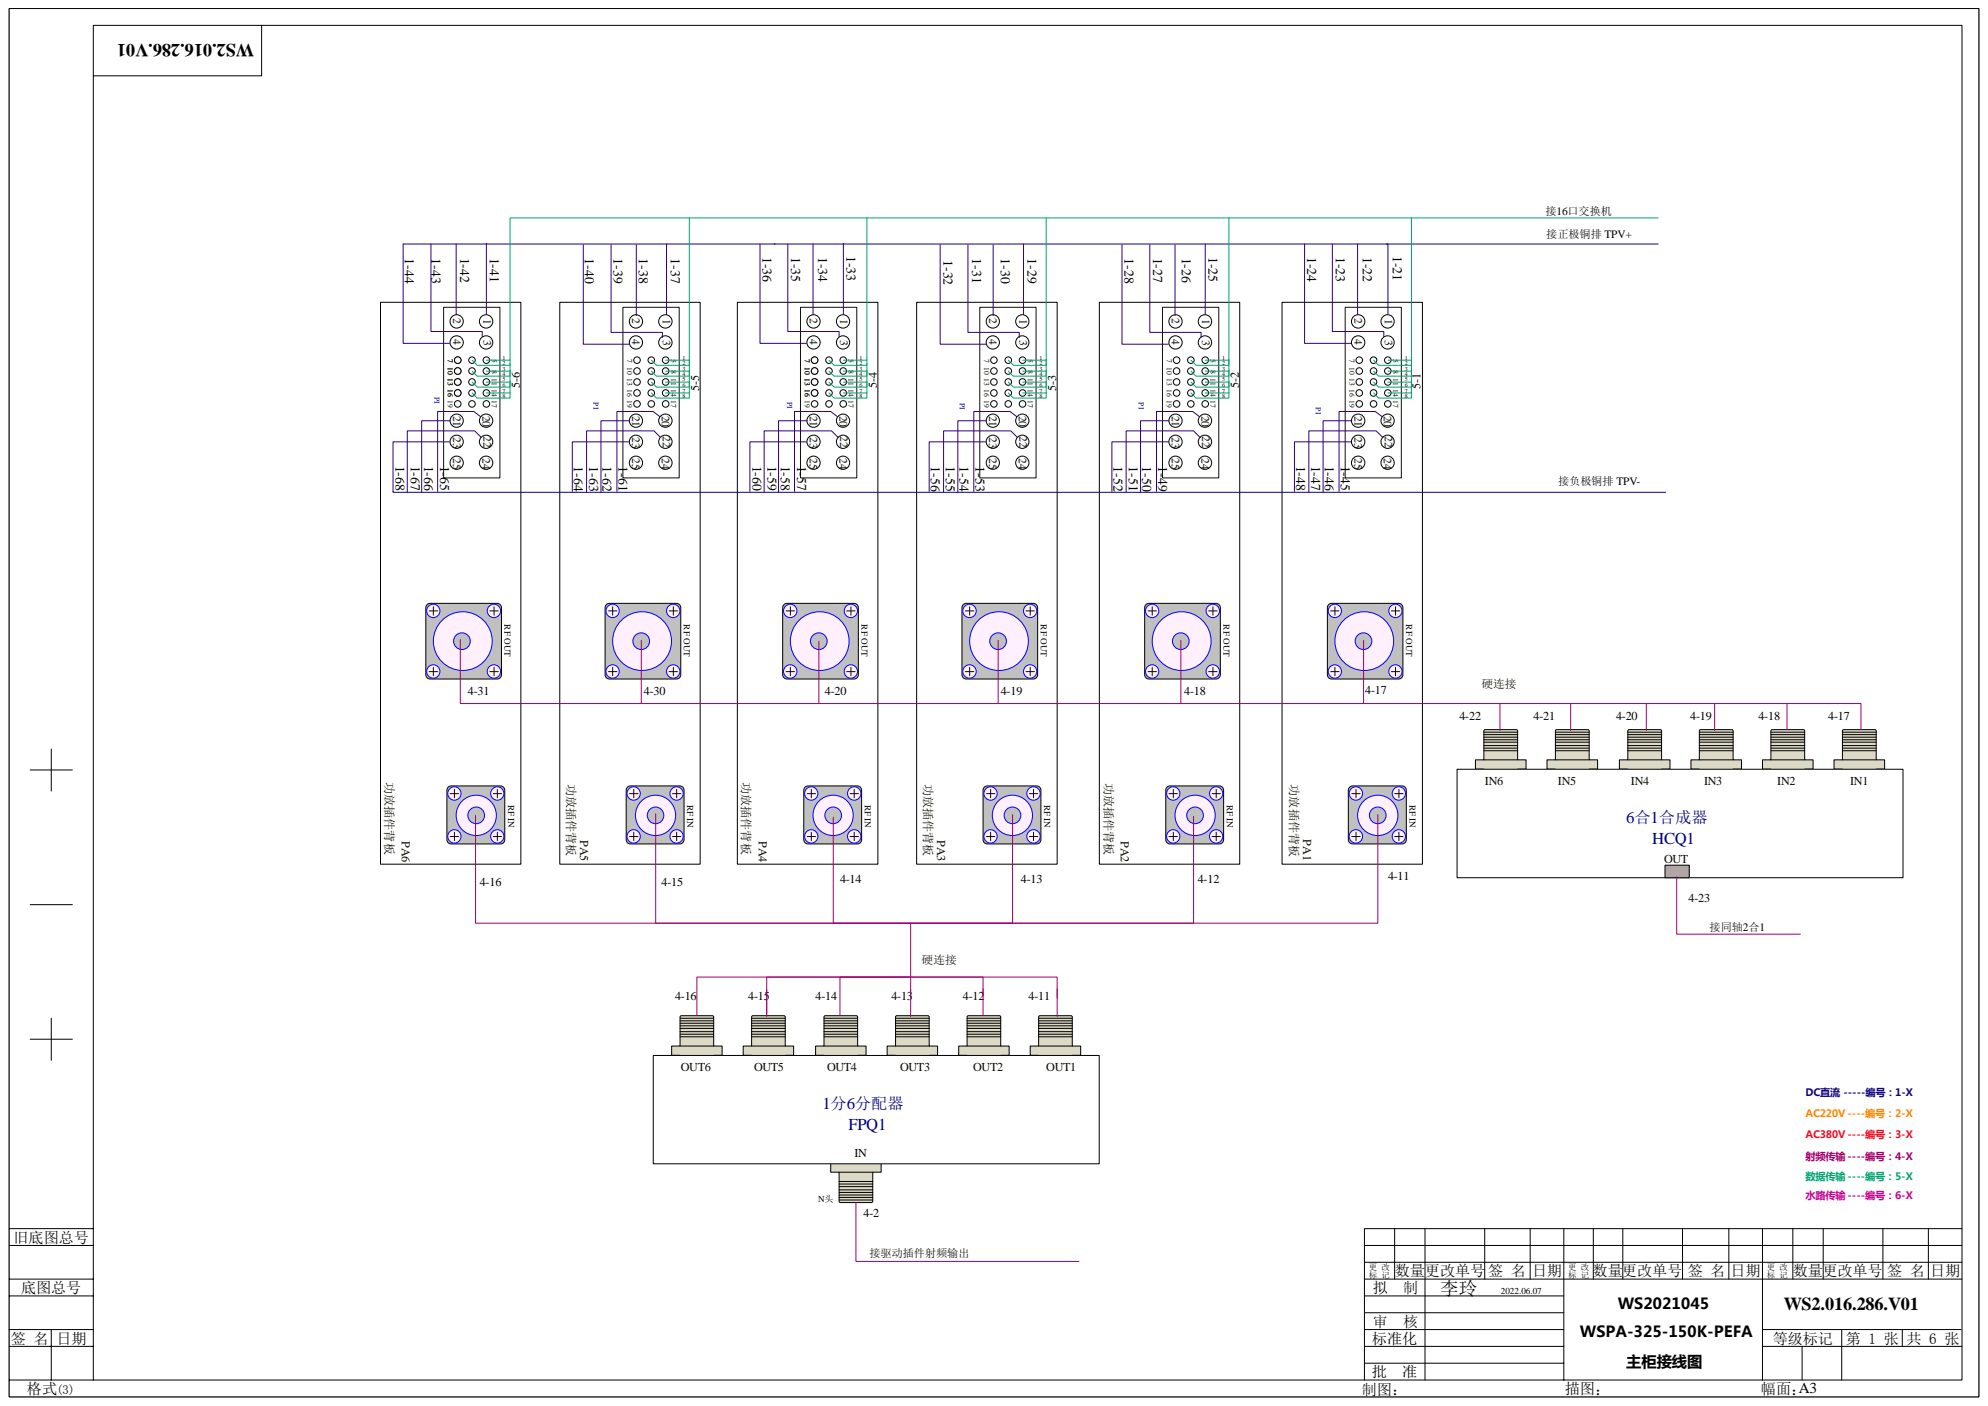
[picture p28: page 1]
旧底图总号; 底图总号; 数量更改单号; 更改单号; 更改单号 签 名; 标准化; 等级标记; 主柜接线图; DC直流; 数据传输; 射频传输; 水路传输 ----编号：6-X; WS2021045 WSPA-325-150K-PEFA; 功放插件背板; 1分6分配器 FPQ1; OUT6; OUT5; OUT4; OUT3; OUT2; OUT1; 6合1合成器 HCQ1; OUT; 硬连接; 接同轴2合1; 接驱动插件射频输出; 接正极铜排 TPV+; 接负极铜排 TPV-; 接16口交换机

RF OUT RF IN

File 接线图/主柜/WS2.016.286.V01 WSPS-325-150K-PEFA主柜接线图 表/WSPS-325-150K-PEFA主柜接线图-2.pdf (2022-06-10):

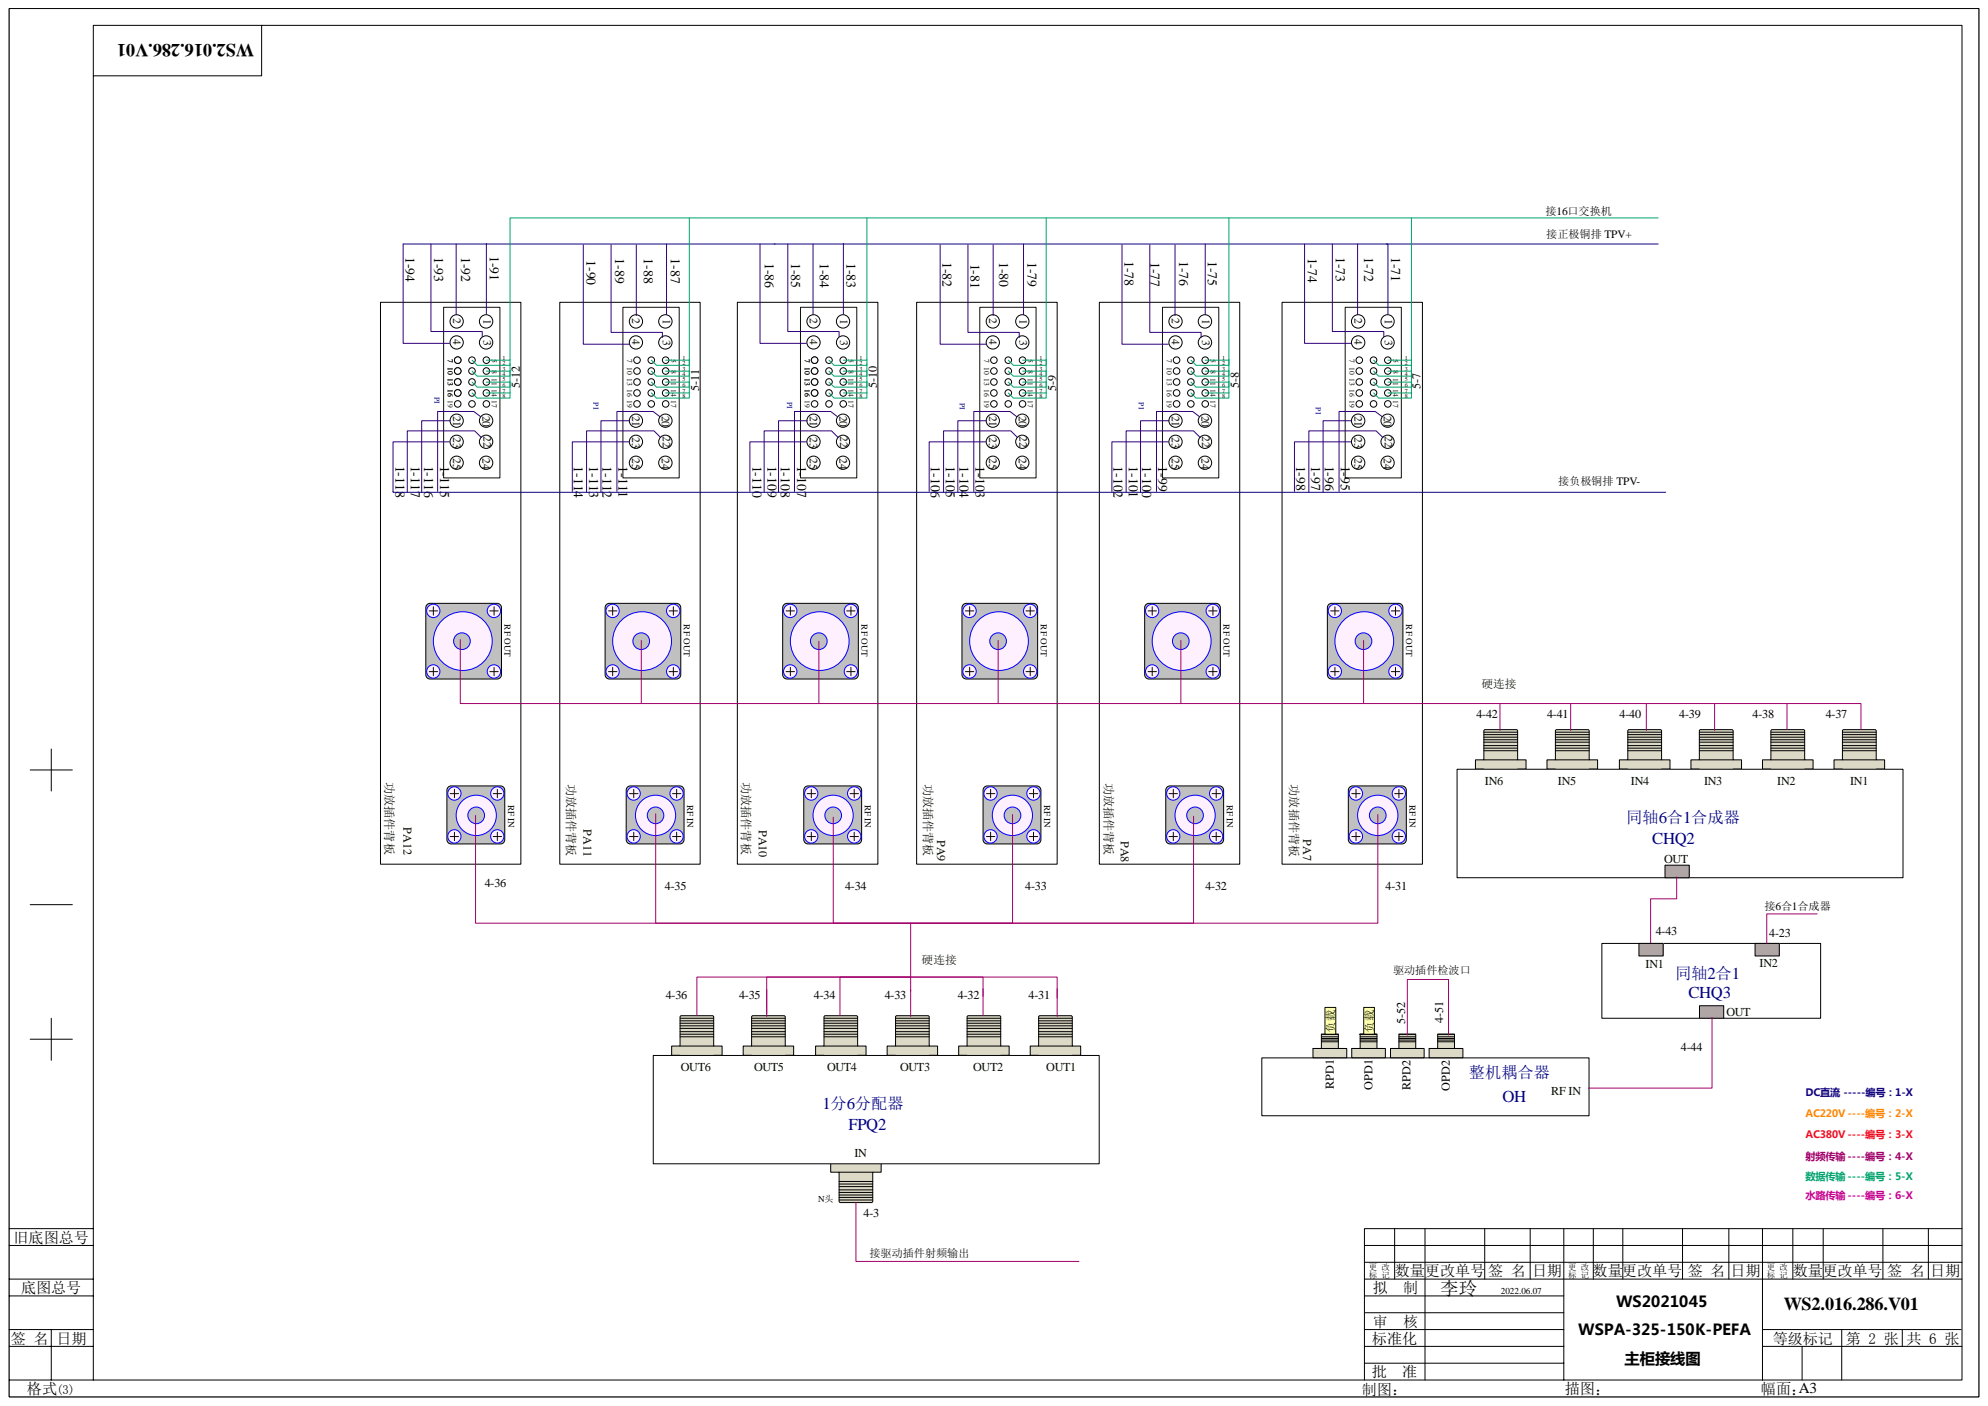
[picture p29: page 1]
旧底图总号; 底图总号; 数量更改单号; 更改单号; 更改单号 签 名; 标准化; 等级标记; DC直流; 数据传输; 射频传输; 水路传输 ----编号：6-X; 功放插件背板; 1分6分配器 FPQ2; OUT6; OUT5; OUT4; OUT3; OUT2; OUT1; 同轴6合1合成器 CHQ2; OUT; 硬连接; 接6合1合成器; 接驱动插件射频输出; 接正极铜排 TPV+; 接负极铜排 TPV-; 接16口交换机; 同轴2合1 CHQ3; 整机耦合器; OH RPD¹ OPD1; RPD2; OPD2; 驱动插件检波口; 主柜接线图; WS2021045 WSPA-325-150K-PEFA

RF OUT RF IN

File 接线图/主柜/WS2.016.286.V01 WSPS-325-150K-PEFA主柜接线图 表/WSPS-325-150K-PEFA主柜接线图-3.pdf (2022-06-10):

P8 | P7 | P6 P5
P12 P11 P10 P9 | V2+

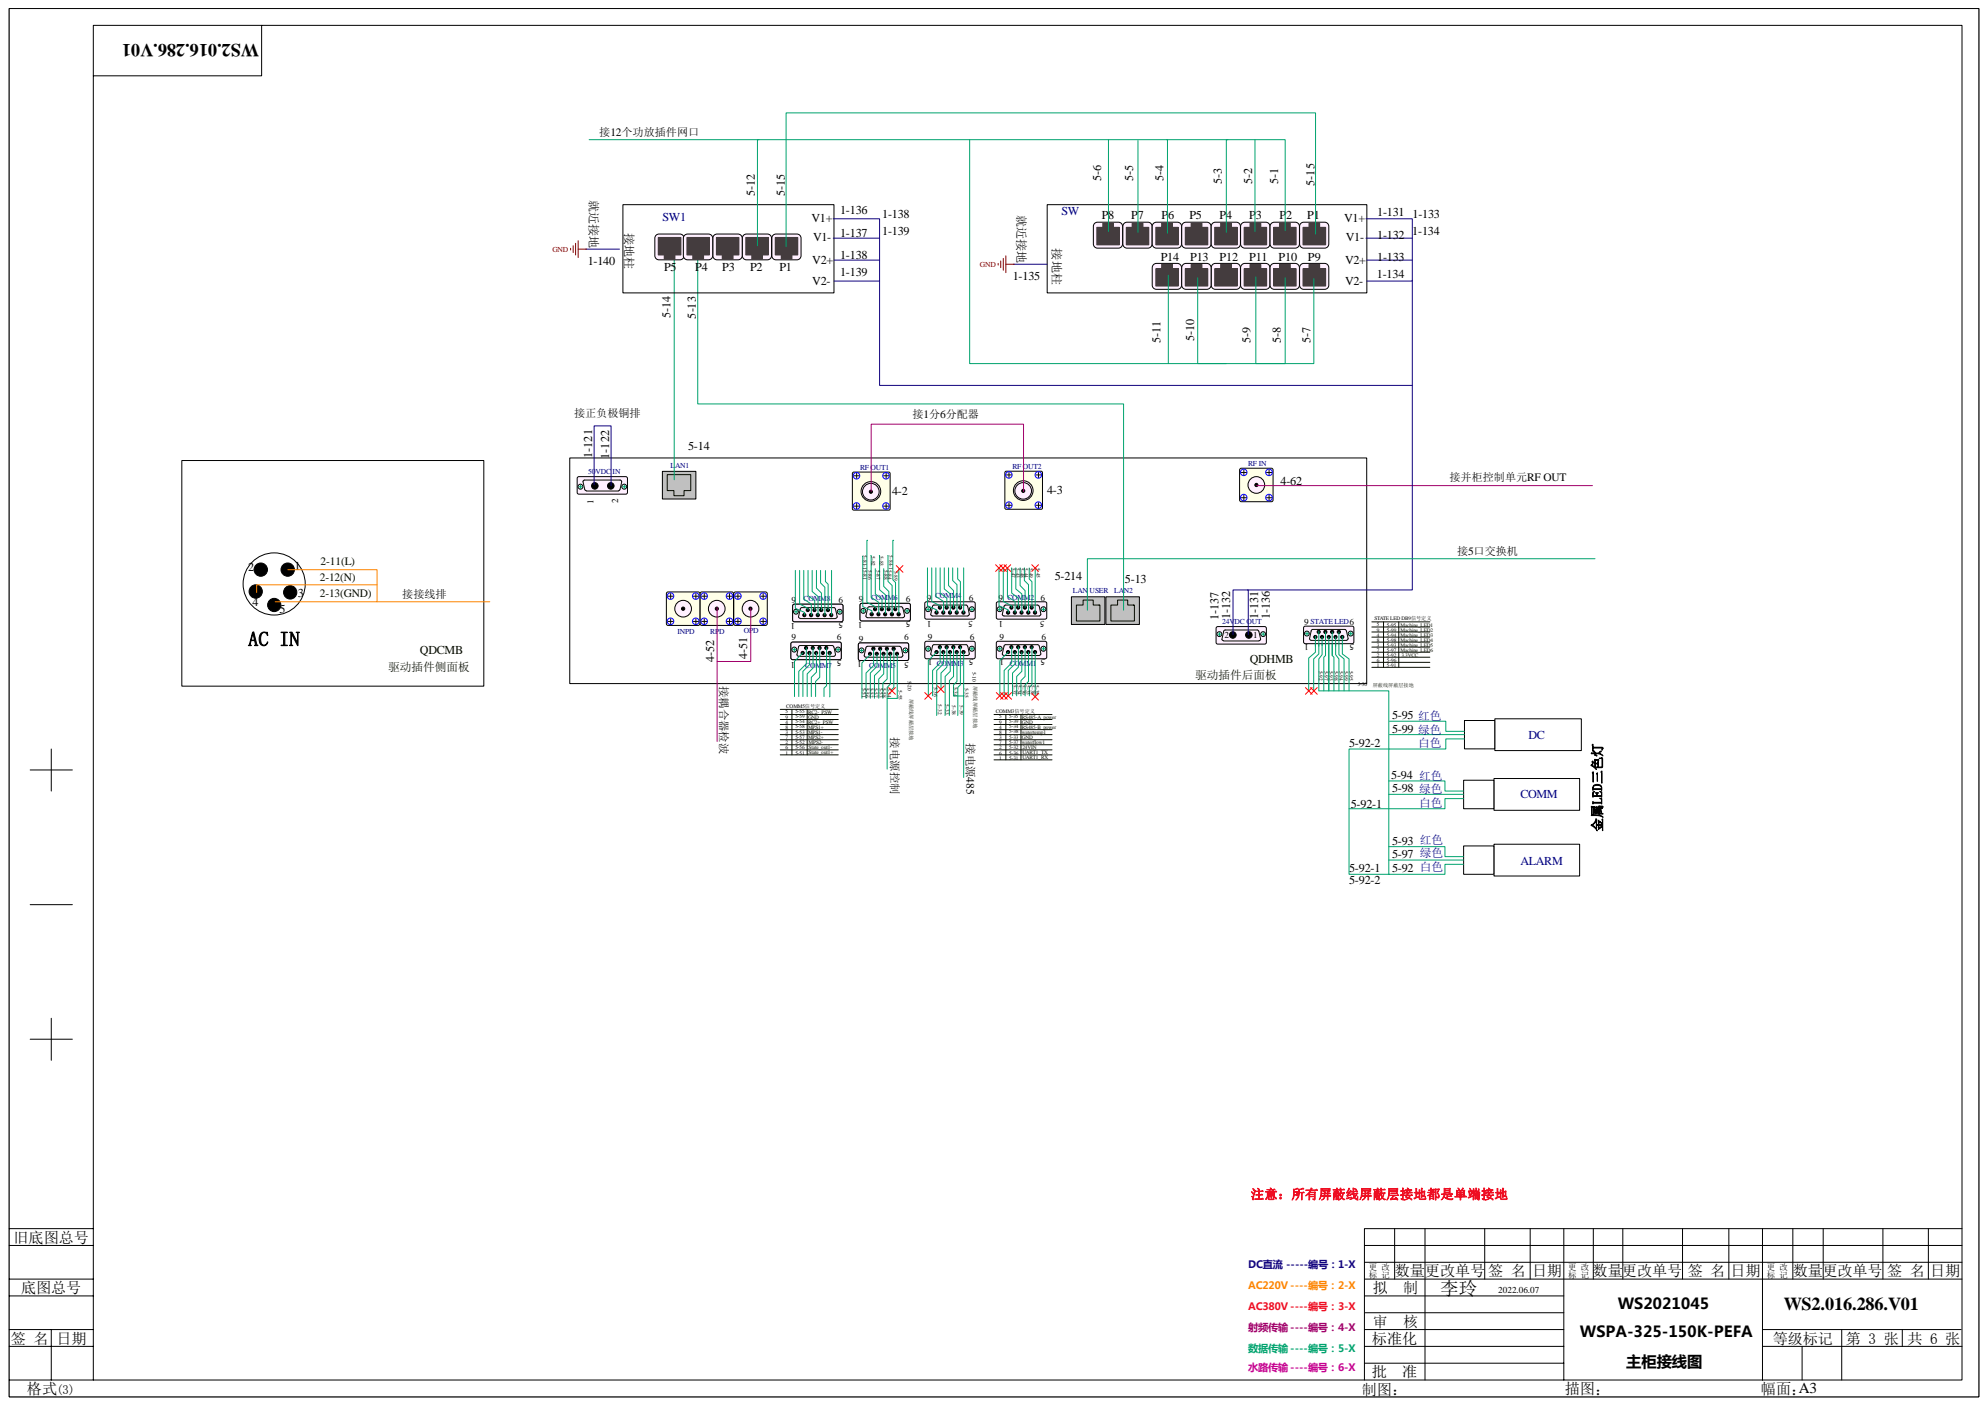
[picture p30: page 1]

5 | 5-95 | Machine_LED1

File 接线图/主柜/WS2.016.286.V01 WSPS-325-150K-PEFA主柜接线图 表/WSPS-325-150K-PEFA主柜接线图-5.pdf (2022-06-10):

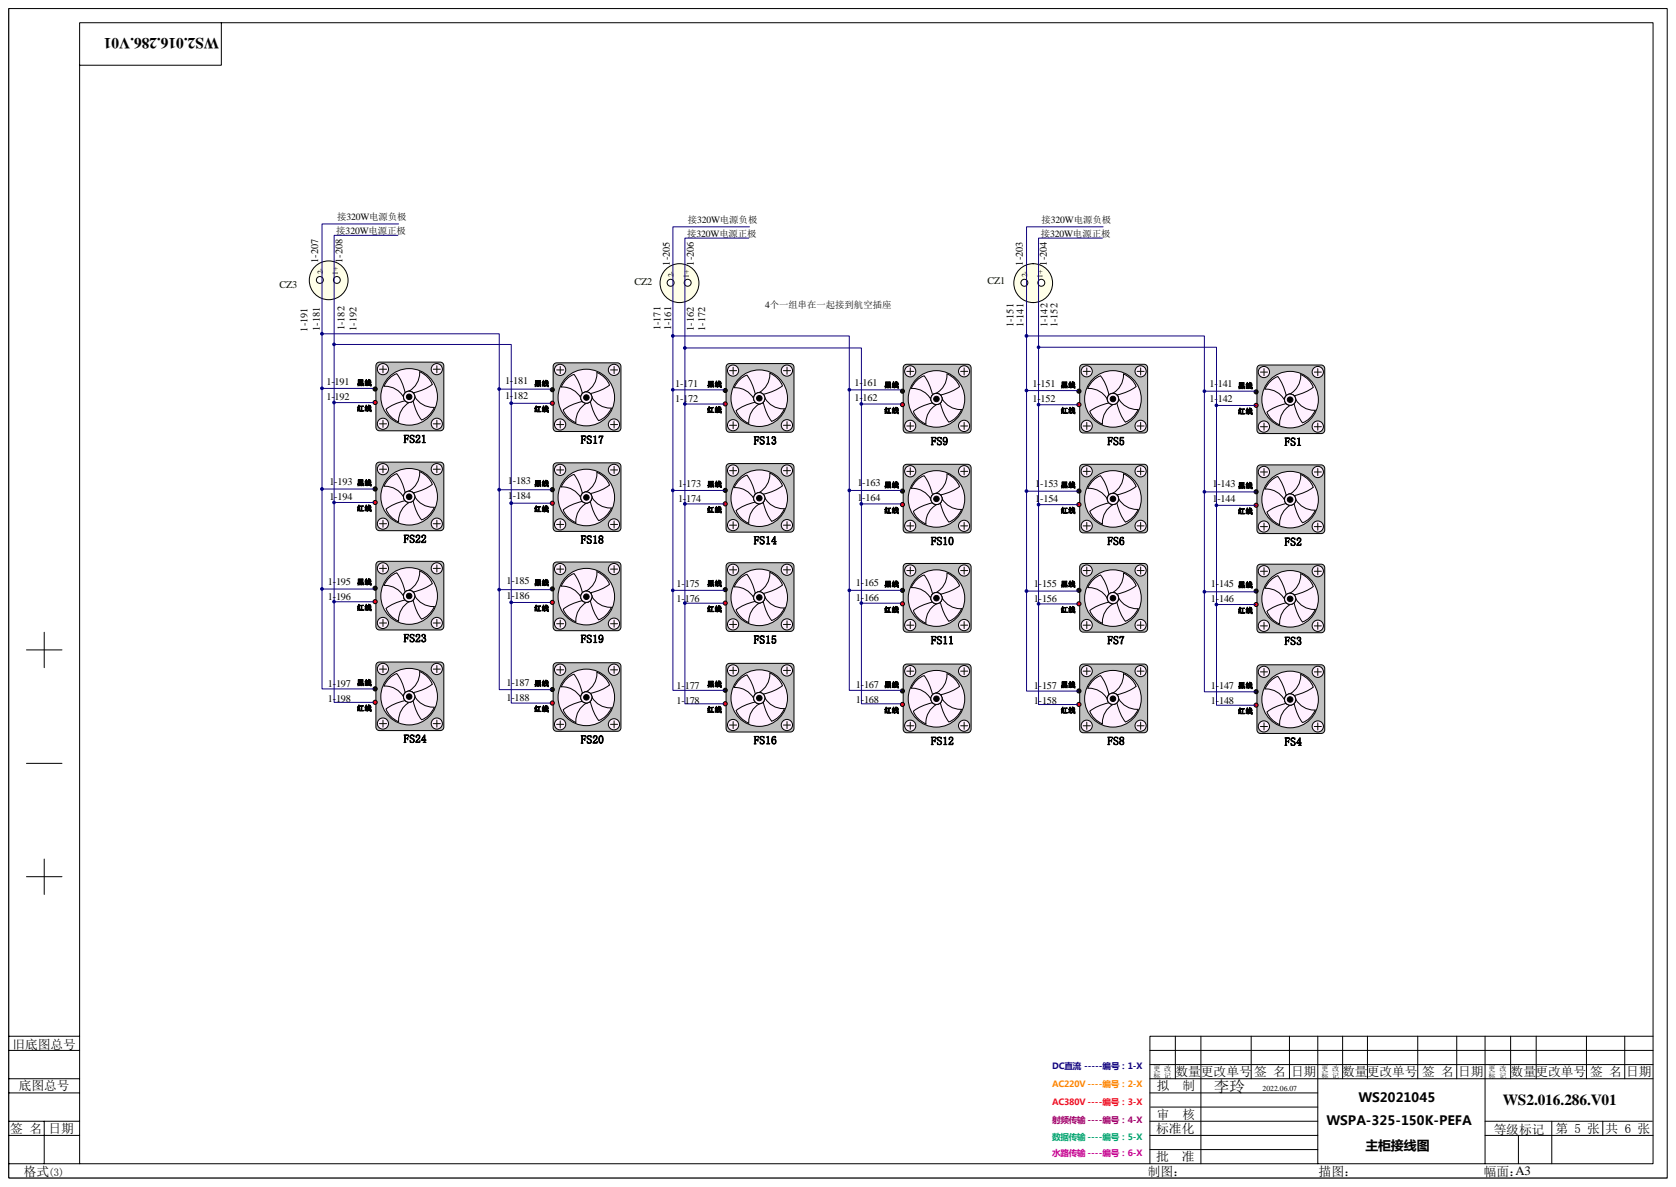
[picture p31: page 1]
旧底图总号; 底图总号; 数量更改单号; 更改单号; 更改单号 签 名; 标准化; 等级标记; DC直流; 数据传输; 射频传输; 水路传输 ----编号：6-X; 接320W电源负极; 接320W电源正极; 4个一组串在一起接到航空插座; 接320W电源负极 接320W电源正极; 主柜接线图; WSPA-325-150K-PEFA

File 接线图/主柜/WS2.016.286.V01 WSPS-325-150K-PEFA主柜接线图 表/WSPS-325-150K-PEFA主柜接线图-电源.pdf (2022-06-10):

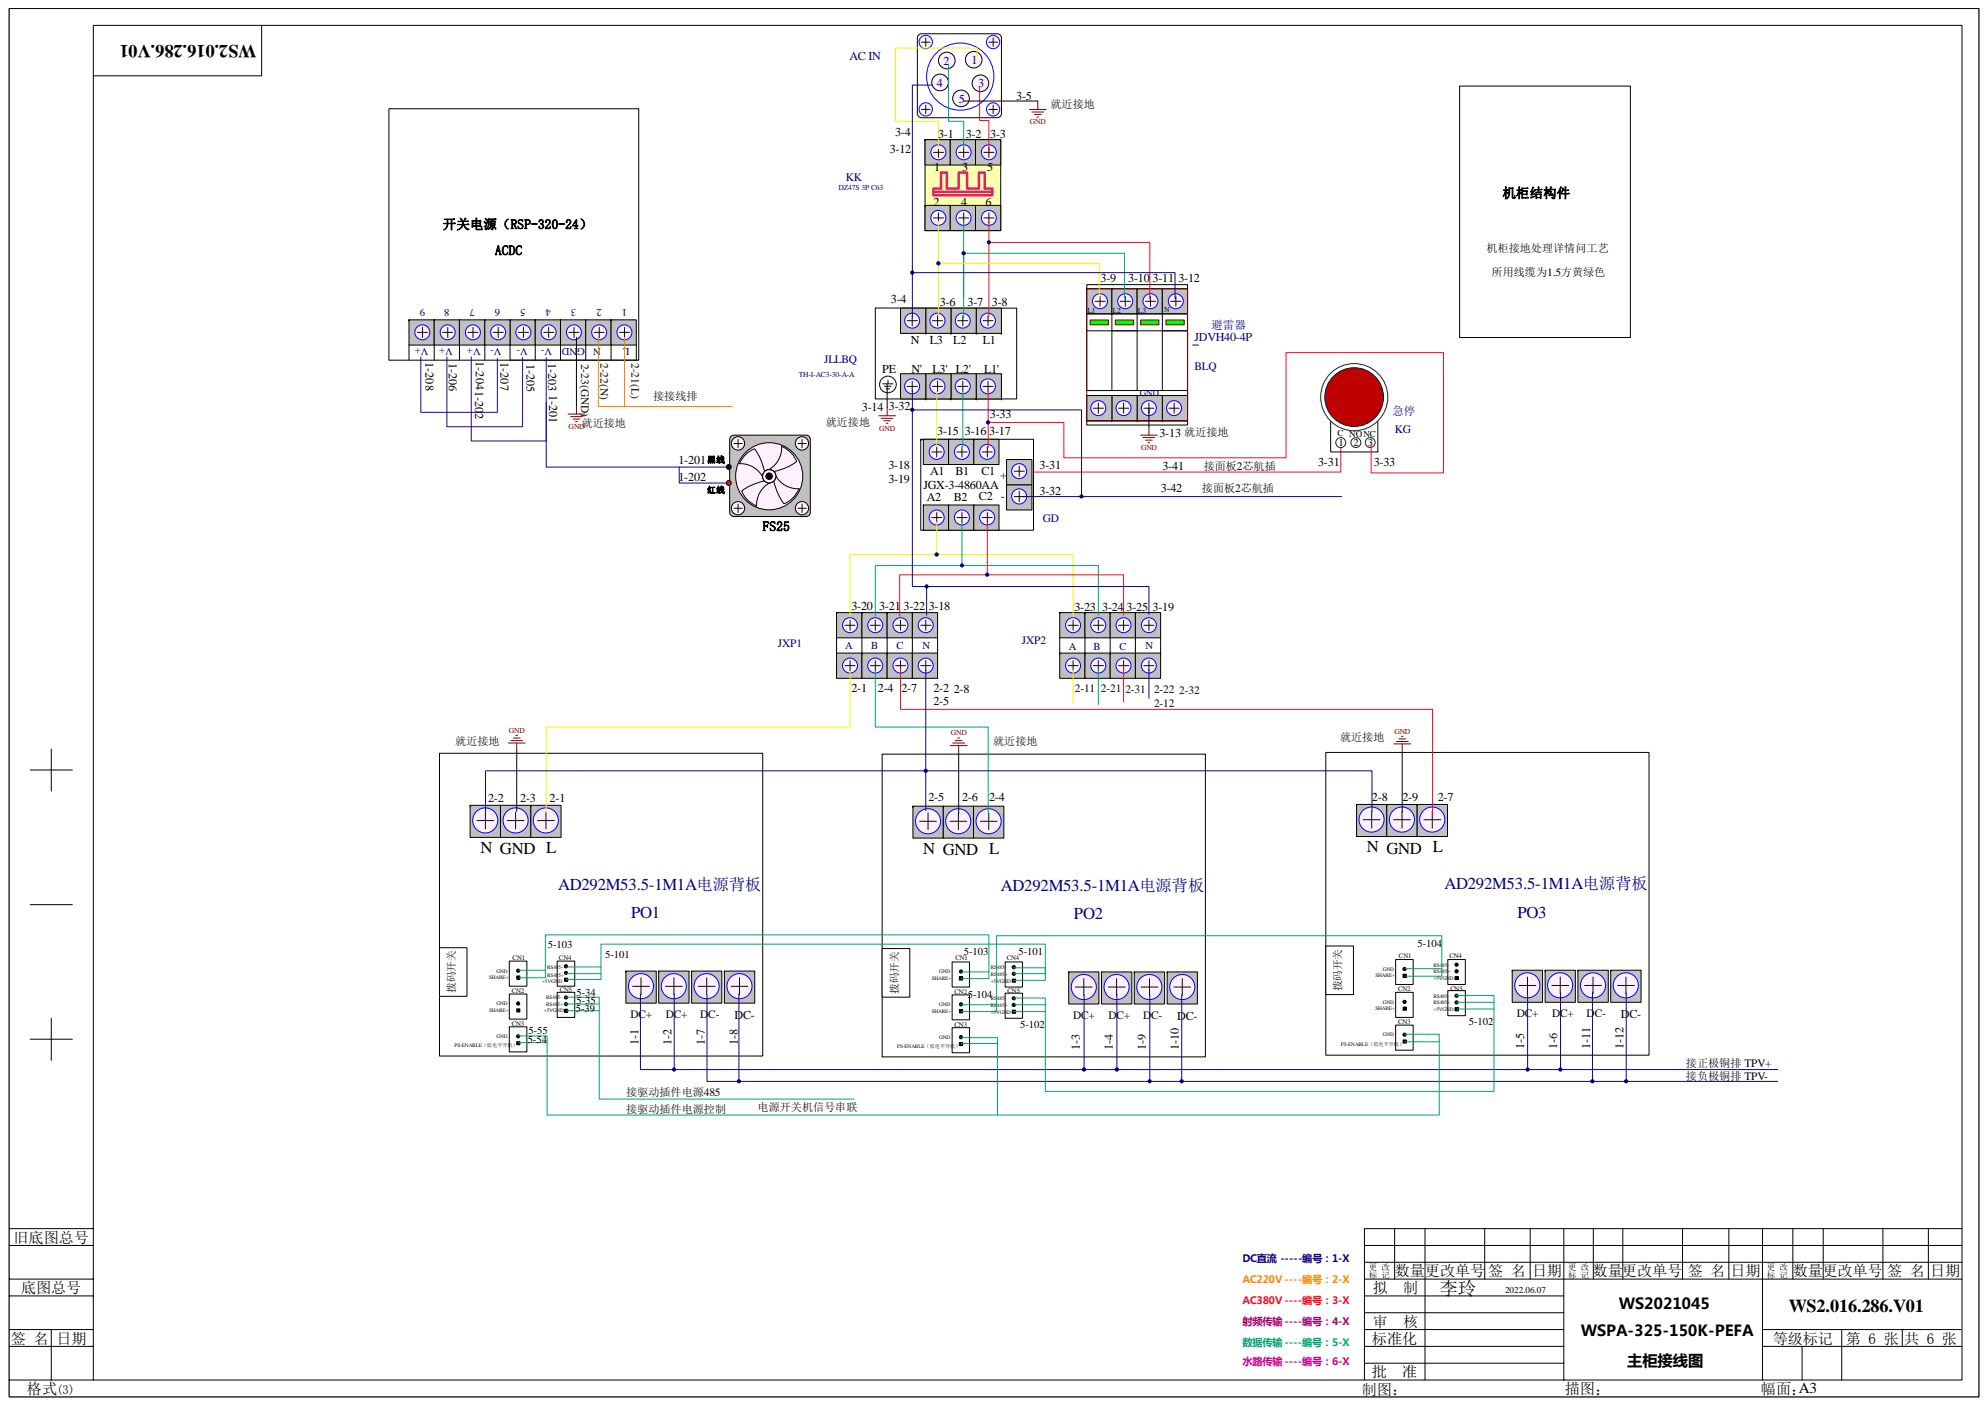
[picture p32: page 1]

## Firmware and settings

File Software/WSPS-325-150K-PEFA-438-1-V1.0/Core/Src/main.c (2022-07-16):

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
/* Includes ------------------------------------------------------------------*/
#include "main.h"
#include "dma.h"
#include "spi.h"
#include "usart.h"
#include "gpio.h"

/* USER CODE BEGIN Includes */

#include "../../App/task.h"
#include "../../App/tcp.h"
#include "../../App/udp.h"
#include "../../App/dc_rs485.h"
/* USER CODE END Includes */


void SystemClock_Config(void);
/**
  * @brief  The application entry point.
  * @retval int
  */
int main(void)
{
  /* MCU Configuration--------------------------------------------------------*/

  /* Reset of all peripherals, Initializes the Flash interface and the Systick. */
  HAL_Init();

  /* Configure the system clock */
  SystemClock_Config();

  /* Initialize all configured peripherals */
  MX_GPIO_Init();
  MX_SPI2_Init();
  MX_SPI4_Init();
  MX_DMA_Init();
  MX_USART3_UART_Init();
  /* USER CODE BEGIN 2 */
  Device_Init();
  /* USER CODE END 2 */

  /* Infinite loop */
  /* USER CODE BEGIN WHILE */
  while (1)
  {
    /* USER CODE END WHILE */

    /* USER CODE BEGIN 3 */
      Task_TCP_TOP();       /*UDP中间层对上层通信*/
      Task_UDP();       /*UDP中间层对底层通信*/
      Task_Write_Modbus();
      Task_Control();
      Task_DC_Read_Data();
      Task_Ads8411_Send_Data();
      Task_Get_Temp();
  }
  /* USER CODE END 3 */
}

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


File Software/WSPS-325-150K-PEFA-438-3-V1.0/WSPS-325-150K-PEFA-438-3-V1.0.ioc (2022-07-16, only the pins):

Mcu.UserName=STM32H743ZITx
PA0.Signal=ADC1_INP16
PA1.Signal=ADC1_INP17
PA2.Signal=USART2_TX
PA3.Signal=USART2_RX
PA4.Signal=COMP_DAC11_group
PA7.Signal=ADCx_INP7
PB10.GPIO_Label=W5500_RST2
PB10.Signal=GPIO_Output
PB11.GPIO_Label=W5500_INIT2
PB11.Signal=GPIO_Output
PB12.GPIO_Label=SPI2_NSS
PB12.Signal=GPIO_Output
PB13.Signal=SPI2_SCK
PB14.Signal=SPI2_MISO
PB15.Signal=SPI2_MOSI
PB8.GPIO_Label=S_CLK
PB8.Signal=GPIO_Input
PD1.GPIO_Label=PPS
PD1.Signal=GPIO_Input
PD10.GPIO_Label=LINKLED2
PD10.Signal=GPIO_Output
PD12.Signal=S_TIM4_CH1
PD13.Signal=S_TIM4_CH2
PD2.GPIO_Label=MPS1
PD2.Signal=GPIO_Input
PD3.GPIO_Label=MPS2
PD3.Signal=GPIO_Input
PD4.GPIO_Label=PA
PD4.Signal=GPIO_Output
PD7.GPIO_Label=FASTLOCK
PD7.Signal=GPIO_Output
PE11.GPIO_Label=SPI4_NSS
PE11.Signal=GPIO_Output
PE12.Signal=SPI4_SCK
PE13.Signal=SPI4_MISO
PE14.Signal=SPI4_MOSI
PE15.GPIO_Label=LINKLED1
PE15.Signal=GPIO_Output
PE6.GPIO_Label=RESET
PE6.Signal=GPIO_Input
PE8.GPIO_Label=W5500_RST1
PE8.Signal=GPIO_Output
PE9.GPIO_Label=W5500_INIT1
PE9.Signal=GPIO_Output
PF0.GPIO_Label=green_ctrl
PF0.Signal=GPIO_Output
PF1.GPIO_Label=org_ctrl
PF1.Signal=GPIO_Output
PF10.Signal=ADC3_INP6
PF2.GPIO_Label=red_ctrl
PF2.Signal=GPIO_Output
PF7.Signal=SPI5_SCK
PF8.Signal=SPI5_MISO
PF9.Signal=SPI5_MOSI
PG0.GPIO_Label=P_D0
PG0.Signal=GPIO_Input
PG1.GPIO_Label=P_D1
PG1.Signal=GPIO_Input
PG10.GPIO_Label=P_D10
PG10.Signal=GPIO_Input
PG11.GPIO_Label=P_D11
PG11.Signal=GPIO_Input
PG12.GPIO_Label=P_D12
PG12.Signal=GPIO_Input
PG13.GPIO_Label=P_D13
PG13.Signal=GPIO_Input
PG14.GPIO_Label=P_D14
PG14.Signal=GPIO_Input
PG15.GPIO_Label=P_D15
PG15.Signal=GPIO_Input
PG2.GPIO_Label=P_D2
PG2.Signal=GPIO_Input
PG3.GPIO_Label=P_D3
PG3.Signal=GPIO_Input
PG4.GPIO_Label=P_D4
PG4.Signal=GPIO_Input
PG5.GPIO_Label=P_D5
PG5.Signal=GPIO_Input
PG6.GPIO_Label=P_D6
PG6.Signal=GPIO_Input
PG7.GPIO_Label=P_D7
PG7.Signal=GPIO_Input
PG8.GPIO_Label=P_D8
PG8.Signal=GPIO_Input
PG9.GPIO_Label=P_D9
PG9.Signal=GPIO_Input

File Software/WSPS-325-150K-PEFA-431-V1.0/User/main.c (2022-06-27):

#include "system.h"


int main(void)
{
    systick_init(72); /*初始化Systick工作时钟*/

    PPT_SW_init();
    LED_Init();
    ADC1_Init(); /* ADC配置 */
    DS18B20_Init();
    Addr_Init();
    
    w5500_init();                    /*初始化通信，包含插件地址*/
    socket_buf_init(txsize, rxsize); /*初始化8个Socket的发送接收缓存大小*/

    while(1) 
    {
        POWER_calculate();
        do_udp();           /*UDP 数据回环测试*/
        Get_Temp();
    }
}

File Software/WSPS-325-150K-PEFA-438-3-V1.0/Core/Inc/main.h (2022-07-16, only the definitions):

#define RESET_Pin GPIO_PIN_6
#define RESET_GPIO_Port GPIOE
#define buzzer_ctrl_Pin GPIO_PIN_15
#define buzzer_ctrl_GPIO_Port GPIOC
#define green_ctrl_Pin GPIO_PIN_0
#define green_ctrl_GPIO_Port GPIOF
#define org_ctrl_Pin GPIO_PIN_1
#define org_ctrl_GPIO_Port GPIOF
#define red_ctrl_Pin GPIO_PIN_2
#define red_ctrl_GPIO_Port GPIOF
#define P_D0_Pin GPIO_PIN_0
#define P_D0_GPIO_Port GPIOG
#define P_D1_Pin GPIO_PIN_1
#define P_D1_GPIO_Port GPIOG
#define W5500_RST1_Pin GPIO_PIN_8
#define W5500_RST1_GPIO_Port GPIOE
#define W5500_INIT1_Pin GPIO_PIN_9
#define W5500_INIT1_GPIO_Port GPIOE
#define SPI4_NSS_Pin GPIO_PIN_11
#define SPI4_NSS_GPIO_Port GPIOE
#define LINKLED1_Pin GPIO_PIN_15
#define LINKLED1_GPIO_Port GPIOE
#define W5500_RST2_Pin GPIO_PIN_10
#define W5500_RST2_GPIO_Port GPIOB
#define W5500_INIT2_Pin GPIO_PIN_11
#define W5500_INIT2_GPIO_Port GPIOB
#define SPI2_NSS_Pin GPIO_PIN_12
#define SPI2_NSS_GPIO_Port GPIOB
#define LINKLED2_Pin GPIO_PIN_10
#define LINKLED2_GPIO_Port GPIOD
#define P_D2_Pin GPIO_PIN_2
#define P_D2_GPIO_Port GPIOG
#define P_D3_Pin GPIO_PIN_3
#define P_D3_GPIO_Port GPIOG
#define P_D4_Pin GPIO_PIN_4
#define P_D4_GPIO_Port GPIOG
#define P_D5_Pin GPIO_PIN_5
#define P_D5_GPIO_Port GPIOG
#define P_D6_Pin GPIO_PIN_6
#define P_D6_GPIO_Port GPIOG
#define P_D7_Pin GPIO_PIN_7
#define P_D7_GPIO_Port GPIOG
#define P_D8_Pin GPIO_PIN_8
#define P_D8_GPIO_Port GPIOG
#define PPS_Pin GPIO_PIN_1
#define PPS_GPIO_Port GPIOD
#define MPS1_Pin GPIO_PIN_2
#define MPS1_GPIO_Port GPIOD
#define MPS2_Pin GPIO_PIN_3
#define MPS2_GPIO_Port GPIOD
#define PA_Pin GPIO_PIN_4
#define PA_GPIO_Port GPIOD
#define FASTLOCK_Pin GPIO_PIN_7
#define FASTLOCK_GPIO_Port GPIOD
#define P_D9_Pin GPIO_PIN_9
#define P_D9_GPIO_Port GPIOG
#define P_D10_Pin GPIO_PIN_10
#define P_D10_GPIO_Port GPIOG
#define P_D11_Pin GPIO_PIN_11
#define P_D11_GPIO_Port GPIOG
#define P_D12_Pin GPIO_PIN_12
#define P_D12_GPIO_Port GPIOG
#define P_D13_Pin GPIO_PIN_13
#define P_D13_GPIO_Port GPIOG
#define P_D14_Pin GPIO_PIN_14
#define P_D14_GPIO_Port GPIOG
#define P_D15_Pin GPIO_PIN_15
#define P_D15_GPIO_Port GPIOG
#define S_CLK_Pin GPIO_PIN_8
#define S_CLK_GPIO_Port GPIOB

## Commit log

2022-06-16 保存进度
    [WS7.820.438.V01.PrjPCB, WSPS-325-150K-PEFA驱动插件接线图.PrjPCB]
2022-06-27 功放插件程序固定
    [WS7.820.431.V01.PrjPCB]
2022-07-07 添加了readme.md
2022-07-16 进度保存
    [WSPS-325-150K-PEFA驱动插件接线图2.SchDoc]

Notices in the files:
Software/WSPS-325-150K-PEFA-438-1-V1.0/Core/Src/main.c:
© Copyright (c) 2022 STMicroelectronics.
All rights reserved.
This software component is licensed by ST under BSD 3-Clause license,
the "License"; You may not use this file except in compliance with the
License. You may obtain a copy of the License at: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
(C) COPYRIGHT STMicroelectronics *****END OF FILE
